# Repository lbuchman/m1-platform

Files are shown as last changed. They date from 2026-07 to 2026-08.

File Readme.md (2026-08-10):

# M1 Platform

This repository is the root repository for the M1 embedded manufacturing test platform.

The root repository does not replace the component repositories. It documents and organizes them so the full platform can be cloned, set up, released, and recovered as one system.

## Top-Level Directory Structure

| Directory | Purpose |
| --- | --- |
| `artifacts/` | Build output (snaps, firmware images, manifest) produced by `scripts/build.sh`. |
| `components/` | Independently git-tracked component repos (`m1tfc`, `m1testBoardFw`, `acm-testboard-fw`, `stm32mp1-baremetal`, `m1-rest-server`, `m1-operator-ui`), populated via `scripts/clone-components.sh`. |
| `documentation/` | Controlled documentation baseline: architecture, hardware, assembly, operations, validation, sustainment, and cloud-deployment docs. |
| `provision-new-pc/` | Fixture PC provisioning and deployment tooling (`setup.sh`, `deploy.sh`, required inputs). |
| `scripts/` | Automation scripts: build, clone/update components, publish firmware, program Teensy boards. |

## Build PC Software Requirements

Ubuntu is required for development — other OSes (macOS, Windows, WSL, other Linux distros) are not
supported for building or running this platform's build/deploy tooling. Ubuntu 26.04 LTS is recommended.
See [documentation/BuildPC/Readme.md](documentation/BuildPC/Readme.md) for the exact release and required
software: Ubuntu packages, Node, Snapcraft, VS Code/PlatformIO, and the Arm toolchain.

## Build the Platform

From the repository root, after cloning components (see [Bootstrap Components](#bootstrap-components) below):

```bash
./scripts/build.sh build
```

Builds all firmware and all snaps, staging artifacts in `artifacts/` alongside `manifestFile.json`.

## Fixture PC Deployment Guide

See [provision-new-pc/Readme.md](provision-new-pc/Readme.md) for fixture deployment instructions, required inputs, examples, and troubleshooting.

## Firmware Publishing

See [scripts/publish-fw.md](scripts/publish-fw.md) for publishing firmware/snap artifacts to Azure Blob storage.

## Bootstrap Components

After cloning the platform root, populate `components/` with split repositories:

```bash
./scripts/clone-components.sh
```

See [scripts/Readme.md](scripts/Readme.md) for update/dry-run options and the rest of the automation scripts.

## Components

| Component | Repo | Local Path | Purpose |
| --- | --- | --- | --- |
| M1TFC | `git@github.com:lbuchman/m1tfc.git` | `components/m1tfc` | Fixture CLI, ICT, functional tests, hardware orchestration |
| M1 fixture Teensy firmware | `git@github.com:lbuchman/m1testBoardFw.git` | `components/m1testBoardFw` | Teensy 4.1 firmware for M1 fixture boards |
| ACM test board firmware | `git@github.com:lbuchman/acm-testboard-fw.git` | `components/acm-testboard-fw` | PlatformIO Teensy firmware for ACM test board, aligned to the `redDiamondsFixture/teensy` skeleton |
| STM32MP1 bare-metal ICT firmware | `git@github.com:lbuchman/stm32mp1-baremetal.git` | `components/stm32mp1-baremetal` | Bare-metal STM32MP1 firmware for ICT, including SDRAM test coverage unavailable when Linux owns the target |
| REST server | `git@github.com:lbuchman/m1-rest-server.git` | `components/m1-rest-server` | REST API around fixture commands and status |
| Operator UI | `git@github.com:lbuchman/m1-operator-ui.git` | `components/m1-operator-ui` | React production/debug operator interface |

## Production Snaps

These platform components are production snap packages:

| Component | Local Path | Snap Packaging |
| --- | --- | --- |
| M1TFC | `components/m1tfc` | `components/m1tfc/snap/snapcraft.yaml` |
| REST server | `components/m1-rest-server` | `components/m1-rest-server/snap/snapcraft.yaml` |
| Operator UI | `components/m1-operator-ui` | `components/m1-operator-ui/snap/snapcraft.yaml` |

Production snap packages should use Node 24.

## Platform Snap Builds

See [scripts/Readme.md](scripts/Readme.md#buildsh-usage) for full `build.sh` firmware/snap target usage and options.

## Fast Smoke Test Checklist

Run the post-install and pre-release smoke checks in:

- [documentation/Validation/fast-smoke-test-checklist.md](documentation/Validation/fast-smoke-test-checklist.md)

## Platform Firmware Builds

See [scripts/Readme.md](scripts/Readme.md#buildsh-usage) for full `build.sh` firmware/snap target usage and options.

### Program Teensy Boards

Upload prebuilt firmware from `artifacts/` to a Teensy board over USB with
`scripts/prog-teensy.sh`:

```bash
./scripts/prog-teensy.sh acm     # upload artifacts/acmfirmware.hex to the ACM test board
./scripts/prog-teensy.sh m1tb    # upload artifacts/m1firmware.hex to the M1 fixture board
```

This script does not build firmware; run `scripts/build.sh build acm` or
`scripts/build.sh build fixture` first to refresh the artifact. Recheck the
connected board identity before programming.

### STM32MP1 ICT Firmware

See [documentation/BuildPC/STM32MP1-ICT-FIRMWARE.md](documentation/BuildPC/STM32MP1-ICT-FIRMWARE.md) for build requirements and FSBL build/output details.

## Repository Layout

- Repository root: this directory.
- Component repositories: `components/` (relative to repository root), populated by `scripts/clone-components.sh`.

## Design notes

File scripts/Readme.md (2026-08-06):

# Scripts

Automation used to bootstrap, build, program, and publish the M1 platform.

| Script | Purpose |
| --- | --- |
| `build.sh` | Builds firmware (`acm`, `fixture`, `stm32mp1`) and platform Snaps (`m1tfc`, `m1-rest-server`, `m1-operator-ui`, `m1-fixture-agent`); stages artifacts and `manifestFile.json` in `artifacts/`. |
| `check-dirty-components.sh` | Reports Git cleanliness (clean/dirty/not-git) for each repo under `components/`. |
| `clone-components.sh` | Clones all split `components/*` repos via SSH (falls back to HTTPS); `--update` fast-forwards existing clones. |
| `install-snaps.sh` | Copies built snaps from `artifacts/` to a remote host via `scp` and installs them there via `ssh`. |
| `installstm32fsbl.sh` | Copies the built STM32MP1 ICT FSBL (`artifacts/stm32mp1_fsbl.stm32`) to `/var/m1mtf/fsbl.stm32` on a remote host. |
| `prog-teensy.sh` | Uploads prebuilt Teensy firmware (`acmfirmware.hex` or `m1firmware.hex`) to a board over a remote host's `teensy_loader_cli`. |
| `publish-fw.sh` | Uploads firmware, snap, and manifest artifacts from `artifacts/` to Azure Blob storage. |
| `update-components.sh` | Fast-forward pulls already-cloned `components/*` repos without re-cloning; supports `--component` and `--dry-run`. |

Run any script with `-h`/`--help` (where supported) for full usage and options.

## build.sh Usage

Build firmware and stage artifacts:

```bash
./scripts/build.sh build acm        # build ACM firmware
./scripts/build.sh build fixture     # build M1 fixture Teensy firmware
./scripts/build.sh build stm32mp1    # build STM32MP1 ICT FSBL
./scripts/build.sh build firmware    # build all firmware components
./scripts/build.sh build all         # build all firmware and all snaps
```

Build snap packages the same way:

```bash
./scripts/build.sh build m1tfc            # build m1tfc snap only
./scripts/build.sh build m1-rest-server   # build m1-rest-server snap only
./scripts/build.sh build m1-operator-ui   # build m1-operator-ui snap only
./scripts/build.sh build m1-fixture-agent # build m1-fixture-agent snap only
./scripts/build.sh build snaps            # build all snaps
```

Build artifacts are copied to `artifacts/` directly, alongside a
`build-manifest.txt` containing the source commit and dirty/clean state.
Use `--output-dir PATH` to select another artifact directory, `--update` for
fast-forward-only git updates from current remotes, or `--dry-run` to inspect
a command without building, installing, or programming hardware.

`build fixture` compiles `components/m1testBoardFw` with PlatformIO
(`pio run --environment teensy41`) and stages the resulting `.hex` as
`artifacts/m1firmware.hex`.

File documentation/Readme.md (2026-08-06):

# EVM Platform Documentation v1.2

This package is the controlled documentation baseline for the M1/MNPlus Unified Engineering, Validation and Manufacturing Platform (EVM).

## Included formal documents

- EVM Platform Overview
- EVM Platform Capabilities
- EVM Hardware Architecture
- Engineering vs Production Configurations
- M1 Test Board Hardware Specification
- ACM Controller Test Board Hardware Specification
- Production Fixture Assembly Guide
- EVM Twenty-Year Sustainment Plan
- M1 Operator UI Guide (`Operations/`)
- Fast Smoke Test Checklist (`Validation/`)
- Cloud deployment documentation, including board firmware storage / Azure `firmware` container contents (`Cloud-Deployment/`)

## Included engineering sources

- EVM architecture diagram image and draw.io source (`Architecture/Platform/Source-Diagrams/`)
- Current fixture design review diagram (`Architecture/Platform/Source-Diagrams/mnplus_design_review_v3.drawio`)
- Engineering bench photograph, production fixture photographs, and all document-extracted images (`Images/`)
- M1 Test Board and ACM Controller Test Board schematic PDFs (`Architecture/Hardware/*/Source-Schematics/`)
- M1-3200 and MNPlus-V3 UUT (product-under-test) reference schematics (`Architecture/Hardware/UUT-Reference/`)
- Full architecture authoring context (`Architecture/Platform/Context/`)

## Repository layout

```text
documentation/
├── Architecture/
│   ├── Platform/
│   │   ├── 01_EVM_Platform_Overview.md
│   │   ├── 02_EVM_Platform_Capabilities.md
│   │   ├── 03_EVM_Hardware_Architecture.md
│   │   ├── 04_Engineering_vs_Production_Configurations.md
│   │   ├── Context/            (full architecture authoring context)
│   │   └── Source-Diagrams/    (draw.io sources)
│   ├── Hardware/
│   │   ├── M1-Test-Board/                  (spec + Source-Schematics/)
│   │   ├── ACM-Controller-Test-Board/   (aka ACM Board; spec + Source-Schematics/)
│   │   └── UUT-Reference/                  (M1-3200, MNPlus-V3 product schematics)
│   ├── Firmware/    (reserved)
│   └── Software/    (reserved)
├── Assembly/        (Production Fixture Assembly Guide)
├── Manufacturing/   (reserved)
├── Operations/      (operator UI guide)
├── Validation/      (fast smoke test checklist)
├── Sustainment/     (Twenty-Year Sustainment Plan)
├── Cloud-Deployment/ (cloud deployment docs: Azure storage containers, and other cloud files used by the platform)
├── Interface-Control-Documents/  (reserved: pogo-pin maps, IDC interface spec, reader interfaces)
└── Images/          (all diagrams/photos/document-extracted images)
```

## Scope note

The current package covers platform, hardware, assembly, operations, validation, and sustainment documentation. Detailed firmware, software, manufacturing release, and interface-control documents have reserved repository locations for future development.

The production fixture is one implementation of the broader EVM platform. The engineering bench and production fixture use the same core architecture with different mechanical and interface layers.

`Interface-Control-Documents/` was named out in full (rather than the `ICD` abbreviation) to avoid confusion with `IDC` (Insulation Displacement Connector), a distinct, frequently referenced term in the same interface documents.

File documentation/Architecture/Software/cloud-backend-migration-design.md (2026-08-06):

# Factory Server Migration: Azure Blob Storage → Local On-Prem Server

## Goal

Replace the current Azure Blob Storage based system (`tfcroncli`/`m1client` on the fixture, `scripts/publish-fw.sh` for admins) with a **local, on-prem physical PC in the factory** ("Factory Server") that the team fully controls. This is a hard requirement, not just a preference: production lines must be **self-contained** and must keep running even if internet/cloud connectivity is down — nothing on the primary production path (logs, secrets, firmware updates, MAC allocation) may depend on reaching the internet. The new backend must:

1. Store logs, retrievable **by board serial number** (today only retrievable by date-prefix/fixture).
2. Store secrets, retrievable **by board serial number** (same limitation today).
3. Host firmware/software releases; fixtures poll and self-update (replaces the `firmware` blob container + `manifestFile.json`).
4. Centrally manage MAC address allocation (replaces the static, offline `STARTMAC` block-per-fixture formula in `setup.sh`).
5. Provide a web app to browse all of the above.
6. Run entirely on the factory LAN — Azure Blob Storage is retained only as an **off-site daily backup target** (disaster recovery), never on the critical path for production.
7. Keep test fixture PCs **stateless/thin clients** — since the Factory Server now owns the only database, fixtures no longer need a local database at all. Board test results, secrets, and MAC assignment are written directly and immediately to `m1-factory-hub` over the LAN instead of being staged in a local SQLite DB and synced later by cron.

## Naming

Recommended service name: **`m1-factory-hub`**. "Factory Server" refers to the physical on-prem PC (the hardware); `m1-factory-hub` is the Node/Express service that runs on it, following the existing `m1-<role>` naming convention (`m1-rest-server`, `m1-operator-ui`). "Hub" reflects its role as the single central point every fixture talks to for logs, secrets, firmware, and MAC allocation. Alternatives considered: `m1-mes-server` (accurate — this is effectively a small Manufacturing Execution System — but a less familiar term), `m1-depot` (evokes storage but undersells the MAC-allocation/coordination role). The rest of this doc uses `m1-factory-hub`.

## Current State (for reference)

| Concern | Current mechanism |
| --- | --- |
| Logs | Fixture cron (`m1client synclogs`) uploads `.txz` archives to `<product>-logs-<site>` Azure container. Retrieval only by date-prefix, no serial index. |
| Secrets | Fixture cron (`m1client syncsecrets`) uploads a CSV of RSA-encrypted, base32-encoded secrets to `<product>-secrets` container. |
| Firmware | Admin tool `scripts/publish-fw.sh` pushes files + `manifestFile.json` to `firmware` container; fixture cron (`m1client update`) polls and downloads. |
| DB backup | Fixture cron (`m1client backupdb`) uploads SQLite `tf.db` to `backup` container. |
| MAC addresses | `setup.sh` computes a static `58:FC:C8:%02X:%02X:%02X` block per fixture from `idx * 1_000_000`, seeded once into the local `UID` table at provisioning. No central registry, no collision detection. |

## `deployment` Container Contract (Azure Blob, current interim mechanism)

Manual firmware releases are staged in the `deployment` Azure Blob container ahead of the on-prem migration above. This container **MUST** contain, at minimum:

- `stm32mp15-lenels2-m1.txz` — M1 firmware image archive.
- `stm32mp15-lenels2-mnp.txz` — MNP firmware image archive.
- `manifestFile.json` — SAS URLs and SHA-512 hashes for both archives above (`m1firmware` / `mnpfirmware` entries).

Each `.txz` archive **MUST** contain, at its root, a `VERSION` file — plain text, exactly **1 line**, containing the Artifactory-reported build revision string. Example:

  ```
  1.0.16 179 09/22/23 02eef93c27 M1B SandboxHost-638309047983092644
  ```

  Format: `<version> <build number> <build date MM/DD/YY> <short commit sha> <product> <build host>`.

## Proposed Architecture

```mermaid
flowchart LR
    classDef fixture fill:#eef3ff,stroke:#3367d6,color:#1a237e;
    classDef vm fill:#fff6e8,stroke:#e65100,color:#5d3a00;
    classDef admin fill:#eaf7ec,stroke:#2e7d32,color:#1b3d1f;
    classDef cloud fill:#f3e8ff,stroke:#6a1b9a,color:#3a1a5d;

    subgraph LAN["Factory LAN (no internet dependency for production)"]
        subgraph FIX["Test Fixture PCs (stateless — no local DB)"]
            MTFC["m1tfc<br/>(test execution — calls Hub in real time\nfor boards / secrets / mac allocate)"]:::fixture
            TFC["tfcroncli / m1client<br/>(cron: update only)"]:::fixture
            SSH1["autossh"]:::fixture
        end

        subgraph SRV["Factory Server (on-prem PC) — m1-factory-hub"]
            API["m1-factory-hub (Express REST API)"]:::vm
            MYSQL[("MySQL: boards, logs, secrets,\nmac_allocations, firmware_releases")]:::vm
            FS[("Filesystem: /data/logs, /data/firmware,\n/data/secrets, /data/backups")]:::vm
            WEB["Web dashboard (React)"]:::vm
            BKUP["daily backup job<br/>(mysqldump + tar, conditional)"]:::vm
            SSH2["autossh"]:::vm
            API --- MYSQL
            API --- FS
            WEB -->|REST| API
            BKUP --- MYSQL
            BKUP --- FS
        end

        subgraph ADMIN["Engineer workstation"]
            CLI["scripts/publish-fw.sh<br/>publish firmware/snap artifacts"]:::admin
        end

        MTFC -->|HTTPS + API key, LAN only\nreal-time board/secret/mac calls| API
        TFC -->|HTTPS + API key, LAN only\nfirmware update poll| API
        CLI -->|HTTPS + API key, LAN only| API
    end

    AZURE[("Azure Blob Storage<br/>off-site DR backup only")]:::cloud
    RELAY[("External relay server")]:::cloud

    BKUP -.->|daily, only if changed,\nvia existing access key| AZURE
    SSH1 -.->|reverse SSH tunnel\n(remote support access)| RELAY
    SSH2 -.->|reverse SSH tunnel\n(remote support access)| RELAY
```

The reverse-SSH-via-relay pattern already exists on every test fixture PC (`autossh` service, restarted on boot via cron — see `setup.sh`) purely for remote engineering/support access; it carries no production data and is independent of the `m1-factory-hub` REST path and the Azure backup path. The Factory Server should get the same `autossh` service for the same reason (remote troubleshooting), not because production depends on it.

Because fixtures now depend on `m1-factory-hub` being reachable *during* live test execution (not just for periodic batch sync), the Factory Server effectively becomes a production-critical LAN service. This is a reasonable trade for the simplicity gained (see Open Decisions for reliability/retry considerations).

## Factory Server Components

### Database: MySQL

MySQL (InnoDB) replaces Postgres per your preference. Suggested schema:

```sql
CREATE TABLE boards (
  serial          VARCHAR(64) PRIMARY KEY,
  product         VARCHAR(32) NOT NULL,
  mac             VARCHAR(17) UNIQUE,
  fixture         VARCHAR(32),
  status          VARCHAR(32) DEFAULT 'active',
  created_at      DATETIME DEFAULT CURRENT_TIMESTAMP,
  updated_at      DATETIME DEFAULT CURRENT_TIMESTAMP ON UPDATE CURRENT_TIMESTAMP
) ENGINE=InnoDB;

CREATE TABLE logs (
  id              BIGINT AUTO_INCREMENT PRIMARY KEY,
  board_serial    VARCHAR(64) NOT NULL,
  fixture         VARCHAR(32) NOT NULL,
  file_path       VARCHAR(512) NOT NULL,
  file_hash       CHAR(128) NOT NULL,
  size_bytes      BIGINT,
  uploaded_at     DATETIME DEFAULT CURRENT_TIMESTAMP,
  FOREIGN KEY (board_serial) REFERENCES boards(serial),
  INDEX idx_logs_serial (board_serial)
) ENGINE=InnoDB;

CREATE TABLE secrets (
  board_serial      VARCHAR(64) PRIMARY KEY,
  uid               VARCHAR(64) NOT NULL,
  encrypted_secret  TEXT NOT NULL,
  fixture           VARCHAR(32),
  synced_at         DATETIME DEFAULT CURRENT_TIMESTAMP,
  FOREIGN KEY (board_serial) REFERENCES boards(serial)
) ENGINE=InnoDB;

CREATE TABLE mac_allocations (
  mac             VARCHAR(17) PRIMARY KEY,
  board_serial    VARCHAR(64) UNIQUE,
  fixture         VARCHAR(32),
  status          ENUM('available','reserved','assigned') DEFAULT 'available',
  allocated_at    DATETIME NULL
) ENGINE=InnoDB;

CREATE TABLE firmware_releases (
  id              BIGINT AUTO_INCREMENT PRIMARY KEY,
  version         VARCHAR(32) NOT NULL,
  product         VARCHAR(32) NOT NULL,
  filetype        VARCHAR(16) NOT NULL,
  filename        VARCHAR(255) NOT NULL,
  file_hash       CHAR(128) NOT NULL,
  published_at    DATETIME DEFAULT CURRENT_TIMESTAMP,
  UNIQUE KEY uniq_release (version, product, filetype)
) ENGINE=InnoDB;
```

Note: no `db_backups` table is needed anymore — there is no per-fixture local database left to back up. The `boards` table itself (with test-result columns such as `ict_passed`, `functional_passed`, `flash_programmed`, mirroring today's local `records` table) *is* the durable store now, and it lives only on the Factory Server, covered by the single off-site backup job described below.

`mysql2` (Node driver, promise support built in) on the Factory Server only — fixtures never talk to MySQL directly, only through the `m1-factory-hub` REST API.

### File storage

Plain filesystem on the Factory Server (`/data/logs/<serial>/...`, `/data/firmware/<product>/<version>/...`, `/data/backups/<fixture>/...`), indexed by the MySQL rows above. No need for MinIO/S3-compatible layers at this scale — it adds an extra moving part for no real benefit here.

### REST API (`m1-factory-hub`, Express — new component, e.g. `components/m1-factory-hub`)

| Method | Endpoint | Purpose |
| --- | --- | --- |
| POST | `/api/logs` | Fixture uploads a log archive tagged with `serial`, `fixture`, timestamp. |
| GET | `/api/logs?serial=` | List/download logs for a board. |
| POST | `/api/secrets` | Fixture uploads an (already RSA-encrypted) secret record for a board. |
| GET | `/api/secrets?serial=` | Retrieve a board's secret record. |
| POST | `/api/mac/allocate` | Fixture/`setup.sh` requests the next free MAC; server allocates atomically and marks it `assigned`. |
| GET | `/api/mac?serial=` | Look up a board's assigned MAC. |
| GET | `/api/firmware/manifest?product=` | Replaces Azure `manifestFile.json` fetch — fixture's `update` command polls this. |
| GET | `/api/firmware/:file` | Download a firmware/snap file. |
| POST | `/api/firmware` | Admin publishes a new release (replaces `scripts/publish-fw.sh`). |
| POST | `/api/boards` | `m1tfc` records/updates a board's test result in real time (ICT/functional pass, flash programmed, etc.) — replaces the local `records` table. |
| GET | `/api/boards?serial=` | Look up a board's current test/status record (e.g., to resume or re-test). |
| GET | `/health` | Health check (same base-response contract pattern already used in `m1-rest-server`). |

### Auth

The Factory Server sits on the same factory LAN as the fixtures, so there's no public domain/Let's Encrypt concern here. Recommended default: HTTPS with a self-signed cert (or a small internal CA) issued once and distributed to fixtures via `setup.sh` (`update-ca-certificates`), plus a per-fixture API key issued at provisioning time, sent as `Authorization: Bearer <key>`. TLS is still worthwhile even on a trusted LAN (defense in depth for the secrets endpoint); plain HTTP is not recommended. A static hostname/IP for the Factory Server (e.g. `factory-server.local` via mDNS, or a fixed LAN IP) should be baked into fixture config at provisioning time.

### Web app

Reuse the existing pattern (`m1-operator-ui`: React/Vite, talking to an Express REST layer) rather than a new stack: search by board serial → logs, secret-sync status, MAC, firmware history; plus an admin view for firmware releases and the MAC pool. Runs on the Factory Server itself, accessible from any PC on the factory LAN.

## Off-Site Backup to Azure Blob Storage

Azure Storage is **not** part of the operational path anymore — it is only a daily, best-effort, off-site disaster-recovery copy, using the access key already held. Production continues normally even if this fails or if internet access is temporarily down.

- **What**: a `mysqldump` of the MySQL database + a tarball of `/data` (logs/secrets/firmware/backups), run once daily on the Factory Server itself (not on individual fixtures).
- **Conditional upload**: track a watermark (e.g. `MAX(updated_at)` across the relevant tables, or a hash of the dump) from the last successful backup; skip the upload entirely if nothing changed since then, to avoid needless daily transfers.
- **Isolation from the app code**: implement this as a standalone ops script (bash + `mysqldump` + `azcopy` or `az storage blob upload-batch`), run via a systemd timer/cron on the Factory Server — kept entirely separate from the Node REST API. This keeps the application code itself fully vendor-neutral; only this one backup script touches Azure, using the existing storage account access key (e.g. a dedicated `factory-backup` container).
- **Restore path**: download the latest dump/tarball from Azure and restore `mysqldump` + extract `/data` onto a replacement Factory Server.

## Remote Support Access (autossh reverse SSH)

Separate from both the production data path and the Azure backup path: every test fixture PC already runs an `autossh` service that opens a reverse SSH tunnel to an external relay server, giving engineers remote shell access for troubleshooting (already implemented, restarted on boot via the existing `@reboot sleep 120 && systemctl restart autossh` cron entry in `setup.sh`). The Factory Server should run the same `autossh` service against the same relay, for the same reason — remote support access if on-site visits aren't practical. This channel carries no logs/secrets/firmware/MAC traffic and has no bearing on the self-contained-production requirement; it's purely an admin convenience.

## Test Fixture PC Software Changes

The fixture host already runs Ubuntu Server + Node.js (via the `m1client`/`tfcroncli` snap) and needs no new system-level packages for this migration — just dependency and config changes:

| Area | Change |
| --- | --- |
| `tfcroncli/app/package.json` | Remove `azure-storage`, `@azure/storage-blob`. No new HTTP dependency needed — Node 20+ (already the baseline per `m1-rest-server`'s `engines`) has built-in `fetch`, `FormData`, and `Blob`, sufficient for multipart uploads/downloads. |
| `azureOp.js` | Replaced by a new `httpOp.js` with the same exported function shapes (`syncFiles`, `checkFilesHash`, `getHash512FromFile` — the hash helper is pure local logic and doesn't change) so `m1client.js`'s command bodies barely change, just the transport underneath. |
| `better-sqlite3` (and the local `tf.db`/`records`/`UID`/`Perm` schema) | **Removed entirely.** No local database on the fixture at all — `m1tfc` calls `m1-factory-hub` directly for board test-result records, secret submission, and MAC allocation instead of writing to local SQLite and syncing later. This also drops a native module (`better-sqlite3` requires compilation) from every fixture install. |
| `m1tfc` (test executor, `components/m1tfc`) | Bigger change than `tfcroncli`: the code that used to read/write the local `records`/`UID` tables now calls `m1-factory-hub`'s `/api/boards`, `/api/secrets`, and `/api/mac/allocate` synchronously during the test sequence. Needs basic retry/backoff around these calls since the Hub is now a live dependency during test execution, not just a periodic sync target. |
| `crypto` (RSA), `winston`, `fs-extra`, `glob`, `mkdirp`, `date-and-time`, `lodash` | Unchanged — encryption and logging stay exactly as they are today. |
| TLS trust | The Factory Server will use a self-signed cert or small internal CA (no public domain on a factory LAN). `setup.sh` needs a step to install that CA into each fixture's system trust store (`update-ca-certificates`). |
| MySQL client | **Not needed** on the fixture — all DB access is server-side only, fixtures only ever call the REST API. |
| cron schedule | `tfcroncli`/`m1client` shrinks to just `update` (firmware polling). `synclogs`, `syncsecrets`, `backupdb` and their log-retention `find`/`delete` jobs are all removed — there's no local state left to batch-sync since logs/secrets/board records now push in real time from `m1tfc` itself. |
| `setup.sh` MAC provisioning | Removed entirely — no `STARTMAC`/`idx * 1_000_000` block calculation, no local `UID` table to seed. MACs are requested per-board, at programming time, directly from `m1-factory-hub`. |
| Package footprint | Net reduction — dropping the Azure SDKs *and* `better-sqlite3` removes two fairly heavy/native dependency trees from every fixture install. |

## Migration Plan (staged)

1. Procure/set up the Factory Server (physical PC on the factory LAN) with MySQL + `m1-factory-hub` + filesystem storage, and the same `autossh` remote-support service already used on fixtures; implement and test all endpoints above in isolation.
2. Add `httpOp.js` to `tfcroncli` for firmware `update` (behind the same interface as `azureOp.js`), and add the direct `m1tfc` → `m1-factory-hub` calls for boards/secrets/mac-allocate (replacing the local `records`/`UID` table reads/writes in `m1tfc`). Update `config.json`/`setup.sh` to point at the Factory Server's LAN address. Pilot on one fixture before wider rollout.
3. Cut fixtures over fixture-by-fixture (`update` retargeted; local SQLite removed; `m1tfc` now calls the Hub directly).
4. Move MAC allocation to the central API last — highest process risk. Consider registering existing static allocations into `mac_allocations` first (for visibility) before fixtures start requesting *new* MACs from the pool.
5. Stand up the daily conditional Azure backup job on the Factory Server (independent ops script, see below).
6. Historical Azure data and existing local `tf.db` records: import into the Factory Server's MySQL as a one-time migration, or leave archived — no need to block the cutover on this.

## Open Decisions

- **Auth model**: API key over HTTPS with a self-signed/internal CA (recommended default above), or mutual TLS client certs?
- **Factory Server addressing**: fixed LAN IP vs. mDNS/local hostname — which is already standard practice on this network?
- **MAC cutover**: keep the static per-fixture formula as an offline fallback (e.g. if the Factory Server is briefly down for maintenance), or make Factory Server reachability a hard requirement for `setup.sh`/provisioning to complete?
- **Historical data**: import existing Azure blob data (and existing local `tf.db` records) into the new system, or leave archived as-is?
- **Backup retention**: how many days/versions of the daily Azure backup to retain before pruning older ones?
- **Test-time reliability**: since fixtures now depend on `m1-factory-hub` being up *during* live testing (no local DB fallback), what retry/backoff policy should `m1tfc` use on a transient failure, and should the Factory Server run on a UPS/have any redundancy given it's now production-critical?

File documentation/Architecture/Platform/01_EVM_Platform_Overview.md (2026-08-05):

**EVM Platform Overview**

*Unified Engineering, Validation and Manufacturing Platform*

Version 1.0 \| July 25, 2026\
Owner: Leo Buchman\
Status: Initial controlled draft

  -------------------------------------------------------------------------------------------
  Document Type                       Platform Overview
  ----------------------------------- -------------------------------------------------------
  Platform                            M1/MNPlus EVM

  Scope                               Hardware / architecture

  Source Baseline                     Schematics, platform diagram, physical configurations
  -------------------------------------------------------------------------------------------

# 1. Purpose

The M1/MNPlus EVM is a reusable platform that supports engineering development, hardware-in-the-loop validation, QA, manufacturing, provisioning, recovery, failure analysis, and technical support. The production fixture is one deployment of the platform; the underlying architecture is broader than a product-specific tester.

# 2. Platform Outcomes

- Common engineering and production infrastructure

- Repeatable hardware, firmware, and software validation

- Serial, USB, Ethernet, RS-485, OSDP, Wiegand, and PoE test access

- Programming, provisioning, recovery, and regeneration

- Reusable M1 and ACM simulation subsystems

- Cloud-connected updates, diagnostics, logs, secrets, and remote support

# 3. System Architecture

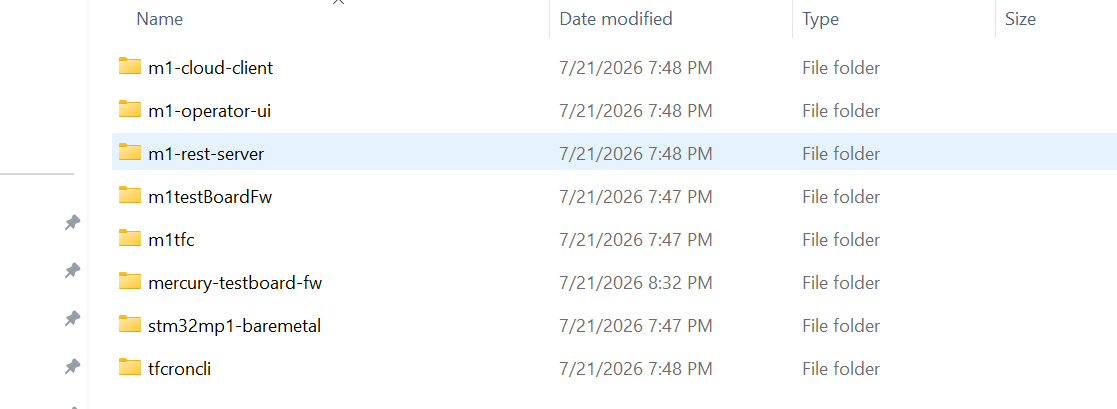
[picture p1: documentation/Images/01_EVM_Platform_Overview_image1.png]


*Figure 1 - EVM platform architecture (current system-level view)*

# 4. Major Subsystems

  ---------------------------------------------------------------------------------------------------------------------------------------------------
  **Subsystem**                       **Primary responsibility**
  ----------------------------------- ---------------------------------------------------------------------------------------------------------------
  Headless PC                         React operator UI, REST control services, Node.js test execution, cloud and recovery services

  M1 Test Board                       M1-scope control, programming, recovery, measurements, boot selection, and product interface

  ACM Controller Test Board       ACM/ACM simulation: readers, supervised inputs, relay/output validation, tamper and power-fault functions

  SAM-E Ethernet Subsystem            Local three-port Ethernet switching for test and PoE paths

  Power / PoE Subsystem               12.5 V and 5 V fixture rails plus switched 48 V PoE delivery

  Product Interface                   Direct IDC/terminal-block engineering access or product-specific production plate and pogo-pin mapping
  ---------------------------------------------------------------------------------------------------------------------------------------------------

# 5. Supported Lifecycle Uses

  -------------------------------------------------------------------------------------------------------------------
  **Lifecycle phase**                 **Representative uses**
  ----------------------------------- -------------------------------------------------------------------------------
  Engineering                         Bring-up, firmware/software development, debug, direct signal access

  QA / Validation                     Automated regression, HIL, serial and Ethernet testing

  Manufacturing                       Programming, provisioning, configuration, qualification, pass/fail validation

  Sustaining / Support                Recovery, regeneration, failure analysis, diagnostics, remote assistance
  -------------------------------------------------------------------------------------------------------------------

# 6. Engineering and Production Deployments

The platform uses the same core architecture in two physical configurations. The engineering configuration favors direct access and flexibility. The production configuration favors repeatability, speed, and operator simplicity.

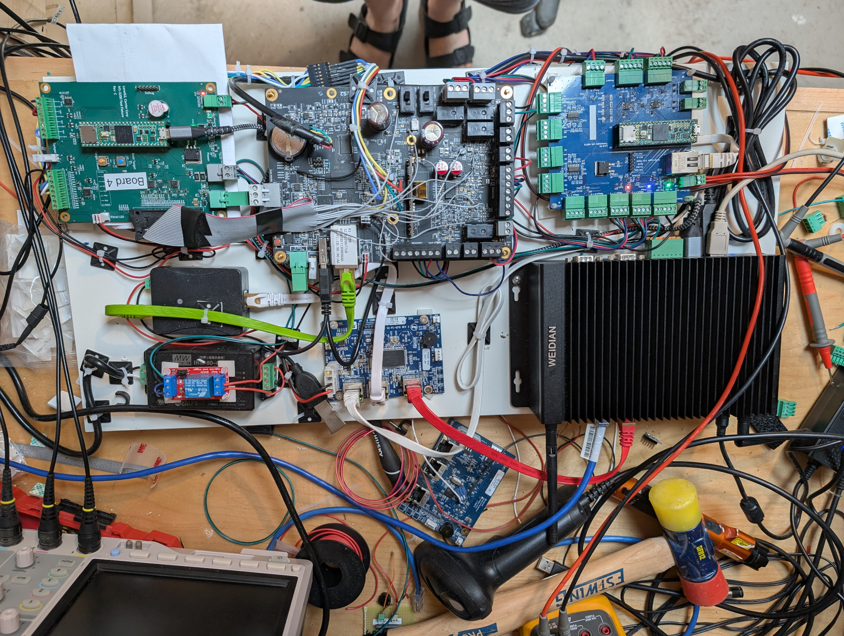
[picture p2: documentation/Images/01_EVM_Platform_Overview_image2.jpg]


*Figure 2 - Engineering bench configuration with direct terminal-block and board access*

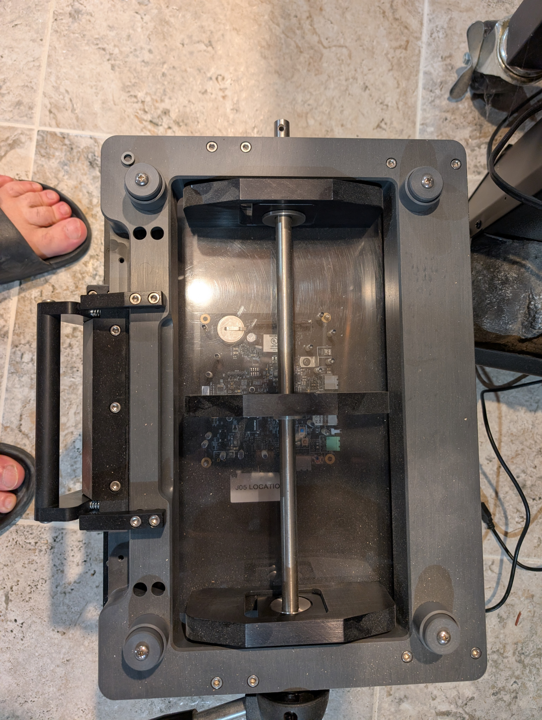
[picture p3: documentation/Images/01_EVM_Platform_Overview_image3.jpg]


*Figure 3 - Production fixture implementation with enclosed electronics and mechanical UUT interface*

# 7. Product Coverage

- M1 controller platform

- MNPlus platform, including the M1 and ACM functional scopes

- ACM controller families

- ACM door controllers

- ACM I/O expansion boards

- Elements end-to-end validation workflows

# 8. Document Map

- Platform Capabilities

- Hardware Architecture

- Engineering vs Production Configurations

- M1 Test Board Hardware Specification

- ACM Controller Test Board Hardware Specification

- Factory Production Fixture Assembly Guide

- Twenty-Year Sustainment Plan

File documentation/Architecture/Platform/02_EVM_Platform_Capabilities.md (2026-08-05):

**EVM Platform Capabilities**

*Capability baseline for engineering and manufacturing stakeholders*

Version 1.0 \| July 25, 2026\
Owner: Leo Buchman\
Status: Initial controlled draft

  -------------------------------------------------------------------------------------------
  Document Type                       Capability Specification
  ----------------------------------- -------------------------------------------------------
  Platform                            M1/MNPlus EVM

  Scope                               Hardware / architecture

  Source Baseline                     Schematics, platform diagram, physical configurations
  -------------------------------------------------------------------------------------------

# 1. Platform Capability Summary

- Unified Engineering, QA, Manufacturing, Recovery, and Technical Support Platform

- Hardware-in-the-Loop product validation and automation

- M1 and ACM functional simulation and validation

- Automated hardware, firmware, and software testing

- Ethernet, serial, USB, RS-485, OSDP, Wiegand, and PoE test infrastructure

- Firmware programming, provisioning, recovery, and regeneration

- Failure analysis, diagnostics, logs, and remote support

- React-based operator interface

- REST control services and Node.js automated test execution

- Common platform architecture supporting multiple products and product families

# 2. M1-Scope Capabilities

- M1 and MNPlus M1-subsystem validation

- Boot-target selection

- Target power control

- Serial-console and programming access

- Battery-related control and measurements

- Analog measurement and channel selection

- Tamper and product-interface access

- Direct IDC engineering connectivity

- Production pogo-pin connectivity through product-specific wiring

# 3. ACM / ACM-Scope Capabilities

- Dual OSDP reader simulation

- Dual Wiegand reader simulation

- Reader power, LED, and buzzer interaction

- Eight supervised-input simulation channels

- Relay/output activation validation

- Cabinet-tamper simulation

- Power-fault simulation

- ACM controller validation

- Door-controller validation

- I/O expansion-board validation

- End-to-end automated ACM ecosystem testing

# 4. Capability Versus Product Implementation

A product fixture exposes the subset of platform capabilities required by that product. M1 and MNPlus use different physical plates and pogo-pin maps. Broader ACM coverage requires a different plate, additional pogo-pin assignments, and additional wiring; the common ACM simulation electronics remain unchanged.

# 5. Known Capability Boundaries

- Exact supervised-input states must be confirmed from firmware and validation definitions

- Exact USB flash-drive use must be documented from implementation

- Product-specific pin maps belong in controlled ICDs and assembly drawings

- Detailed software, firmware, and operational procedures are separate documents

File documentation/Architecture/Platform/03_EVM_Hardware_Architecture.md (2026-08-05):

**EVM Hardware Architecture**

*System-level hardware decomposition and interfaces*

Version 1.0 \| July 25, 2026\
Owner: Leo Buchman\
Status: Initial controlled draft

  -------------------------------------------------------------------------------------------
  Document Type                       Hardware Architecture
  ----------------------------------- -------------------------------------------------------
  Platform                            M1/MNPlus EVM

  Scope                               Hardware / architecture

  Source Baseline                     Schematics, platform diagram, physical configurations
  -------------------------------------------------------------------------------------------

# 1. Scope

This document defines the physical hardware architecture of the EVM. Detailed software behavior, firmware internals, and operating procedures are excluded except where needed to explain interfaces.

# 2. Architecture Diagram



*Figure 1 - EVM hardware architecture*

# 3. Power Architecture

  ----------------------------------------------------------------------------------------------------------------
  **Source**              **Destination**                                 **Function**
  ----------------------- ----------------------------------------------- ----------------------------------------
  120 VAC                 12.5 V / 5 V supply                             Fixture/test electronics power

  12.5 V rail             M1 Test Board and associated test electronics   Controller and product-interface power

  5 V rail                SAM-E three-port Ethernet switch                Network subsystem power

  120 VAC                 48 V supply                                     PoE power source

  48 V supply             48 V relay                                      Controlled PoE enable path

  48 V relay              PoE injector                                    Switched 48 VDC

  PoE injector            UUT through product interface                   Ethernet plus power
  ----------------------------------------------------------------------------------------------------------------

# 4. Network and Service Architecture

- Headless PC provides Ethernet and USB control paths

- SAM-E provides local Ethernet switching

- ACM Controller Test Board participates in network-based testing

- PoE injector combines Ethernet and controlled 48 VDC

- USB hub exposes Teensy serial, DFU, and service-console paths

- Serial-based testing is a first-class validation path alongside Ethernet

# 5. Hardware Subsystem Responsibilities

  ---------------------------------------------------------------------------------------------------------------------------------------------------------------------
  **Subsystem**                       **Responsibilities**
  ----------------------------------- ---------------------------------------------------------------------------------------------------------------------------------
  M1 Test Board                       M1-scope control, target power, boot selection, measurements, programming/recovery, direct IDC and production interface support

  ACM Controller Test Board       Reader simulation, supervised-input simulation, relay/output validation, tamper/power-fault simulation

  SAM-E                               Three-port Ethernet switching and test-network distribution

  Fixture mechanics                   Product registration, compression, repeatable pogo-pin engagement, operator safety

  Engineering interface               Terminal blocks, direct IDC, accessible debug and service connections
  ---------------------------------------------------------------------------------------------------------------------------------------------------------------------

# 6. Safety and Review Items

- Define 48 V relay default and fail-safe state

- Document fuse/protection ratings and grounding

- Define maximum currents for all power rails

- Document connector keying and prevention of incorrect assembly

- Define initial power-up and acceptance measurements

# 7. Source References

- M1 Test Board schematic: Architecture/Hardware/M1-Test-Board/Source-Schematics/M1_Test_Board_Schematic.pdf

- ACM Controller Test Board schematic: Architecture/Hardware/ACM-Controller-Test-Board/Source-Schematics/ACM_Controller_Test_Board_Schematic.pdf

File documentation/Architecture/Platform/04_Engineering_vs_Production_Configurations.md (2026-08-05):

**Engineering vs Production Configurations**

*Two deployments of the same EVM architecture*

Version 1.0 \| July 25, 2026\
Owner: Leo Buchman\
Status: Initial controlled draft

  -------------------------------------------------------------------------------------------
  Document Type                       Configuration Description
  ----------------------------------- -------------------------------------------------------
  Platform                            M1/MNPlus EVM

  Scope                               Hardware / architecture

  Source Baseline                     Schematics, platform diagram, physical configurations
  -------------------------------------------------------------------------------------------

# 1. Core Principle

The engineering bench and production fixture are not different products. Both use the same platform architecture and differ primarily in interface, mechanics, wiring, access, and workflow.

# 2. Engineering Bench Configuration



*Figure 1 - Engineering bench configuration*

- Open assembly with direct board visibility

- Terminal blocks for signal access

- Direct IDC connection where appropriate

- No production enclosure required

- Supports development, bring-up, experimentation, debug, and failure analysis

- Prioritizes flexibility and signal visibility

# 3. Production Fixture Configuration

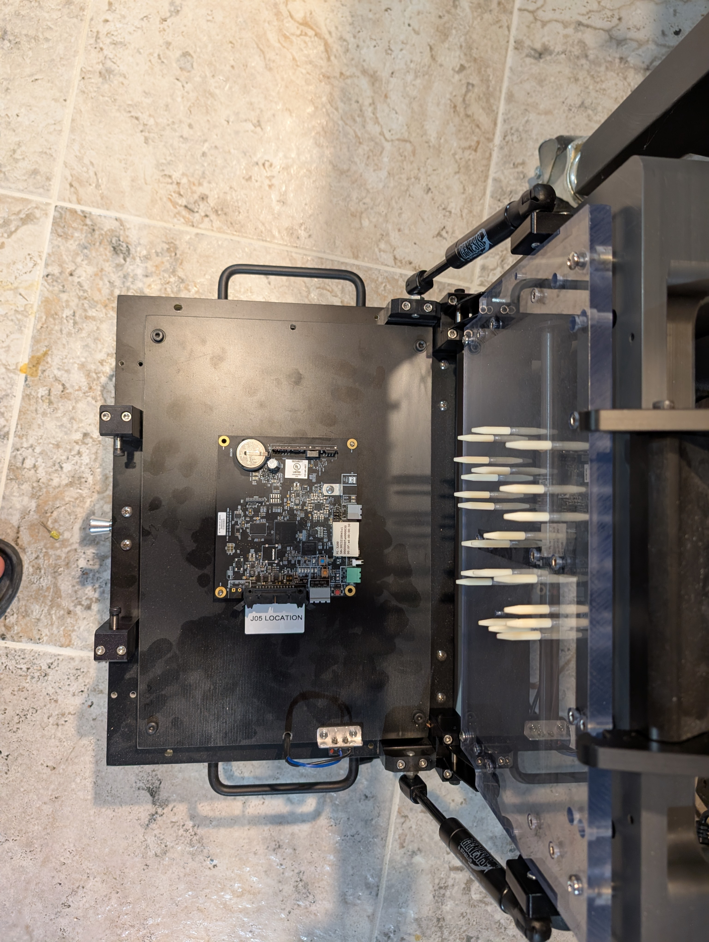
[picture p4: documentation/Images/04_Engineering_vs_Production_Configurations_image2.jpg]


*Figure 2 - Production mechanical fixture and product nest*

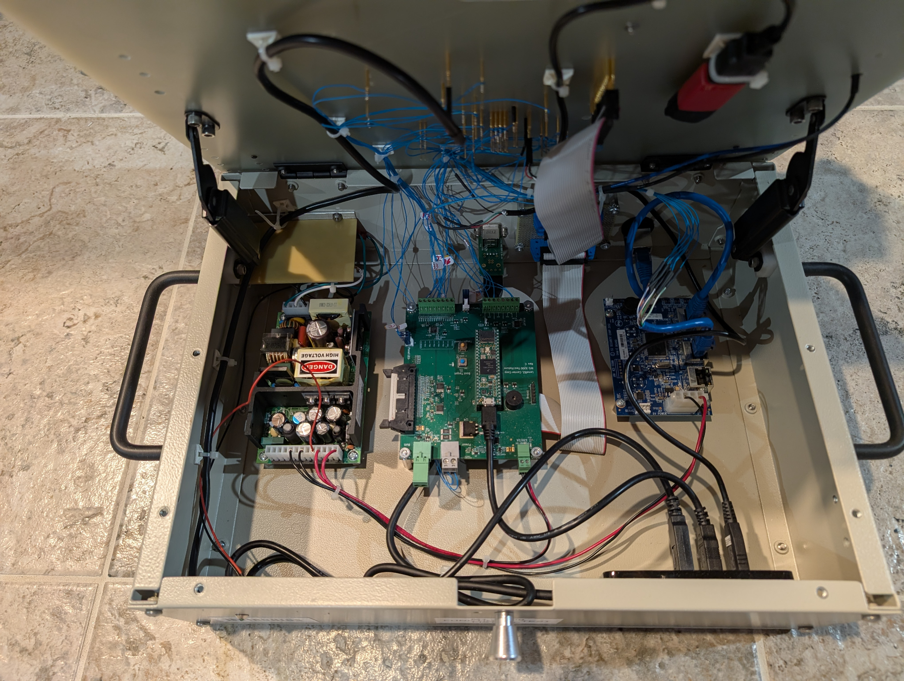
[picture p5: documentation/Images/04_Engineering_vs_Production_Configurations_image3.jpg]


*Figure 3 - Production fixture electronics and wiring*

- Enclosed electronics and controlled mechanical assembly

- Product-specific plate and pogo-pin map

- Lever-actuated repeatable engagement

- Operator status indication

- Automated programming, provisioning, and validation

- Prioritizes repeatability, throughput, safety, and simple operation

# 4. Product-Specific Variants

  -----------------------------------------------------------------------------------
  **Item**                        **M1**                      **MNPlus**
  ------------------------------- --------------------------- -----------------------
  Core EVM electronics            Common                      Common

  M1 Test Board                   Used                        Used for M1 scope

  ACM Controller Test Board   As required by test scope   Used for ACM scope

  Fixture plate                   M1-specific                 MNPlus-specific

  Pogo-pin map                    M1-specific                 MNPlus-specific

  Wiring                          Product-specific            Product-specific
  -----------------------------------------------------------------------------------

# 5. Configuration Control

- Each production plate requires a controlled drawing and revision

- Pogo-pin maps must be versioned

- Harness/wiring drawings must identify the supported UUT revision

- Engineering direct-connect configurations should document IDC pinout and bench wiring

- Factory Acceptance Test must reference the exact configuration baseline

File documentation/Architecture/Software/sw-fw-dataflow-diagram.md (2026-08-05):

# SW / FW Data Flow and Top-Level Architecture

This diagram shows the top-level data flow across the fixture's software and firmware components, with the UUT (unit under test) at the top. The fixture interface boards sit between the PC and the UUT since that is the actual signal path (PC commands the boards, boards drive the UUT); this keeps every arrow a short, uncrossed hop instead of long lines looping back over each other.

```mermaid
flowchart BT
    classDef pc fill:#eef3ff,stroke:#3367d6,color:#1a237e;
    classDef fixfw fill:#fff6e8,stroke:#e65100,color:#5d3a00;
    classDef uut fill:#eaf7ec,stroke:#2e7d32,color:#1b3d1f;

    subgraph PC["PC Ubuntu 26.04 server"]
        direction LR
        UI["m1-operator-ui"]:::pc
        REST["m1-rest-server"]:::pc
        TFC["m1tfc"]:::pc
        UI -->|REST| REST -->|dispatch| TFC
    end

    M1FW["m1testBoardFw"]:::fixfw
    ACMFW["acm-testboard-fw"]:::fixfw

    subgraph UUT["UUT - stm32mp1-baremetal FW or Linux"]
        direction LR
        UUT_SER["stm32mp1-baremetal<br/>UUT serial header"]:::uut
        UUT_BOOT["Boot mode pins<br/>Test points"]:::uut
        UUT_USB["USB/DFU"]:::uut
        UUT_ACM["Access control HW"]:::uut
    end

    TFC -->|Serial| M1FW
    TFC -->|Serial| UUT_SER
    TFC -->|UDP| ACMFW
    TFC -->|USB| UUT_USB

    M1FW -->|GPIO boot-select (1 pin) + GPIO/A-D test points| UUT_BOOT
    ACMFW -->|Access I/O| UUT_ACM
```

## Components

| Component | Repo path | Role |
| --- | --- | --- |
| `m1-operator-ui` | `components/m1-operator-ui` | Operator-facing React application running on the fixture host PC. |
| `m1-rest-server` | `components/m1-rest-server` | Runs on the PC. Acts as a bridge between the React UI and `m1tfc`; it contains no test logic. |
| `m1tfc` | `components/m1tfc` | Runs on the PC. Stands for M1 Test Fixture Control, owns the test workflow, and controls all hardware interfaces below. |
| `m1testBoardFw` | `components/m1testBoardFw` | Firmware for the M1 Test Board. Connected to the PC over a dedicated serial link. Uses one GPIO boot-select control pin for UUT boot mode, and uses GPIO/A-D channels for fixture testing at UUT test points. |
| `acm-testboard-fw` | `components/acm-testboard-fw` | Firmware for the ACM Test Board. Connected to the PC over UDP. Exercises the UUT's access-control hardware. |
| `stm32mp1-baremetal` | `components/stm32mp1-baremetal` | Firmware downloaded to the UUT with DFU helper flow and then run on bare metal. It is accessible via the UUT serial header, and `m1tfc` communicates with it over a dedicated serial link independent of the M1 Test Board link. |
| UUT | — | Also has a direct USB link to the PC for DFU and SSD programming after the boot-select pins are set to the required boot target. |

## Data Flow Narrative

1. The operator uses `m1-operator-ui` in a browser, and the UI calls `m1-rest-server` through an HTTP REST API.
2. `m1-rest-server` forwards commands to `m1tfc`, which owns all test sequencing and logic. Neither the UI nor the REST layer communicates with hardware directly.
3. `m1tfc` is the sole owner of the hardware links. It opens three independent command channels: serial to the M1 Test Board (`m1testBoardFw`), a separate direct serial link to the UUT firmware (`stm32mp1-baremetal`), and UDP to the ACM Test Board (`acm-testboard-fw`).
4. `m1tfc` also uses a direct USB link to the UUT for DFU-mode firmware and SSD programming.
5. `m1testBoardFw` sets UUT boot mode with one GPIO boot-select control pin (normal boot, DFU for SSD programming, or download-and-execute of `stm32mp1-baremetal`). GPIO/A-D channels are used for fixture test-point measurements, not for firmware download.
6. `acm-testboard-fw` exercises the UUT access-control hardware.
7. All three firmware targets use the same command/response model: `m1tfc` sends a command, and the firmware returns JSON (`status`, `error`, plus optional data). `acm-testboard-fw` carries the same JSON framing over UDP instead of serial.

## Out of Scope

- `tfcroncli` — cron-scheduled cloud-update function, not fixture test operation related.

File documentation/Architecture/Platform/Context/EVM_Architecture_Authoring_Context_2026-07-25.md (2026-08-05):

# EVM Architecture and Documentation — Complete State

**Snapshot date:** July 25, 2026  
**Platform owner / principal designer:** Leo Buchman  
**Platform name:** M1/MNPlus Unified Engineering, Validation and Manufacturing Platform (EVM)  
**Document purpose:** Preserve the complete current understanding of the EVM architecture, hardware subsystems, deployment configurations, capabilities, source artifacts, repository organization, factory-documentation needs, and twenty-year sustainment requirements. This file is intended to provide enough context to generate the formal documentation package without repeating the discovery process.

---

## 1. Restore and Authoring Instructions

This file is the authoritative starting point for generating EVM documentation.

A future author or assistant should:

1. Treat the product as a platform, not merely a test fixture.
2. Start documentation at the platform level, then decompose into subsystems and implementations.
3. Distinguish the engineering bench configuration from the production fixture configuration.
4. Treat the M1 Test Board and ACM Controller Test Board as reusable platform subsystems.
5. Use the actual design-source files and schematics as authoritative implementation references.
6. Preserve the distinction between platform capability and the subset exposed by a product-specific plate, pogo-pin map, IDC connection, or wiring harness.
7. Keep software, firmware, operations, assembly, manufacturing, validation, sustainment, and interface-control documentation in separate but coordinated sections.
8. For the immediate documentation phase, prioritize hardware architecture and factory assembly. Detailed software, firmware, and operations documents remain future work unless explicitly requested.
9. Design every document with the twenty-year service-life requirement in mind.
10. Do not generate fake `.docx` files or placeholder text files with Word extensions. All office documents must be valid and rendered for quality assurance.

---

## 2. Executive Summary

The EVM is a reusable, multidisciplinary engineering platform supporting the complete product lifecycle across M1, MNPlus, ACM, and the broader ACM controller ecosystem.

The platform supports:

- Engineering development and bring-up.
- Hardware validation.
- Firmware validation.
- Software and system validation.
- Hardware-in-the-loop testing.
- QA and regression testing.
- Manufacturing provisioning and qualification.
- Production testing.
- Product recovery and regeneration.
- Failure analysis.
- Remote diagnostics and technical support.
- Cloud-connected updates, logs, secrets, and future enhancements.

The system was initially at risk of being described simply as a “test fixture.” That description is materially incomplete. The production fixture is one physical deployment of a broader platform. The platform also exists as an engineering bench configuration with direct terminal-block and IDC access, and the same hardware/software architecture can support development, QA, manufacturing, sustaining, and service activities.

The preferred formal name is:

> **M1/MNPlus Unified Engineering, Validation and Manufacturing Platform (EVM)**

The platform exhibits system engineering across mechanical, electrical, embedded firmware, software, networking, cloud, automation, product simulation, manufacturing, and sustainment domains.

---

## 3. Platform Naming and Terminology

### 3.1 Preferred platform name

**M1/MNPlus Unified Engineering, Validation and Manufacturing Platform (EVM)**

A shorter acceptable title is:

**M1/MNPlus Engineering, Validation and Manufacturing Platform**

### 3.2 Terms that undersell the architecture

Avoid using the following as the primary name:

- Test fixture.
- Production fixture.
- Automated tester.
- Board tester.

Those terms may describe an implementation or use case, but not the entire platform.

### 3.3 Preferred subsystem names

- **M1 Test Board**
- **ACM Controller Test Board**
- **SAM-E Ethernet Subsystem**
- **Platform Host / Headless PC**
- **Production Fixture Interface**
- **Engineering Direct-Access Interface**

### 3.4 Scope labels in the platform diagram

- **M1 Test Board (M1 Scope) — Teensy 4.1**
- **ACM Test Board (ACM Scope) — Teensy 4.1**

The labels explain why two Teensy-based boards exist. “ACM Scope” describes how the ACM board is used within the current MNPlus implementation; the board's full capability is much broader than ACM-only support.

---

## 4. Design Philosophy

The EVM was designed around workflows and lifecycle functions rather than around isolated technologies.

The design question was not:

- How can a Teensy be used?
- How can a React application be created?
- How can a board be tested?

The architectural question was:

> What common system can support engineering, QA, manufacturing, provisioning, recovery, regeneration, and support across multiple related products?

The design follows this hierarchy:

1. Business and lifecycle needs.
2. System requirements.
3. Functional decomposition.
4. Subsystem responsibilities.
5. Interface definitions.
6. Technology selection.
7. Product-specific physical adaptation.

The individual technologies are components or “bricks.” The EVM architecture is the “house.”

---

## 5. High-Level Capability Model

### 5.1 Engineering

- Product bring-up.
- Direct signal access.
- Firmware development.
- Software development.
- Debugging and diagnostics.
- Boot-target selection.
- Serial-console access.
- Ethernet communications.
- Device recovery.
- Hardware-in-the-loop simulation.
- Experimental and fault-injection workflows.

### 5.2 QA and validation

- Automated hardware validation.
- Automated firmware validation.
- Automated software validation.
- Serial-based testing.
- Ethernet-based testing.
- Functional and system testing.
- Regression testing.
- Product-family simulation.
- Reproducible validation environments.
- Test-result and log collection.

### 5.3 Manufacturing

- Firmware programming.
- Product provisioning.
- Configuration loading.
- Production qualification.
- Automated pass/fail testing.
- Device regeneration.
- Traceability support.
- Acceptance validation.

### 5.4 Sustaining and support

- Failure analysis.
- Serial and network diagnostics.
- Firmware recovery.
- Product regeneration.
- Log retrieval.
- Remote support.
- Controlled updates.
- Service workflows.

---

## 6. System Architecture Overview

### 6.1 Major physical subsystems

- Fanless headless PC.
- USB hub.
- M1 Test Board.
- ACM Controller Test Board.
- SAM-E three-port Ethernet switch.
- PoE power injector.
- 48 VDC power supply.
- 48 VDC relay control.
- 12.5 VDC / 5 VDC power supply.
- Lever switch and status LED/operator interface.
- Product-specific fixture plate.
- Pogo-pin bed for production configuration.
- Terminal blocks and direct harnesses for engineering configuration.
- UUT: M1 or MNPlus, depending on configuration.

### 6.2 Major software and service subsystems

- React-based operator interface.
- REST server running on the headless PC.
- Node.js application/test executor.
- Cloud client.
- CLI utilities.
- M1 Test Board firmware.
- ACM Controller Test Board firmware.
- STM32MP1 firmware and bare-metal support components.

### 6.3 Primary communications

- Ethernet.
- PoE.
- USB.
- Serial/UART.
- RS-485.
- OSDP.
- Wiegand.
- IDC/ribbon interface.
- Pogo-pin electrical interface.
- I2C and platform-specific control signals where applicable.

### 6.4 Primary power domains

- 120 VAC input.
- 12.5 VDC fixture/test electronics rail.
- 5 VDC SAM-E switch rail.
- 48 VDC PoE rail.
- Switched 48 VDC through relay to the PoE injector.
- Local 3.3 V rails on embedded boards.

---

## 7. Platform Host / Headless PC

The fanless headless PC is the central application and orchestration platform.

### 7.1 Roles

- Test executive.
- Manufacturing gateway.
- Cloud client.
- Recovery platform.
- Remote-support endpoint.
- Local service host.
- Data/log collection endpoint.

### 7.2 Software responsibility split

**React UI**

- Operator experience.
- Test selection.
- Status and result presentation.
- Configuration and workflow interaction.

**REST server**

- Control-plane API.
- Decouples user interface from hardware and test execution.
- Enables local and potentially remote control.

**Node.js test executor**

- Executes automated test sequences.
- Coordinates hardware and firmware interactions.
- Provides reusable test logic.
- Supports engineering, QA, and manufacturing modes.

**Cloud client / Azure connectivity**

- Firmware/software updates.
- Logs.
- Secrets.
- Diagnostics.
- Remote support.
- Future AI-assisted enhancements.

### 7.3 Sustainment concern

The PC is a critical single platform dependency because UI, REST services, automation, logs, cloud, diagnostics, USB, and Ethernet orchestration depend on it.

Required sustainment artifacts include:

- Recoverable system image.
- OS and dependency definition.
- Build and deployment automation.
- Configuration backup.
- Offline recovery procedure.
- Replacement-hardware criteria.

---

## 8. M1 Test Board

### 8.1 Platform role

The M1 Test Board owns the M1-specific validation and control scope. It supports both the M1 product and the M1 portion of MNPlus. The M1 functional portion is materially identical across those products.

### 8.2 Controller

- Teensy 4.1.

### 8.3 Capabilities captured from the schematic and discussion

- Target power on/off control.
- Boot-target selection.
- Serial/UART communications.
- RS-485 support.
- Firmware programming.
- Recovery and regeneration.
- Fixture-control functions.
- Operator-interface support.
- Battery-related control, loading, and measurements.
- Analog measurement and multiplexing.
- Tamper input handling.
- I2C/ribbon-cable connectivity.
- Product-interface signal access.
- Direct engineering connection through IDC.
- Production interface through product-specific wiring and pogo pins.

### 8.4 Direct IDC versus pogo-pin use

The board includes an IDC interface that can connect directly to the corresponding M1 board interface in an engineering setup.

In the production fixture:

- The product connects through a product-specific fixture plate.
- The electrical path is presented through pogo pins.
- Wiring maps the test board interfaces to the appropriate UUT points.

In the engineering bench configuration:

- Direct IDC connections can be used.
- Terminal blocks can expose signals.
- Pogo pins and enclosure are not required.

### 8.5 Documentation required

- Hardware specification.
- Functional block diagram.
- PCB CAD image placeholder, later replaced with 2D board image.
- Connector and pin-interface table.
- Power-domain table.
- Control-signal list.
- IDC interface-control document.
- Product mapping for M1 and MNPlus.
- Source schematic reference.
- Manufacturing files and BOM.
- Test and replacement strategy.

---

## 9. ACM Controller Test Board

### 9.1 Platform role

The ACM Controller Test Board is a reusable ACM ecosystem simulation and validation subsystem.

The board was developed for end-to-end automated testing supporting Elements, a cloud solution. The board provides broad coverage across ACM controllers and related products, not merely the limited ACM subset used by the current MNPlus fixture.

### 9.2 Controller and communications

- Teensy 4.1.
- Ethernet interface.
- FTDI/USB serial logging or service interface.
- RS-485 reader interfaces.

### 9.3 Reader simulation

The board simulates two reader channels.

Capabilities include:

- Dual OSDP reader simulation.
- Dual Wiegand reader simulation.
- Reader data and clock signals.
- Reader LED interaction.
- Reader buzzer interaction.
- Reader power control.
- RS-485 termination and direction control.

### 9.4 Supervised-input simulation

The board provides eight supervised-input simulation channels:

- SI1 through SI8.

The circuitry uses analog components to simulate the relevant supervised states required for controller validation. Formal documentation should enumerate the supported states based on firmware and electrical implementation, such as normal, active/alarm, open, short, and other configured resistance conditions when verified.

### 9.5 Relay/output validation

The board supports relay and output validation.

Observed schematic signals include:

- Relay 1 through Relay 10.

The platform can use these channels to verify controller relay activations and simulate/observe field behavior.

### 9.6 Additional simulation functions

- Cabinet tamper simulation.
- Power-fault simulation.
- Controller-power switching/control.
- Downstream enable/control signals.
- Product-family interface support.

### 9.7 Product coverage

- ACM controller lines.
- Door controllers.
- I/O expansion boards.
- ACM-related functions within MNPlus.
- Elements end-to-end automated testing.

### 9.8 Platform capability versus current implementation

The current MNPlus deployment uses only the subset of ACM capabilities required for ACM/MNPlus validation.

Using broader ACM functionality requires:

- A different product-specific fixture plate.
- More or differently mapped pogo pins.
- Additional wiring.

This is an implementation variation, not a redesign of the core ACM Controller Test Board.

### 9.9 Documentation required

- Hardware specification.
- Functional block diagram.
- 2D CAD image placeholder.
- Reader-interface description.
- OSDP and Wiegand interface tables.
- Supervised-input state description.
- Relay/output-validation description.
- Power and tamper simulation description.
- Supported-product matrix.
- Connector maps.
- Firmware interface summary.
- Source schematic reference.
- Manufacturing package and BOM.

---

## 10. SAM-E Ethernet Subsystem

### 10.1 Current role

- LenelS2 product manufactured in Saline.
- Three-port Ethernet switching within the platform.
- Receives a dedicated 5 V rail from the main power supply.
- Connects the ACM Test Board, PoE injector/UUT path, and host/network path as configured.

### 10.2 COVID redesign history

During COVID shortages, required components were unavailable or carried extremely long lead times.

Leo developed a redesign around available parts, including:

- STM32G1-family controller selection.
- Improved Micrel/Microchip Ethernet switch selection.
- Hardware redesign.
- Firmware and RTOS implications.
- Component research and sourcing.

The redesign was driven by buildability and supply continuity, not by unnecessary redesign.

### 10.3 Current decision

Paul preferred keeping the legacy board because the design is proven and already understood by Saline. Under current stable-production conditions, that is a reasonable risk-management decision.

### 10.4 Sustainment implication

The redesign work may remain useful as a future replacement path if the legacy board becomes unbuildable, unsupported, or obsolete.

Documentation should retain:

- Original SAM-E implementation requirements.
- Redesign source files if available.
- Functional equivalence criteria.
- Interface-control requirements.
- Replacement triggers.

---

## 11. Power Architecture

### 11.1 Primary supply

- 120 VAC input.
- Main switch/back-panel control.

### 11.2 Low-voltage supply

- 12.5 VDC rail for fixture/test-control electronics.
- 5 VDC rail for the SAM-E Ethernet switch.

### 11.3 PoE supply

- Separate 120 VAC to 48 VDC supply.
- 48 VDC relay control.
- Switched 48 VDC to the PoE injector.
- PoE power and Ethernet delivered to the UUT.

### 11.4 Review questions to document formally

- Power-up and shutdown sequence.
- Relay default state.
- Software authority over PoE switching.
- Isolation and grounding strategy.
- Fuse/protection requirements.
- Maximum current requirements.
- UUT fault containment.
- Factory safety and inspection requirements.

---

## 12. Network, USB, and Service Architecture

### 12.1 Ethernet

- Host PC connects to local network infrastructure.
- SAM-E provides local switching.
- ACM Controller Test Board uses Ethernet for test/control functions.
- PoE injector combines Ethernet and 48 VDC for the UUT.

### 12.2 USB

- Host PC connects through a USB hub.
- USB supports Teensy serial control.
- USB DFU supports firmware loading and recovery.
- USB serial console supports diagnostics.
- USB flash media may support recovery, configuration, images, or other controlled artifacts; exact function should be documented from the implementation.

### 12.3 Serial

The platform performs both Ethernet-based and serial-based testing. Serial access is a first-class capability, not merely a debug afterthought.

### 12.4 Documentation required

- Network topology.
- Port assignments.
- USB-device map.
- Serial-port map.
- Service-mode connections.
- Cloud connectivity assumptions.
- Offline operation requirements.

---

## 13. Mechanical and Interface Architecture

### 13.1 Production fixture

Observed characteristics:

- Custom machined/product-specific plate.
- Lever-actuated compression mechanism.
- Guided clamping.
- Product nest and registration features.
- Acrylic or protective cover.
- Dense pogo-pin interface.
- Enclosed electronics bay.
- Organized harnesses and power distribution.

### 13.2 Engineering bench

Observed characteristics:

- Open mounting plate.
- Fanless PC.
- Exposed test boards.
- Terminal blocks.
- Direct signal access.
- Ethernet and power subsystems.
- No production enclosure required.
- No production pogo-pin fixture required for direct engineering connections.

### 13.3 Product-specific adaptation

M1 and MNPlus require different plates because:

- The physical boards differ.
- Pogo-pin maps differ.
- Required wiring differs.

The common platform remains the same.

### 13.4 Factory deliverables

- Mechanical drawings.
- CAD source files.
- STEP files.
- DXF files.
- Plate drawings.
- Pogo-pin map.
- Wiring and harness drawings.
- Fastener list.
- Assembly torque/specification where applicable.
- Alignment and inspection criteria.

---

## 14. Platform Diagram State

The draw.io diagram is considered architecture-review ready after these updates:

- Title changed from a generic fixture layout to an EVM platform title.
- M1 Test Board labeled with M1 scope.
- ACM Test Board labeled with ACM scope.
- Headless PC included.
- Azure/cloud block included.
- Power rails shown, including the 5 V SAM-E rail.
- 48 V relay and PoE path shown.
- USB DFU and serial-console paths shown.
- Operator lever/status interface shown.
- Capability bullets added.

The diagram intentionally presents the platform at system level. Detailed pin maps, board CAD, and wiring belong in supporting documents.

### 14.1 Current capability bullets

Recommended compressed capability list:

- Unified Engineering, QA, Manufacturing, Recovery, and Technical Support Platform.
- Hardware-in-the-Loop product validation and automation.
- M1 and ACM functional simulation and validation.
- Automated hardware, firmware, and software testing.
- Ethernet, serial, USB, and PoE test infrastructure.
- Firmware programming, provisioning, recovery, and regeneration.
- Failure analysis, diagnostics, and remote support.
- Cloud-connected updates, diagnostics, logs, and secrets.
- React-based operator interface.
- REST API and Node.js automated test-execution framework.
- Common platform architecture supporting multiple products and product families.

ACM capabilities:

- OSDP reader simulation.
- Wiegand reader simulation.
- Reader power control.
- Eight supervised-input simulations.
- Relay/output validation.
- Door-controller validation.
- ACM-controller validation.
- I/O expansion-board validation.
- End-to-end automated ACM ecosystem testing.

Notes:

- The current MNPlus implementation uses the subset required for M1/MNPlus validation.
- Additional ACM capabilities can be utilized through product-specific plates, pogo-pin mappings, and wiring configurations.

---

## 15. Repository Architecture

Observed top-level structure:

```text
m1-platform/
├── AI/
├── components/
├── doc/
├── scripts/
├── setup/
├── README.md
└── READMEConfig.md
```

Observed components:

```text
components/
├── m1-operator-ui/
├── m1-rest-server/
├── m1testBoardFw/
├── m1tfc/
├── acm-testboard-fw/
├── stm32mp1-baremetal/
└── tfcroncli/
```

This structure demonstrates a platform ecosystem spanning cloud, UI, REST services, embedded firmware, bare-metal work, test execution, automation, and CLI tools.

---

## 16. Required Documentation Repository Structure

Recommended structure:

```text
doc/
├── Architecture/
│   ├── Platform/
│   ├── Hardware/
│   │   ├── M1-Test-Board/
│   │   ├── ACM-Controller-Test-Board/
│   │   ├── SAM-E-Subsystem/
│   │   ├── Power/
│   │   ├── Network-and-PoE/
│   │   ├── Mechanical/
│   │   └── Fixture-Interface/
│   ├── Firmware/
│   └── Software/
├── Assembly/
├── Manufacturing/
├── Operations/
├── Validation/
├── Sustainment/
└── ICD/
```

### 16.1 Architecture / Platform

- EVM Platform Overview.
- EVM Platform Capabilities.
- EVM Hardware Architecture.
- Engineering vs Production Configurations.
- Product Coverage Matrix.
- Platform Evolution.

### 16.2 Architecture / Hardware

- M1 Test Board Hardware Specification.
- ACM Controller Test Board Hardware Specification.
- SAM-E subsystem description.
- Power Architecture.
- Network and PoE Architecture.
- Mechanical Architecture.
- Fixture Interface Architecture.

### 16.3 Firmware — future

- M1 Test Board Firmware Architecture.
- ACM Controller Test Board Firmware Architecture.
- Firmware interfaces.
- Build and release process.

### 16.4 Software — future

- React Operator UI Architecture.
- REST Server Architecture.
- Node.js Test Framework Architecture.
- Cloud Client Architecture.
- CLI and automation documentation.

### 16.5 Assembly

- Engineering Platform Assembly Guide.
- Production Fixture Assembly Guide.
- Wiring drawings.
- Harness drawings.
- Mechanical drawings.
- Inspection criteria.

### 16.6 Manufacturing

- Manufacturing deployment guide.
- Provisioning process.
- Factory validation procedure.
- Factory Acceptance Test.
- Manufacturing release checklist.

### 16.7 Operations — future

- Operator guide.
- Service guide.
- Recovery procedures.
- Troubleshooting guide.

### 16.8 Validation

- Validation strategy.
- Regression strategy.
- Product coverage matrix.
- Qualification reports.
- Test-coverage reports.

### 16.9 Sustainment

- Obsolescence-management plan.
- Critical-component registry.
- Replacement strategies.
- Toolchain preservation.
- Lifecycle risk register.
- Periodic sustainment review.

### 16.10 Interface-Control Documents

- M1 product interface.
- MNPlus product interface.
- IDC interface.
- Pogo-pin maps.
- Reader interfaces.
- Power interfaces.
- Ethernet interfaces.
- USB/serial interfaces.
- Manufacturing interfaces.

---

## 17. Formal Documents to Generate First

### Document 1 — EVM Platform Overview

Purpose:

- Explain what EVM is.
- Explain why EVM exists.
- Explain lifecycle use cases.
- Show major subsystems.
- Establish that the production fixture is one deployment.

Suggested sections:

1. Purpose.
2. Scope.
3. Platform vision.
4. Supported lifecycle functions.
5. Supported products.
6. Major subsystems.
7. Engineering and production deployments.
8. Architecture overview.
9. Documentation map.
10. Sustainment statement.

### Document 2 — EVM Hardware Architecture

Suggested sections:

1. Scope and exclusions.
2. System block diagram.
3. Hardware decomposition.
4. Power architecture.
5. Network and PoE architecture.
6. USB and serial architecture.
7. M1 Test Board role.
8. ACM Controller Test Board role.
9. Engineering direct-access interface.
10. Production fixture interface.
11. Product-specific adaptations.
12. Safety and maintainability considerations.
13. Interfaces to firmware/software.
14. Sustainment considerations.

### Document 3 — M1 Test Board Hardware Specification

Suggested sections:

1. Purpose and scope.
2. Functional architecture.
3. CAD/image placeholder.
4. Controller and power.
5. Interfaces.
6. Boot and target control.
7. Analog measurements.
8. Battery-related functions.
9. IDC interface.
10. Production pogo-pin mapping approach.
11. Supported products.
12. Manufacturing artifacts.
13. Sustainment requirements.

### Document 4 — ACM Controller Test Board Hardware Specification

Suggested sections:

1. Purpose and scope.
2. Functional architecture.
3. CAD/image placeholder.
4. Controller and communications.
5. Dual reader simulation.
6. OSDP interfaces.
7. Wiegand interfaces.
8. Reader power/LED/buzzer behavior.
9. Supervised-input simulation.
10. Relay/output validation.
11. Power-fault and cabinet-tamper simulation.
12. Supported products.
13. Full capability versus current MNPlus subset.
14. Manufacturing artifacts.
15. Sustainment requirements.

### Document 5 — Factory Production Fixture Assembly Guide

Suggested sections:

1. Purpose and controlled configuration.
2. Safety.
3. Required parts and BOM.
4. Mechanical components.
5. Electrical components.
6. Wiring and harness installation.
7. Board installation.
8. Power-supply installation.
9. Fixture-plate and pogo-pin setup.
10. Cable routing and strain relief.
11. Initial power-up.
12. Software/image loading reference.
13. Verification and Factory Acceptance Test.
14. Inspection checklist.
15. Serialization and release records.

### Document 6 — Twenty-Year Sustainment Plan

Suggested sections:

1. Service-life requirement.
2. Configuration baseline.
3. Critical components.
4. Obsolescence monitoring.
5. Approved alternate process.
6. Redesign triggers.
7. Toolchain preservation.
8. Source and binary preservation.
9. Replacement-PC strategy.
10. Interface preservation.
11. Periodic review schedule.
12. End-of-life and technology-refresh process.

---

## 18. Factory Documentation Requirements

The factory builds the box and performs the assembly. The factory package must be actionable and controlled, not a high-level architecture narrative.

Required artifacts:

- Controlled BOM.
- Approved manufacturer part numbers.
- Alternate parts where approved.
- Mechanical drawings.
- Enclosure drawing.
- Plate drawing for each UUT configuration.
- Pogo-pin part numbers and placement map.
- Wiring diagram.
- Harness drawings and lengths.
- Connector/pin tables.
- Terminal-block map.
- Power-distribution diagram.
- Assembly sequence.
- Cable routing and strain-relief instructions.
- Torque/fastener guidance where applicable.
- Photos or CAD views at key assembly stages.
- Labeling requirements.
- PC loading/configuration reference.
- Initial power-up checks.
- Factory Acceptance Test.
- Final inspection and release checklist.

The factory should be able to build and verify the platform without requiring undocumented knowledge from Leo.

---

## 19. Twenty-Year Service-Life and Sustainment

Paul's requirement is that the platform remain in service for approximately twenty years.

### 19.1 Core reality

It is unlikely that all electronics, specific components, computing hardware, operating systems, and toolchains will remain unchanged and available for twenty years.

The sustainment design goal is therefore not “freeze every component.” It is:

> Preserve the functions, interfaces, requirements, source, manufacturing knowledge, and validation methods needed to repair or redesign subsystems over time.

### 19.2 High-risk components

Examples requiring lifecycle monitoring:

- Teensy 4.1.
- SAM-E legacy components.
- Microcontrollers and processors.
- Ethernet switches and PHYs.
- RS-485 transceivers.
- Regulators and power components.
- PoE injector.
- Fanless PC.
- USB hub.
- Connectors and pogo pins.
- Mechanical fixture components.

### 19.3 Required source preservation

Hardware:

- Native design projects.
- Libraries.
- Schematics.
- PCB layouts.
- Gerbers.
- Pick-and-place.
- BOM.
- Assembly drawings.
- CAD and manufacturing drawings.

Firmware/software:

- Source repositories.
- Submodule/dependency state.
- Build scripts.
- Toolchain versions.
- Reproducible build environments.
- Release binaries.
- Installation packages.
- Recovery images.
- Secrets-management procedures without embedding live secrets.

### 19.4 Interface preservation

ICDs are critical because future implementations may change while required interfaces must remain stable.

Each ICD should capture:

- Signal name.
- Direction.
- Voltage/current level.
- Protocol.
- Timing.
- Connector and pin.
- Default state.
- Fault behavior.
- Test/validation method.

### 19.5 Obsolescence process

Recommended process:

1. Maintain a critical-component register.
2. Review lifecycle status at least annually.
3. Track last-time-buy notices.
4. Identify candidate alternates early.
5. Define functional replacement requirements.
6. Build validation tests before redesign.
7. Preserve known-good golden units.
8. Document redesign and qualification decisions.

---

## 20. Source Artifacts Reviewed or Available

### Schematics

- M1 Test Board schematic PDF.
- ACM Controller Test Board schematic PDF.
- M1-3200 product schematic PDF.
- MNPlus product schematic PDF.

### Drawings and images

- EVM draw.io system diagram.
- 2D CAD views available for boards.
- Production fixture photographs.
- Engineering bench photographs.

### Repository

- Cloud client.
- Operator UI.
- REST server.
- M1 board firmware.
- ACM board firmware.
- STM32MP1 bare-metal work.
- Test framework.
- CLI automation.
- Scripts, setup, and current documentation.

---

## 21. Known Documentation Boundaries

### In immediate scope

- Platform Overview.
- Platform Capabilities.
- Hardware Architecture.
- M1 Test Board spec.
- ACM Controller Test Board spec.
- Factory assembly package.
- Sustainment foundations.

### Not yet in immediate scope

- Full software architecture.
- Full firmware architecture.
- Detailed operational procedures.
- Complete validation test specifications.

Those areas should already have reserved directory locations so future documents can be added without restructuring the repository.

---

## 22. Important Corrections and Lessons

1. The EVM is not merely a test fixture.
2. The production enclosure is one implementation of the platform.
3. Engineering and production use the same core architecture but different interface layers.
4. M1 and MNPlus require different plates/pogo mappings because the physical boards differ.
5. The ACM board has much broader capability than the ACM subset used in MNPlus.
6. The M1 Test Board provides direct IDC engineering connectivity as well as production-interface support.
7. The 5 V SAM-E rail must be shown in the power architecture.
8. Draw.io section/background boxes must never become electrical endpoints.
9. Visual board labels are authoritative even if internal XML IDs are confusing.
10. Valid Word files must be generated as real DOCX packages and rendered before delivery.
11. A directory skeleton is not documentation.
12. A true restore point must preserve reasoning, not just headings.

---

## 23. Open Technical Questions

1. Exact UUT pogo-pin signal list for M1.
2. Exact UUT pogo-pin signal list for MNPlus.
3. Exact USB flash-drive role.
4. Formal definition of all supported supervised-input states.
5. Exact division of relay/output validation channels used by each product.
6. PoE switching control authority and default safety state.
7. Full network-addressing and port model.
8. Offline operation requirements.
9. PC recovery-image and replacement-hardware requirements.
10. Calibration requirements, if any.
11. Factory acceptance limits and expected measurements.
12. Required traceability records.
13. Critical-component ownership and lifecycle-review frequency.
14. Final document numbering and revision system.

---

## 24. Recommended Documentation Priority

1. EVM Platform Overview.
2. EVM Hardware Architecture.
3. Engineering vs Production Configurations.
4. M1 Test Board Hardware Specification.
5. ACM Controller Test Board Hardware Specification.
6. Production Fixture Assembly Guide.
7. Wiring and Interface Package.
8. Factory Acceptance Test.
9. Product Coverage Matrix.
10. Twenty-Year Sustainment Plan.
11. Firmware Architecture.
12. Software Architecture.
13. Operations and Service Documentation.

---

## 25. Final Architecture Conclusions

1. The EVM is a platform, not a single-purpose fixture.
2. The architecture was designed at system level before implementation.
3. The platform unifies engineering, QA, manufacturing, recovery, and support.
4. The M1 Test Board encapsulates M1-specific control and validation.
5. The ACM Controller Test Board is a reusable ACM ecosystem simulator.
6. Product-specific plates, pogo maps, IDC connections, and wiring expose selected platform capabilities.
7. The headless PC provides the application, automation, cloud, recovery, and remote-support layer.
8. The SAM-E and PoE subsystems provide controlled network and power infrastructure.
9. The engineering bench and production fixture are two deployments of the same architecture.
10. Formal factory documentation is necessary because Saline/factory personnel build the enclosure and perform assembly.
11. Twenty-year service life requires obsolescence planning, interface preservation, reproducible builds, and complete source/manufacturing artifacts.
12. The documentation package should be organized Platform → Subsystem → Implementation, not as an unstructured collection of board files.

---

## 26. Future Restore Prompt

> Read `doc/Architecture/Platform/Context/EVM_Architecture_Authoring_Context_2026-07-25.md` (this file) as the authoritative state of the M1/MNPlus Unified Engineering, Validation and Manufacturing Platform. Use the documented platform terminology, subsystem responsibilities, engineering-versus-production distinction, factory-documentation requirements, repository structure, and twenty-year sustainment model. Generate documentation beginning with Platform Overview and Hardware Architecture, then board specifications and factory assembly. Do not reduce EVM to a test fixture. Do not invent missing interfaces; preserve listed open questions until Leo supplies the authoritative details.

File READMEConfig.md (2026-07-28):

# M1 Platform Configuration

This document describes the host configuration consumed by `m1tfc` when it runs from VS Code, a terminal, or the React launcher.

## Configuration Files

`m1tfc` reads these host files:

```text
/etc/m1platform/config.json
/etc/m1platform/calibration.json
```

The effective configuration is built in this order:

1. Built-in `m1tfc` defaults.
2. `/etc/m1platform/config.json`.
3. `/etc/m1platform/calibration.json`.

Later files override or extend earlier values. Both files must contain valid JSON. If either file is missing or unreadable, `m1tfc` continues with the remaining configuration.

## Shared Fixture Files

Store fixture firmware, image directories, and test logs at:

```text
/var/m1mtf
```

The ICT SRAM image is normally:

```text
/var/m1mtf/fsbl.stm32
```

`/var/m1mtf` is intentionally independent of the invoking user. This matters because the React application runs `m1tfc` with `sudo`; a `$HOME/m1mtf` default would otherwise resolve to `/root/m1mtf` instead of the fixture data directory.

## config.json

`config.json` holds machine and production-test settings. The following non-secret settings are required for a configured fixture:

```json
{
  "tfInterface": "enp1s0",
  "vendorSite": "s5",
  "skipBatteryTest": false,
  "coinCellMinVoltageNew": 3.0,
  "coinCellMinVoltageUsed": 2.9,
  "skipTestpointCheck": false,
  "skipRS485test": false,
  "productName": "mnplus",
  "forceEppromOverwrite": false,
  "fwDir": "stm32mp15-lenels2-mnp",
  "layoutFilePath": "flashlayout_st-ls2m1c-image-core/optee/FlashLayout_emmc_stm32mp151f-ls2m1c-optee.tsv",
  "mtfDir": "/var/m1mtf",
  "programmingCommand": "/opt/STMicroelectronics/STM32Cube/STM32CubeProgrammer/bin/STM32_Programmer_CLI"
}
```

Use values appropriate to the installed fixture, product, and production site. The fields are:

- `productName`: target product variant, for example `m1-3200` or `mnplus`.
- `tfInterface`: fixture Ethernet interface.
- `vendorSite`: manufacturing site identifier.
- `fwDir` and `layoutFilePath`: firmware and flash-layout paths below `mtfDir`.
- `mtfDir`: shared fixture firmware and log directory; use `/var/m1mtf`.
- `programmingCommand`: absolute path to the STM32CubeProgrammer CLI executable.
- `coinCellMinVoltageNew`: minimum coin-cell voltage for `--cellBatTol new`.
- `coinCellMinVoltageUsed`: minimum coin-cell voltage for `--cellBatTol used`.
- `skipTestpointCheck`, `skipRS485test`, `skipBatteryTest`, and `forceEppromOverwrite`: production-test behavior controls.

Some deployments also store service credentials or production passwords in this file. Do not copy those values into source control, logs, or documentation. Apply host access controls appropriate to the users and services that must run `m1tfc`.

Edit and validate the file:

```bash
sudoedit /etc/m1platform/config.json
sudo jq -e . /etc/m1platform/config.json >/dev/null
sudo jq -e '{mtfDir, programmingCommand}' /etc/m1platform/config.json
sudo test -r /var/m1mtf/fsbl.stm32
sudo test -x /opt/STMicroelectronics/STM32Cube/STM32CubeProgrammer/bin/STM32_Programmer_CLI
```

## calibration.json

`calibration.json` stores test-board-specific analog calibration and expected values. Its top-level structure is:

```json
{
  "boards": [
    {
      "testPointsMnp": [],
      "testPointsM1": [],
      "ribbonCableA2DPins": [],
      "strikeReg": [],
      "ddrVoltageM1": {},
      "ddrVoltageMnp": {},
      "coinCellBattery": {
        "name": "BatCellBat",
        "minVoltageNew": 3.0,
        "minVoltageAged": 2.9,
        "scale": 1
      }
    }
  ]
}
```

The `boards` array is indexed by the test-board firmware board ID. A board ID of `n` uses `boards[n]`; preserve array positions when adding or updating a calibration profile. The individual test-point entries contain the measured point name, expected voltage, and scale where applicable.

The calibration process owns the measured values. On load, `m1tfc` expands missing, empty, or incomplete board profiles to the built-in defaults, then calibration saves the measured scales back to this file. Existing non-empty calibration groups are preserved.

### New Fixture Bootstrap

For a new fixture, create `/etc/m1platform/calibration.json` with this starter structure:

```json
{
  "boards": [
    {
      "testPointsMnp": [],
      "testPointsM1": [],
      "ribbonCableA2DPins": [],
      "strikeReg": [],
      "ddrVoltageM1": {},
      "ddrVoltageMnp": {},
      "coinCellBattery": {
        "name": "BatCellBat",
        "minVoltageNew": 3.0,
        "minVoltageAged": 2.9,
        "scale": 1
      }
    }
  ]
}
```

This is a seed, not a complete calibration. `m1tfc` expands it to 20 default board profiles before running ICT. Run the ICT calibration process as root to measure the fixture and save its calibrated values:

```bash
sudo m1tfc ict \
  --serial <vendor-serial> \
  --debug 1 \
  --cellBatTol used \
  --calibrate true
```

During calibration the process updates the measured scales and writes the resulting JSON to `/etc/m1platform/calibration.json`. A failed calibration can leave the file only partially updated; correct the fixture issue and rerun calibration before using the fixture for production.

Confirm the bootstrap created the expected structure:

```bash
sudo jq -e '.boards | type == "array" and length == 20' \
  /etc/m1platform/calibration.json
```

Back up the file before changing a known-good production calibration:

```bash
sudo cp /etc/m1platform/calibration.json \
  /etc/m1platform/calibration.json.bak-$(date +%Y%m%d%H%M%S)
sudoedit /etc/m1platform/calibration.json
sudo jq -e '.boards | type == "array"' /etc/m1platform/calibration.json
```

## Operational Check

After changing paths or configuration, run a normal ICT operation. The log must show the shared absolute firmware path:

```text
Executing ICT command /var/m1mtf/fsbl.stm32 ...
```

A DFU timeout after this message is a fixture/boot-mode/programmer issue. If the log instead shows `/root/m1mtf/...`, `mtfDir` was not loaded from `/etc/m1platform/config.json`.

## MAC Address Allocation

The M1-3200 and MNPlus test fixtures share OUI EUI-48 block `58-FC-C8`.
Each fixture station is assigned a dedicated 1,000,000-address block,
starting at the base MAC below (the station's `STARTMAC`, see
`setup/setup.sh` usage), to avoid UID collisions between stations.

### M1-3200 Fixtures

| Station | Base MAC |
|---|---|
| m1-3200-1  | 58:FC:C8:00:00:00 |
| m1-3200-2  | 58:FC:C8:0F:42:40 |
| m1-3200-3  | 58:FC:C8:1E:84:80 |
| m1-3200-4  | 58:FC:C8:2D:C6:C0 |
| m1-3200-5  | 58:FC:C8:3D:09:00 |
| m1-3200-6  | 58:FC:C8:4C:4B:40 |
| m1-3200-7  | 58:FC:C8:5B:8D:80 |
| m1-3200-8  | 58:FC:C8:6A:CF:C0 |

### MNPlus Fixtures

| Station | Base MAC |
|---|---|
| mnplus-1 | 58:FC:C8:7A:12:00 |
| mnplus-2 | 58:FC:C8:89:54:40 |
| mnplus-3 | 58:FC:C8:98:96:80 |
| mnplus-4 | 58:FC:C8:A7:D8:C0 |
| mnplus-5 | 58:FC:C8:B7:1B:00 |
| mnplus-6 | 58:FC:C8:C6:5D:40 |
| mnplus-7 | 58:FC:C8:D5:9F:80 |
| mnplus-8 | 58:FC:C8:E4:E1:C0 |

> Verified `mnptestf5` UID base is `58:FC:C8:A7:D8:C0`, which falls in
> the `mnplus-4` slot above — hostname numbers may not map 1:1 to slot
> numbers. Confirm actual per-station assignments before relying on
> this table for provisioning new fixtures.

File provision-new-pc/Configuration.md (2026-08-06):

# M1 Platform Configuration

This document describes the host configuration consumed by `m1tfc` when it runs from VS Code, a terminal, or the React launcher.

## Configuration Files

`m1tfc` reads these host files:

```text
/etc/m1platform/config.json
/etc/m1platform/calibration.json
```

The effective configuration is built in this order:

1. Built-in `m1tfc` defaults.
2. `/etc/m1platform/config.json`.
3. `/etc/m1platform/calibration.json`.

Later files override or extend earlier values. Both files must contain valid JSON. If either file is missing or unreadable, `m1tfc` continues with the remaining configuration.

## Shared Fixture Files

Store fixture firmware, image directories, and test logs at:

```text
/var/m1mtf
```

The ICT SRAM image is normally:

```text
/var/m1mtf/fsbl.stm32
```

`/var/m1mtf` is intentionally independent of the invoking user. This matters because the React application runs `m1tfc` with `sudo`; a `$HOME/m1mtf` default would otherwise resolve to `/root/m1mtf` instead of the fixture data directory.

## config.json

`config.json` holds machine and production-test settings. The following non-secret settings are required for a configured fixture:

```json
{
  "tfInterface": "enp1s0",
  "vendorSite": "s5",
  "skipBatteryTest": false,
  "coinCellMinVoltageNew": 3.0,
  "coinCellMinVoltageUsed": 2.9,
  "skipTestpointCheck": false,
  "skipRS485test": false,
  "productName": "mnplus",
  "forceEppromOverwrite": false,
  "fwDir": "stm32mp15-lenels2-mnp",
  "layoutFilePath": "flashlayout_st-ls2m1c-image-core/optee/FlashLayout_emmc_stm32mp151f-ls2m1c-optee.tsv",
  "mtfDir": "/var/m1mtf",
  "programmingCommand": "/opt/STMicroelectronics/STM32Cube/STM32CubeProgrammer/bin/STM32_Programmer_CLI"
}
```

Use values appropriate to the installed fixture, product, and production site. The fields are:

- `productName`: target product variant, for example `m1-3200` or `mnplus`.
- `tfInterface`: fixture Ethernet interface.
- `vendorSite`: manufacturing site identifier.
- `fwDir` and `layoutFilePath`: firmware and flash-layout paths below `mtfDir`.
- `mtfDir`: shared fixture firmware and log directory; use `/var/m1mtf`.
- `programmingCommand`: absolute path to the STM32CubeProgrammer CLI executable.
- `coinCellMinVoltageNew`: minimum coin-cell voltage for `--cellBatTol new`.
- `coinCellMinVoltageUsed`: minimum coin-cell voltage for `--cellBatTol used`.
- `skipTestpointCheck`, `skipRS485test`, `skipBatteryTest`, and `forceEppromOverwrite`: production-test behavior controls.

## Operator UI PIN Gate

`productionPassword` and `debugPassword` in `config.json` gate the "production"
and "debug" views in the operator UI (`m1-rest-server`'s `/auth` and
`/changepin` routes). This is a UI convenience to keep regular operators out
of the debug log view, not a network access control — the REST API itself
does not require a PIN to execute fixture commands, so it must only run on a
controlled, isolated fixture LAN.

`config.json` is the only place these PINs live; `m1-rest-server` has no
built-in default and requires them to be present. `provision-new-pc/setup/setup.sh`
inserts default values (`productionPassword: "1234"`, `debugPassword: "4321"`)
when it creates `config.json` on a freshly provisioned fixture PC. Change them
per-site with:

```bash
sudoedit /etc/m1platform/config.json
```

Some deployments also store service credentials or production passwords in this file. Do not copy those values into source control, logs, or documentation. Apply host access controls appropriate to the users and services that must run `m1tfc`.

Edit and validate the file:

```bash
sudoedit /etc/m1platform/config.json
sudo jq -e . /etc/m1platform/config.json >/dev/null
sudo jq -e '{mtfDir, programmingCommand}' /etc/m1platform/config.json
sudo test -r /var/m1mtf/fsbl.stm32
sudo test -x /opt/STMicroelectronics/STM32Cube/STM32CubeProgrammer/bin/STM32_Programmer_CLI
```

## calibration.json

`calibration.json` stores test-board-specific analog calibration and expected values. Its top-level structure is:

```json
{
  "boards": [
    {
      "testPointsMnp": [],
      "testPointsM1": [],
      "ribbonCableA2DPins": [],
      "strikeReg": [],
      "ddrVoltageM1": {},
      "ddrVoltageMnp": {},
      "coinCellBattery": {
        "name": "BatCellBat",
        "minVoltageNew": 3.0,
        "minVoltageAged": 2.9,
        "scale": 1
      }
    }
  ]
}
```

The `boards` array is indexed by the test-board firmware board ID. A board ID of `n` uses `boards[n]`; preserve array positions when adding or updating a calibration profile. The individual test-point entries contain the measured point name, expected voltage, and scale where applicable.

The calibration process owns the measured values. On load, `m1tfc` expands missing, empty, or incomplete board profiles to the built-in defaults, then calibration saves the measured scales back to this file. Existing non-empty calibration groups are preserved.

### New Fixture Bootstrap

For a new fixture, create `/etc/m1platform/calibration.json` with this starter structure:

```json
{
  "boards": [
    {
      "testPointsMnp": [],
      "testPointsM1": [],
      "ribbonCableA2DPins": [],
      "strikeReg": [],
      "ddrVoltageM1": {},
      "ddrVoltageMnp": {},
      "coinCellBattery": {
        "name": "BatCellBat",
        "minVoltageNew": 3.0,
        "minVoltageAged": 2.9,
        "scale": 1
      }
    }
  ]
}
```

This is a seed, not a complete calibration. `m1tfc` expands it to 20 default board profiles before running ICT. Run the ICT calibration process as root to measure the fixture and save its calibrated values:

```bash
sudo m1tfc ict \
  --serial <vendor-serial> \
  --debug 1 \
  --cellBatTol used \
  --calibrate true
```

During calibration the process updates the measured scales and writes the resulting JSON to `/etc/m1platform/calibration.json`. A failed calibration can leave the file only partially updated; correct the fixture issue and rerun calibration before using the fixture for production.

Confirm the bootstrap created the expected structure:

```bash
sudo jq -e '.boards | type == "array" and length == 20' \
  /etc/m1platform/calibration.json
```

Back up the file before changing a known-good production calibration:

```bash
sudo cp /etc/m1platform/calibration.json \
  /etc/m1platform/calibration.json.bak-$(date +%Y%m%d%H%M%S)
sudoedit /etc/m1platform/calibration.json
sudo jq -e '.boards | type == "array"' /etc/m1platform/calibration.json
```

## Operational Check

After changing paths or configuration, run a normal ICT operation. The log must show the shared absolute firmware path:

```text
Executing ICT command /var/m1mtf/fsbl.stm32 ...
```

A DFU timeout after this message is a fixture/boot-mode/programmer issue. If the log instead shows `/root/m1mtf/...`, `mtfDir` was not loaded from `/etc/m1platform/config.json`.

## MAC Address Allocation

The M1-3200 and MNPlus test fixtures share OUI EUI-48 block `58-FC-C8`.
Each fixture station is assigned a dedicated 1,000,000-address block,
starting at the base MAC below (the station's `STARTMAC`, see
`setup/setup.sh` usage), to avoid UID collisions between stations.

### M1-3200 Fixtures

| Station | Base MAC |
|---|---|
| m1-3200-1  | 58:FC:C8:00:00:00 |
| m1-3200-2  | 58:FC:C8:0F:42:40 |
| m1-3200-3  | 58:FC:C8:1E:84:80 |
| m1-3200-4  | 58:FC:C8:2D:C6:C0 |
| m1-3200-5  | 58:FC:C8:3D:09:00 |
| m1-3200-6  | 58:FC:C8:4C:4B:40 |
| m1-3200-7  | 58:FC:C8:5B:8D:80 |
| m1-3200-8  | 58:FC:C8:6A:CF:C0 |

### MNPlus Fixtures

| Station | Base MAC |
|---|---|
| mnplus-1 | 58:FC:C8:7A:12:00 |
| mnplus-2 | 58:FC:C8:89:54:40 |
| mnplus-3 | 58:FC:C8:98:96:80 |
| mnplus-4 | 58:FC:C8:A7:D8:C0 |
| mnplus-5 | 58:FC:C8:B7:1B:00 |
| mnplus-6 | 58:FC:C8:C6:5D:40 |
| mnplus-7 | 58:FC:C8:D5:9F:80 |
| mnplus-8 | 58:FC:C8:E4:E1:C0 |

> Verified `mnptestf5` UID base is `58:FC:C8:A7:D8:C0`, which falls in
> the `mnplus-4` slot above — hostname numbers may not map 1:1 to slot
> numbers. Confirm actual per-station assignments before relying on
> this table for provisioning new fixtures.

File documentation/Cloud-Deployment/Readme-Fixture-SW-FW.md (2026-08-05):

# fixtureFWSW

Contents of a test fixture's `fixtureFWSW/` directory in the
`m1mnplus-testing-platform` container:

- Fixture PC software
- Fixture's custom test-board firmware
- Target baremetal firmware

## Manifest file

A `manifestFile.json` shall be created describing the files below, with
each entry containing `filetype`, `filename`, and a SHA-512 `hash`.

```json
{
  "files": [
    {
      "filetype": "gui-react-snap",
      "filename": "gui-react_<version>_amd64.snap",
      "hash": "<sha-512 hash>"
    },
    {
      "filetype": "m1client-snap",
      "filename": "m1client_<version>_amd64.snap",
      "hash": "<sha-512 hash>"
    },
    {
      "filetype": "m1tfc-snap",
      "filename": "m1tfc_<version>_amd64.snap",
      "hash": "<sha-512 hash>"
    },
    {
      "filetype": "m1tfc-rest-snap",
      "filename": "m1tfc-rest-server_<version>_amd64.snap",
      "hash": "<sha-512 hash>"
    },
    {
      "filetype": "cloud-update-snap",
      "filename": "cloud-update-snap.snap",
      "hash": "<sha-512 hash>"
    },
    {
      "filetype": "m1testboardfw",
      "filename": "firmware.hex",
      "hash": "<sha-512 hash>"
    },
    {
      "filetype": "acm-test-board-boardfw",
      "filename": "acmfirmware.hex",
      "hash": "<sha-512 hash>"
    },
    {
      "filetype": "stm32baremetalfw",
      "filename": "fsbl.stm32",
      "hash": "<sha-512 hash>"
    }
  ]
}
```

## File list

Fixture PC software:

- `gui-react-snap` — operator UI snap (`gui-react_<version>_amd64.snap`)
- `m1client-snap` — fixture cloud-update/CLI client snap, built from
  `tfcroncli` (`m1client_<version>_amd64.snap`)
- `m1tfc-snap` — test fixture controller snap (`m1tfc_<version>_amd64.snap`)
- `m1tfc-rest-snap` — REST server snap, built from `m1-rest-server`
  (`m1tfc-rest-server_<version>_amd64.snap`)
- `cloud-update-snap` — cloud update snap (`cloud-update-snap.snap`)

Fixture's custom test-board firmware:

- `m1testboardfw` — M1 test board (Teensy 4.1) firmware, built from
  `m1testBoardFw` (`firmware.hex`)
- `acm-test-board-boardfw` — ACM test board firmware, built from
  `acm-testboard-fw` (`acmfirmware.hex`)

Target baremetal firmware:

- `stm32baremetalfw` — STM32MP1 ICT FSBL, built from
  `stm32mp1-baremetal` (`fsbl.stm32`)

## Directory contents

All of the files above, plus `manifestFile.json` describing them, shall
be placed directly in `fixtureFWSW/`.

Updating these files on a fixture is automatic — see
[`uploadSWFWtoCloud.md`](uploadSWFWtoCloud.md).

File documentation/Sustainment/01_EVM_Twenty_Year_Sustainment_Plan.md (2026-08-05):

**EVM Twenty-Year Sustainment Plan**

*Lifecycle, obsolescence, source preservation, and replacement strategy*

Version 1.0 \| July 25, 2026\
Owner: Leo Buchman\
Status: Initial controlled draft

  -------------------------------------------------------------------------------------------
  Document Type                       Sustainment Plan
  ----------------------------------- -------------------------------------------------------
  Platform                            M1/MNPlus EVM

  Scope                               Hardware / architecture

  Source Baseline                     Schematics, platform diagram, physical configurations
  -------------------------------------------------------------------------------------------

# 1. Requirement

The EVM is expected to remain supportable for approximately twenty years. The sustainment objective is to preserve required functions and interfaces even when individual electronic, mechanical, computing, operating-system, and toolchain components require replacement.

# 2. Sustainment Principles

- Preserve native design sources, not only PDFs

- Preserve controlled interfaces and validation criteria

- Maintain reproducible firmware and software builds

- Track critical-component lifecycle status

- Keep golden hardware and known-good release images

- Treat redesign as expected lifecycle work, not exceptional failure

- Document architecture rationale so replacements preserve function

# 3. Critical Asset Register

  ----------------------------------------------------------------------------------------------------------------------------------------------
  **Asset class**         **Examples**                                            **Required preservation**
  ----------------------- ------------------------------------------------------- --------------------------------------------------------------
  Hardware design         M1 board, ACM board, SAM-E, power, harnesses        Native CAD, libraries, BOM, manufacturing outputs

  Mechanical              Enclosure, plate, pogo bed, brackets                    CAD, STEP, DXF, drawings, materials

  Firmware                M1 and ACM test-board firmware                      Source, compiler/toolchain, build scripts, release binaries

  Software                React UI, REST server, Node.js executor, cloud client   Source, locked dependencies, install/deploy process

  Host platform           Fanless PC and OS image                                 Recovery image, replacement criteria, drivers, configuration

  Interfaces              IDC, pogo pins, reader, Ethernet, USB, power            Controlled ICDs and pin maps

  Validation              Golden units, acceptance tests, regression tests        Procedures, expected results, retained reference units
  ----------------------------------------------------------------------------------------------------------------------------------------------

# 4. Obsolescence Process

1\. Maintain a critical-component list with manufacturer lifecycle status

2\. Review lifecycle status at least annually

3\. Record EOL/NRND and last-time-buy notices

4\. Identify candidate sources or alternate components

5\. Define function and interface requirements before replacement

6\. Prototype and validate replacements using the EVM regression suite

7\. Update sources, BOM, manufacturing files, and acceptance tests

8\. Retain the superseded baseline and migration rationale

# 5. Known Long-Term Risks

- Teensy 4.1 availability

- Legacy SAM-E component availability

- Ethernet switch and PHY availability

- RS-485 transceiver availability

- Power-supply and PoE component availability

- Fanless PC lifecycle and storage failure

- Linux/OS and web-package ecosystem changes

- Cloud service and authentication changes

- Loss of supplier/manufacturing knowledge

- Knowledge concentration in one engineer
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

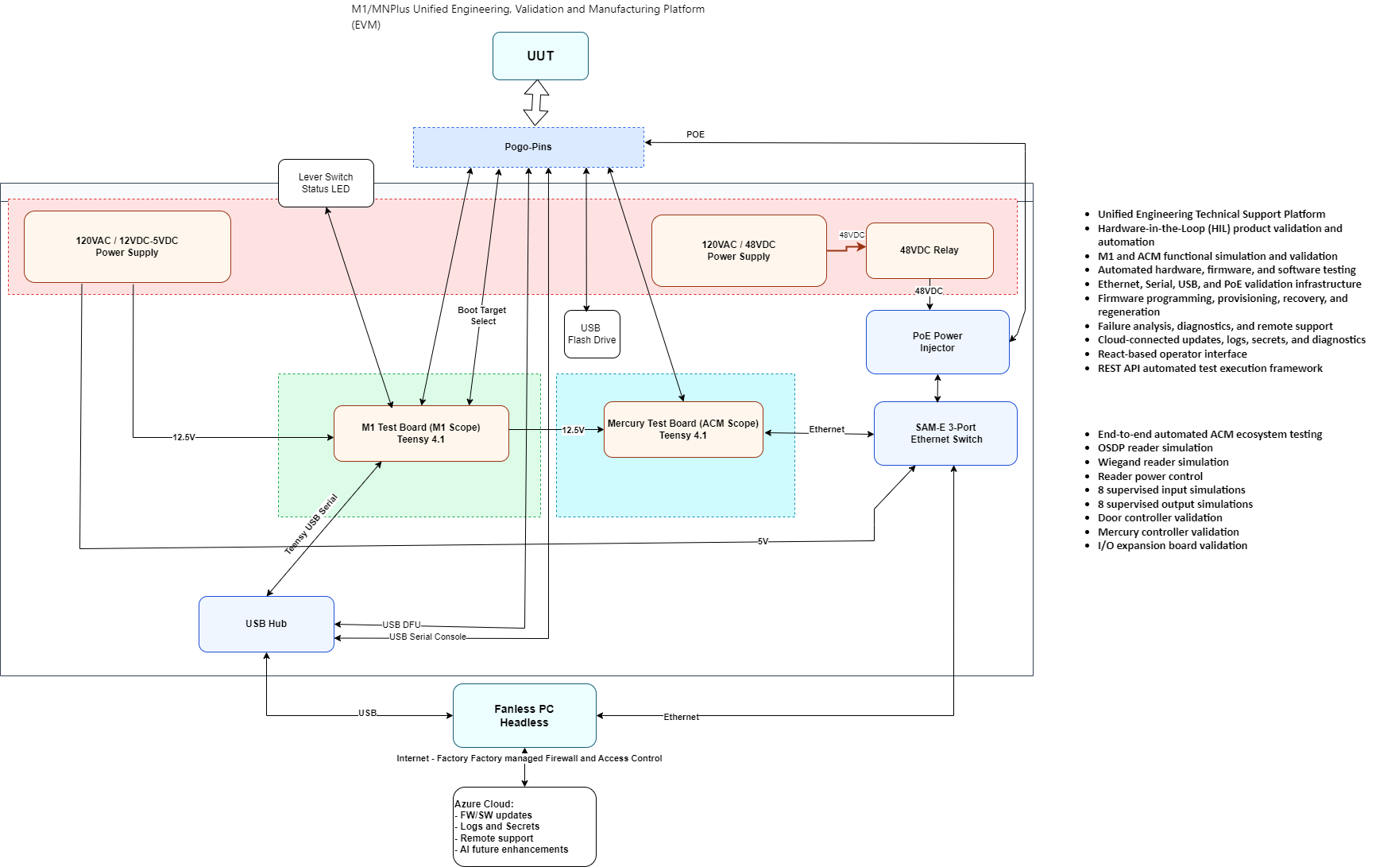
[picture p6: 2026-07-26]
documentation/Architecture/Platform/Source-Diagrams/mnplus_design_review_v3.drawio.png

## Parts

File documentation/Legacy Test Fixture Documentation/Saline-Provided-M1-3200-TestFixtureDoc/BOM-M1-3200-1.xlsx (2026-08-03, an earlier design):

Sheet: M1-3200 Saline BOM Purchase
M1-3200 Test Fixture BOM
Drawing No. BOM-M1-3200-1
Rev B
Description | Quantity | Manufacturer | Manufactuer's p/n | Supplier | Supplier's p/n
Test fixture kit | 1 | Test-X | TX-4004-CT102S-4GES | Test-X | TX-4004-CT102S-4GES
PCB support stops | 15 | Test-X | 0277-04-E | Test-X | 0277-04-E
Pressure fingers | 23 | Test-X | 0346-1.000-E-T | Test-X | 0346-1.000-E-T
Straight tooling pin, 0.155" diameter | 2 | Test-X | 3173-03 | Test-X | 3173-03
Lexan push plate | 1 | Test-X | TX-0260-CT102S-RL-L | Test-X
Probe sockets, wire wrap | 67 | QA Technology | 100-SDG251W | QA Technology | 100-SDG251W
Test probes, 100 diam. 250 stroke, serrated | 67 | QA Technology | 100-PRG2559S | QA Technology | 100-PRG2559S
Probe sockets, solder cup | 2 | QA Technology | 075-SDN250S | QA Technology | 075-SDN250S
Test probes, 075 diam. 250 stroke, serrated | 2 | QA Technology | 075-PRG2509S | QA Technology | 075-PRG2509S
Panel mount LED, green | 1 | Bivar Inc. | MPC3GDW12.0 | Digikey | 492-1548-ND
Switch | 1 | Omron Electronics | D2SW-3L2MS | Digikey | SW238-ND
Power module, dual output, 5Vdc, 12Vdc | 1 | CUI Inc. | VSBU-120-D512 | Digikey | 102-1699-ND
AC entry module | 1 | Schurter | DD11.0111.1110 | Digikey | 486-1275-ND
Fuse drawer | 1 | Schurter | 4301.1405 | Digikey | 486-1956-ND
Fuse, 2A, 5mm x 20mm | 1 | Littlefuse | 0235002.HXP | Mouser | 576-0235002.HXP
Power Cord, 4 ft. | 1 | Cables 2 Go | 29926 | Cables 2 Go | 29926
USB hub, USB 3.0, 4 port, powered | 1 | Atolla | CH-204U3(K) | Amazon | N/A
USB type B connector, panel mount | 1 | Amphenol | MUSBDA1130 | Newark | 49X2837
Ethernet connector, panel mount | 1 | Amphenol | RCP-5SPFFH-TCU7001 | Digikey | APC1766-ND
Cable ties | as needed | ABB-Thomas & Bett | TY23M | Newark | 31F2654
Cable tie mounts | as needed | Panduit | ABM1M-A-M | Mouser | 644-ABM1M-A-M
Crimp lugs, female disconnect, 22-16 AWG | 3 | Ace Hardware | 3015393 | Ace Hardware | 3015393
Crimp lugs, ring terminal | 2 | McMaster Carr | 7113K35 | McMaster Carr | 7113K35
Ribbon cable connector, 26 pin | 2 | CW Industries | CWN-370-26-0000 | Mouser | 629-CWN-370-26-0000
Ribbon cable connector, 26 pin | 4 | TE Connectivity | 1658620-6 | Mouser | 571-1658620-6
Ribbon cable, 26 conductor | 24" | 3M | 3365/26-100SF | Mouser | 517-3365/26
Angle aluminum, 0.5", 1/16" thick | 5 1/2" long | McMaster Carr | 8982K54 | McMaster Carr | 8982K54
Garolite, G-10/FR4 sheet, 1/8" thick, 6" x 6" yellow | 1 | McMaster Carr | 8667K1 | McMaster Carr | 8667K1
Breadboard | 1 | Vector Electronics | 8029 | Digikey | V2025-ND
USB cables, A to A, 2 meter, cut to length | 1 | Cables 2 Go | 54171 | Cables 2 Go | 54171
USB cabel, micro to A, 1ft. | 1 | Cables 2 Go | 27423 | Cables 2 Go | 27423
USB to CBL cable, 300mm | 1 | Adafruit Industries | 4449 | Digikey | 1528-4449-ND
Ethernet cable, Cat5e, 1 ft. | 1 | Cables 2 Go | 23828 | Cables 2 Go | 23828
Ethernet cable, Cat5e, 2 ft. cut to length | 1 | Cables 2 Go | 00392 | Cables 2 Go | 00392
Wire, 18 AWG black, 16/30 strand | as needed | Alpha Wire | 3055 BK005 | Mouser | 602-3055-100-02
Wire, 18 AWG white, 16/30 strand | as needed | Alpha Wire | 3055 WH005 | Mouser | 602-3055-100-01
Wire, 18 AWG green, 16/30 strand | as needed | Alpha Wire | 3055 GR005 | Mouser | 602-3055-100-04
Wire, 18 AWG red, 16/30 strand | as needed | Alpha Wire | 3055 RD005 | Mouser | 602-3055-100-03
Wire, 26 AWG black, 7/34 strand | 12" | Alpha Wire | 3049 BK005 | Mouser | 602-3049-100-2
Wire, 26 AWG wire wrap | as needed | Jonard Tools | R26B-0100 | Digikey | K327-ND
Connector,terminal block, 2 position | 1 | Adam Tech | EBKA-02-A | Digikey | 2057-EBKA-02-A-ND
Connector,terminal block, 2 position | 1 | Phoenix Contact | 5454948 | Digikey | 5454948-ND
Connector,terminal block, 2 position | 1 | Phoenix Contact | 5454935 | Digikey | 5454935-ND
Connector, receptacle, 2 position | 2 | TE Connectivity | 3-640442-2 | Digikey | A30986-ND
Connector, receptacle, 4 position | 1 | TE Connectivity | 1-480424-0 | Digikey | A1431-ND
Connector, receptacle, 5 position | 1 | Molex | 0009503051 | Digikey | WM2103-ND
Connector, receptacle, 13 position | 1 | Molex | 0009503131 | Digikey | 23-0009503131-ND
connector contacts, 18-24AWG, crimp | 7 | Molex | 0008500106 | Digikey | WM2300-ND
connector contacts, 18-24AWG, crimp | 2 | TE Connectivity | 61117-2 | Digikey | 61117-2-SI-ND
Screws, 2-56,1/2" length, 18-8 stainless steel | 2 | McMaster Carr | 91772A081 | McMaster Carr | 91772A081
Nuts,2-56, 18-8 stainless steel | 2 | McMaster Carr | 91841A003 | McMaster Carr | 91841A003
Flat washers, #2, 18-8 stainless steel | 2 | McMaster Carr | 92141A003 | McMaster Carr | 92141A003
Split lock washers, #2 18-8 stainless steel | 2 | McMaster Carr | 92146A520 | McMaster Carr | 92146A520
Screws, 4-40, 3/8" length, 18-8 stainless steel | 5 | McMaster Carr | 91772A108 | McMaster Carr | 91772A108
Nuts, 4-40, 18-8 stainless steel | 3 | McMaster Carr | 91841A005 | McMaster Carr | 91841A005
Locknuts w/external lock washers, 4-40, 18-8 stainless steel | 2 | McMaster Carr | 96278A005 | McMaster Carr | 96278A005
Flat washers, #4, 18-8 stainless steel | 3 | McMaster Carr | 92141A005 | McMaster Carr | 92141A005
Internal tooth lock washers, # 4, 18-8stainless steel | 3 | McMaster Carr | 91757A101 | McMaster Carr | 91757A101
Screws, 6-32, 3/8" length, 18-8 stainless steel | 24 | McMaster Carr | 91772A144 | McMaster Carr | 91772A144
Locknuts w/external lock washers, 6-32, 18-8 stainless steel | 2 | McMaster Carr | 96278A007 | McMaster Carr | 96278A007
Flat washers, #6, 18-8 stainless steel | 24 | McMaster Carr | 92141A008 | McMaster Carr | 92141A008
Internal tooth lock washers, # 6, 18-8 stainless steel | 24 | McMaster Carr | 91757A103 | McMaster Carr | 91757A103
Hex standoffs, aluminum, 6/32 thread, 1/2" long, f-f | 8 | McMaster Carr | 91780A127 | McMaster Carr | 91780A127
Hex standoffs, aluminum, 6/32 thread, 1/2" long. m-f | 4 | McMaster Carr | 93505A442 | McMaster Carr | 93505A442
Hex standoffs, aluminum, 6/32 thread, 1" long, m-f | 4 | McMaster Carr | 93505A446 | McMaster Carr | 93505A446
Varnish | as needed | MG Chemicals | 4228-55ML | SLI | SXX3000-6532
Heat shrink tubing, 1/16" diameter | as needed | 3M | FP301-1/16-48" | Mouser | 5174-11161
Heat shrink tubing, 1/4" diameter | as needed | 3M | FP301-1/4-48" | Mouser | 5174-1141
Heat shrink tubing, 3/8" diameter | as needed | 3M | FP301-3/8-48" | Mouser | 5174-1382
SAM-E PWA | 1 | S2 | SAM-E | S2 | SAM-E

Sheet: LenelS2 Supplied Items
M1-3200 Test Fixture BOM
Description | Quantity | Manufacturer | Manufactuer's p/n | Supplier | Supplier's p/n
LenelS2 M1-3200 test board Test PWA | 1 | LeneS2 | M1-3200 Test fixture | LeneS2 | M1-3200 Test fixture PWA
UGREEN 2 Pack USB Extension Cable (3 FT+ 3 FT), Nylon Braided Extender Compatible With Webcam, Camera, Phone, Hub, Mouse, Keyboard, Printer, Hard Drive, Headset | 1 | UGREEN GROUP LIMITED | 10495P | LenelS2 | TBD
Fanless test fixture PC, Intel Atom or better, 4 GB RAM minimum, 128 GB storage minimum | 1 | TBD | TBD | LenelS2 | TBD
Wireless thermal label printer, USB and Wi-Fi, 300 dpi, up to 110 labels/minute, black and red printing | 1 | Brother | QL-810WC | LenelS2 | TBD
Acer SD Card Reader, USB A 3.0 to Micro Memory Card Reader Aluminum | Dual Slot SD to USB Adapter for Computer, PC, Laptop and Type A Devices, Compatible with SD/Micro SDXC/SDXC/SDHC/MMC/TF Cards | 1 | Acer | ODK550 | LenelS2 | TBD
PNY 32GB Elite Class 10 U1 V10 SDHC Flash Memory Card - 100MB/s Read, Class 10, U1 Full HD, UHS-I, Full Size SD | 1 | PNY | SD32GX5U1100EL-MP | LenelS2 | TBD
DTECH 3ft USB to TTL Serial Cable 3.3V 6 Pin UART Adapter Genuine FTDI FT232RL Chip Debug Cord Compatible with Windows 11 10 8 7 Linux MAC OS 6Pin 3v3 Level Signal 2.54mm Dupont Female Header |  | DTECH | DT-6554-1.0M | LenelS2 | TBD
Estimated M1-3200 total: | $1000
MNPlus Add-ins Test Fixture BOM
LenelS2 ACM (aka mercury test board) test board Test PWA | 1 | LeneS2 | M1-3200 Test fixture | LeneS2 | ACM test board
Mean Well IRM-60-48ST AC to DC Power Supply | 1 | Meanwell | IRM-60-48ST | LenelS2 | TBD
Relay Board for Raspberry Arduino Relay Module 1 Channel Opto-Isolated High or Low Level Trigger (12V) |  | ACEIRMC | 16300 | LenelS2 | TBD
Systems POE-INJ-1000-WT High PoE 4 Pair Injector |  | TYCON SYSTEMS, INC | POE-INJ-1000-WT | LenelS2 | TBD
Estimated MNPlus total: | $1200

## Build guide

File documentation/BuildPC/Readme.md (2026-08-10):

# Build PC Software Requirements

Software required on a workstation used to build `m1-platform-work` components
(firmware, Snap packages, and Teensy/PlatformIO firmware).

## OS

Ubuntu is required for development — other OSes (macOS, Windows, WSL, other Linux distros) are not
supported for building or running this platform's build/deploy tooling. Ubuntu 26.04 LTS is recommended
(matching `base: core22` used by the platform Snaps).

## Base packages

```bash
sudo apt update
sudo apt install -y build-essential make git python3 python3-pip
```

- `build-essential` / `make` — required by `components/stm32mp1-baremetal` and
  general native builds.
- `git` — component subrepos are each independently git-tracked.
- `python3` — required alongside `make` by the STM32MP1 bare-metal build (see
  [STM32MP1-ICT-FIRMWARE.md](STM32MP1-ICT-FIRMWARE.md)).

## Node.js

Node 24.x is required to build and run the Snap-packaged components
(`m1tfc`, `m1-rest-server`, `m1-operator-ui`). Install via
[nvm](https://github.com/nvm-sh/nvm) or the NodeSource repository:

```bash
nvm install 24
nvm use 24
node -v
```

## Snapcraft

Required to build the platform Snaps (`m1tfc`, `m1tfc-rest-server`,
`gui-react`, all `base: core22`):

```bash
sudo snap install snapcraft --classic
sudo snap install lxd
sudo usermod -aG lxd $USER
sudo lxd init --auto
```

Log out and back in (or `newgrp lxd`) after the `usermod` step for the group
change to take effect.

## VS Code + PlatformIO

Install [VS Code](https://code.visualstudio.com/) with the **PlatformIO IDE**
extension. Required to build and program:

- `components/acm-testboard-fw` — PlatformIO Teensy firmware for the ACM test
  board.
- `components/m1testBoardFw` — M1 fixture Teensy firmware, built via
  PlatformIO (`pio run --environment teensy41`).

## Arm GNU Toolchain

Required only for `components/stm32mp1-baremetal` (STM32MP1 ICT bare-metal
FSBL). See [STM32MP1-ICT-FIRMWARE.md](STM32MP1-ICT-FIRMWARE.md) for the exact
toolchain version, install path, and build steps — it is a separate,
standalone `arm-none-eabi` toolchain, distinct from the Node and PlatformIO
toolchains used elsewhere on this platform.

## Other

- `curl` — used to exercise the REST server locally (`curl
  http://localhost:3300/config`) during verification.
- SSH access configured for `github.com:lbuchman/*` component repos (each
  `components/*` folder is pushed/pulled independently).

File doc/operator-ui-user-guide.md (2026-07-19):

# M1 Operator UI Guide

This guide covers normal operator use of the React-based M1 production test panel. It does not replace fixture loading, board handling, or site-specific safety procedures.

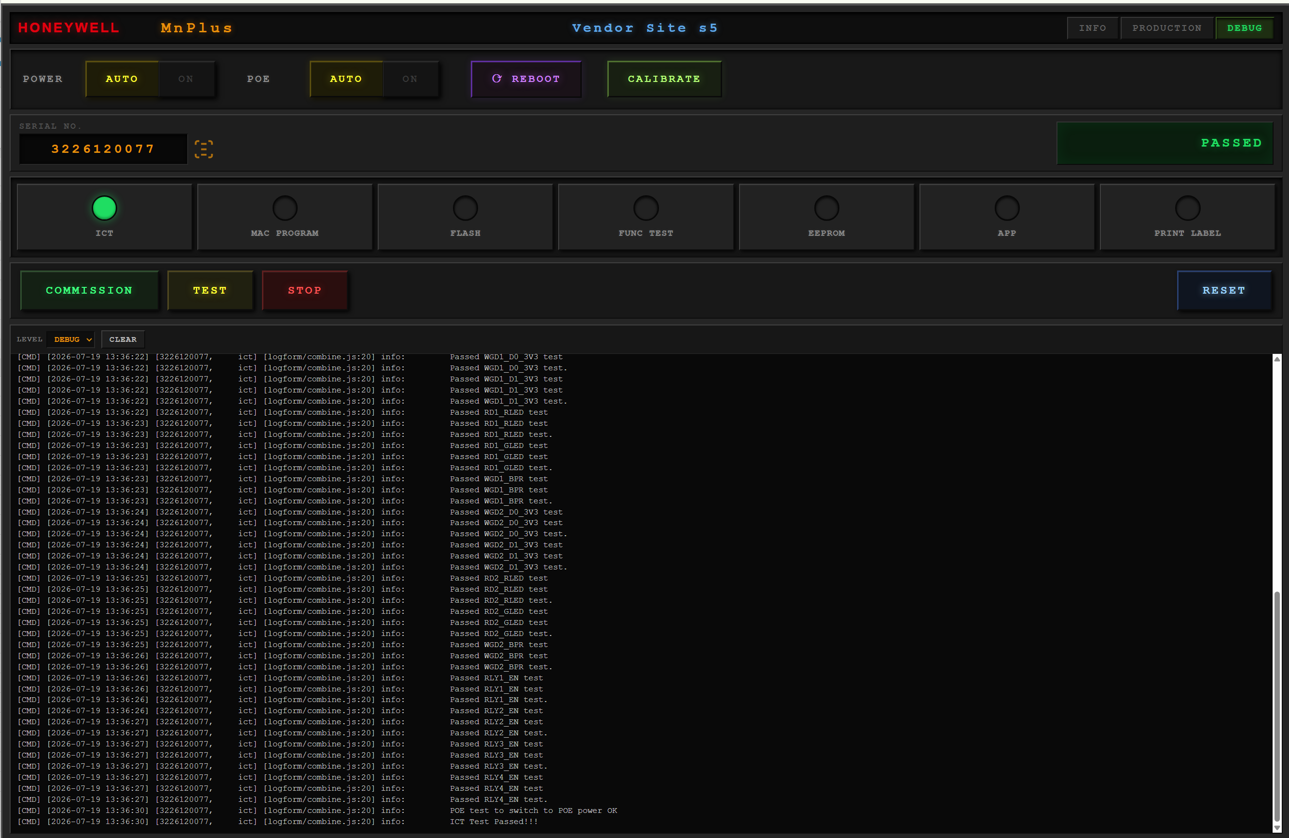
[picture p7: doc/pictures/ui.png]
M1 Operator UI reference screen


## Before You Start

1. Confirm that the fixture PC, REST service, M1 test fixture, and UUT are ready according to the site procedure.
2. Load the UUT in the fixture and establish the required fixture contact before starting a run.
3. Confirm the M1TFC REST service is reachable. The UI normally connects to `http://<fixture-pc>:3300`; development defaults to port `3300` on the current host.
4. Have the 10-digit board serial number available. The UI accepts digits only and will reject any other length.

The fixture label shown in the title bar comes from the REST server configuration. Select **INFO** to view the UI, React, Snap, and expected firmware versions. Those values are expected-state information; hardware-read firmware verification remains part of the fixture procedure.

## Choose A Mode

The panel starts locked. Select **PRODUCTION** or **DEBUG** and enter the authorized PIN when prompted.

**Production mode** is the normal manufacturing path.

- Power and PoE controls are held in automatic mode.
- The log panel shows failure information rather than the full log.
- A serial number that just completed a fully passing production run cannot be run again until a different serial is entered.

**Debug mode** is for authorized fixture diagnosis.

- The full log is visible, with `INFO`, `DEBUG`, and `TRACE` detail levels.
- Individual test steps can be selected directly.
- Power, PoE, reboot, and ICT calibration controls are available.
- Moving from production to debug requires re-authentication before a later return to production.

The UI locks after 90 minutes without input. It reconnects to the log stream after the operator unlocks it again.

## Run A Board

1. Enter or scan the **SERIAL NO.**. It must contain exactly 10 digits.
2. Select **COMMISSION** for the normal full sequence, or **TEST** for a re-test.
3. Watch the overall status and the individual step indicators. The current step is yellow; completed steps turn green; a failed or stopped step turns red.
4. Wait for **PASSED**, **FAILED**, or **STOPPED** before removing the UUT or starting another action.

The full commissioning sequence is:

1. ICT
2. MAC PROGRAM
3. FLASH
4. FUNC TEST
5. EEPROM
6. APP
7. PRINT LABEL

A re-test runs the same order but skips **FLASH**. ICT uses the existing cell-battery tolerance during a re-test; a full commissioning run uses the new-board tolerance path.

The run stops at the first failed step. If a step other than **PRINT LABEL** fails, the UI attempts to print an error label. After every fully passing sequence, it sends the fixture `cleanup` command and records the serial as passed for the current UI session.

## Interpret Results

- **READY**: no active run and no final result yet.
- **RUNNING**: a command or sequence is in progress.
- **PASSED**: every selected sequence step passed.
- **FAILED**: a command failed, the serial was invalid, or the serial was blocked because it already passed in production mode.
- **STOPPED**: the operator stopped the active command.

In debug mode, a failed run displays a failure summary above the log. In production mode, the log area is titled **FAILED TESTS** and suppresses normal progress lines.

Use **CLEAR** to clear the server log and the displayed log lines. Use **RESET** to clear the UI result, progress, indicators, and failure summary; it does not run a fixture cleanup command or clear the server log.

## Debug Controls

Use these controls only under the applicable engineering or fixture procedure:

- Select an individual step indicator to run that command by itself.
- **POWER** and **POE** send the corresponding fixture command; **AUTO** sets the local UI state to automatic and sends the off command to the fixture.
- **REBOOT** asks for confirmation before sending the target reboot command.
- **CALIBRATE** asks for confirmation, then runs ICT with `--calibrate true`.
- **STOP** asks for confirmation, requests `/command/stop`, and aborts the browser-side active command stream.

Calibration changes persistent test-board data under `/etc/m1platform/calibration.json`. It must be performed only on the correct fixture and with a successful persistent write, not merely a successful displayed result. Verify every calibrated voltage with a meter. Use the approved Golden Board as the reference for the expected voltage values; do not accept calibration solely from software-reported measurements.

## Logs And Connectivity

After unlock, the UI loads the most recent 120 log lines, then listens to the REST server's Server-Sent Events log stream. The displayed history is limited to the most recent 500 lines.

A disconnected or reconnecting log indicator means the log stream is unavailable; it does not by itself prove a fixture test has stopped. Check the current command status, REST service health, fixture connections, and saved logs before deciding the test result.

Use the browser's downloaded debug log only as a local operator copy. The fixture log configured by the REST service remains the production record.

## Communication Summary

| UI Function | REST Interface |
| --- | --- |
| Read fixture label and expected version fields | `GET /config` |
| Start normal or debug command | `POST /command/stream` |
| Stop active streamed command | `POST /command/stop` |
| Read recent log history | `GET /logs/tail?lines=120` |
| Receive live log lines | `GET /logs/stream?lines=1` via Server-Sent Events |
| Clear server log | `POST /logs/clear` |
| Authenticate or change mode PIN | `POST /auth` |
| Change a mode PIN | `POST /changepin` |

The REST server serializes fixture commands so that concurrent UI actions do not contend for the same hardware interfaces.

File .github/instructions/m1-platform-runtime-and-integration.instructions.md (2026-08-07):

---
description: Use when modifying components that cross firmware/software/runtime boundaries (m1tfc, m1-rest-server, m1-operator-ui, m1-fixture-agent) or when changing manifests, build, publish, install, or version reporting behavior.
applyTo: components/**
---

## Integration Contract

- Treat command APIs and runtime files as cross-component contracts.
- If a field/option/command changes on one side, verify the other side in the same change scope.
- Do not silently change externally visible behavior.

## Runtime Contract

Runtime source-of-truth files:
- /etc/m1platform/config.json
- /etc/m1platform/calibration.json
- /var/m1mtf/

Config keys that are operationally relevant (names only):
- tfInterface, vendorSite, productName, fwDir, mtfDir, programmingCommand
- skipBatteryTest, skipRS485test, skipTestpointCheck
- coinCellMinVoltageNew, coinCellMinVoltageUsed

Sensitive config keys (never print values):
- conString
- productionPassword
- debugPassword

Calibration metadata (safe schema-level facts):
- root object key: boards
- boards slot count: 20
- uniform slot schema across slots

## Version Reporting Contract

- UI should show distinct values for UI app, REST server, m1tfc, and m1-fixture-agent.
- REST /config should expose explicit version fields for each displayed component.
- Use installed snap metadata for actual installed versions.

## Build and Publish Contract

- Build from clean component repositories for full production-style version stamping.
- Publish artifacts and manifest together; do not publish partial sets.
- After publish, trigger fixture-agent polling/restart if immediate install is needed.

## Validation Expectations

After editing integration paths:
1. component tests
2. component build/lint where applicable
3. end-to-end version/install verification through manifest + installed snap list

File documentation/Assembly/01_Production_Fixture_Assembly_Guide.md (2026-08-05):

**Production Fixture Assembly Guide**

*Initial factory build and verification baseline*

Version 1.0 \| July 25, 2026\
Owner: Leo Buchman\
Status: Initial controlled draft

  -------------------------------------------------------------------------------------------
  Document Type                       Factory Assembly Guide
  ----------------------------------- -------------------------------------------------------
  Platform                            M1/MNPlus EVM

  Scope                               Hardware / architecture

  Source Baseline                     Schematics, platform diagram, physical configurations
  -------------------------------------------------------------------------------------------

# 1. Purpose and Status

This initial guide records the known production-fixture architecture and the factory-document package required to build the enclosure and assemble the platform. Exact part numbers, wire lengths, torque values, connector tables, and controlled CAD drawings must be inserted from released manufacturing sources before the guide is used as a production work instruction.

# 2. Assembly Overview



*Figure 1 - Completed production fixture example*

# 3. Major Assemblies

- Enclosure and back-panel interfaces

- Mechanical lever and UUT retention structure

- Product-specific fixture plate

- Pogo-pin bed and wiring interface

- M1 Test Board

- ACM Controller Test Board

- SAM-E Ethernet switch

- PoE injector

- 12.5 V / 5 V power supply

- 48 V power supply and relay

- USB hub

- Fanless PC

- Operator lever switch and status LED

- Internal harnesses and terminal blocks

# 4. Required Controlled Inputs

  ---------------------------------------------------------------------------------------------------
  **Artifact**                        **Status in this draft**
  ----------------------------------- ---------------------------------------------------------------
  Released BOM                        Required - not yet supplied

  Enclosure/mechanical drawings       Required - CAD available from Leo

  Plate drawing and pogo map          Required for each UUT variant

  Harness drawings                    Required - not yet supplied

  Power wiring diagram                Architecture known; production detail required

  Board source packages               Schematics available; complete manufacturing package required

  PC image and configuration          Separate software/operations document required

  Factory Acceptance Test             Initial checklist below; detailed limits required
  ---------------------------------------------------------------------------------------------------

# 5. Recommended Assembly Sequence

1\. Inspect enclosure and mechanical parts

2\. Install power supplies, protected mains wiring, and grounding

3\. Install terminal blocks, relay, PoE injector, USB hub, and SAM-E switch

4\. Install M1 and ACM test boards on approved standoffs

5\. Install fanless PC and network/USB connections

6\. Install product-specific plate and pogo-pin assembly

7\. Route and secure internal wiring using controlled harness drawings

8\. Verify continuity, polarity, grounding, and insulation

9\. Apply power without a UUT and verify all unloaded rails

10\. Load approved PC image and board firmware

11\. Run Factory Acceptance Test with the approved golden UUT

12\. Record serial number, configuration, and release results

# 6. Initial Factory Acceptance Checklist

- Visual inspection complete

- Protective earth / chassis ground verified

- 12.5 V rail verified

- 5 V SAM-E rail verified

- 48 V rail and relay control verified

- USB devices enumerated

- Ethernet communication established

- M1 Test Board self-test passed

- ACM Controller Test Board self-test passed

- Pogo-pin continuity/contact verified

- Golden UUT programming and recovery verified

- Serial testing passed

- Ethernet/PoE testing passed

- Operator lever and status indication passed

- Results and configuration recorded

# 7. Safety Hold Point

This draft must not replace released electrical-safety and manufacturing work instructions. Mains wiring, protection, fusing, grounding, and enclosure requirements require formal review and approval.

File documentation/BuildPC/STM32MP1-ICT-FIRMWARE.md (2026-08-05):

# STM32MP1 ICT Firmware

`components/stm32mp1-baremetal` is the STM32MP1 bare-metal firmware component
used by ICT. ICT must execute without Linux running on the target: SDRAM is a
test subject, so Linux cannot own, initialize, or use the memory under test.
The component is therefore a standalone firmware repository, separate from the
Snap-packaged host-side tools.

Its build requires Arm GNU Toolchain `12.2.MPACBTI-Rel1` at:

```text
/opt/arm-gnu-toolchain-12.2.mpacbti-rel1-x86_64-arm-none-eabi
```

This `arm-none-eabi` toolchain is required only by
`components/stm32mp1-baremetal`. It is not the Node toolchain used by Snap
components or the PlatformIO toolchain used by Teensy firmware. GNU Make and
Python 3 are also required.

Build the FSBL from the component root:

```bash
cd components/stm32mp1-baremetal
source env.sh
arm-none-eabi-gcc --version
make clean
make
```

`env.sh` must be sourced in the same shell as `make`; it adds the required ARM
compiler and binutils to `PATH`.

The STM32MP1 component builds from its root `Makefile`; its active firmware
layout is `src/`, `include/`, `third-party/`, and `tools/`. A successful build
produces:

```text
build/fsbl.elf
build/fsbl.bin
build/fsbl.stm32
```

`build/fsbl.stm32` is the STM2 BootROM image to use for the target. It includes
the BootROM header and checksum generated from the `.bin` artifact; do not use
the `.elf` or `.bin` in its place.

`make` only builds the image. `make install` stages the built FSBL at
`/var/m1mtf/fsbl.stm32` for the normal ICT command path. `make load` is a
separate interactive SD-media operation that writes the first two boot
partitions; run it only after the approved provisioning path and target device
identity have been verified.

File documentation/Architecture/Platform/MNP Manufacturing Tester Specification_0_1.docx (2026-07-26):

M1-3200

Manufacturing Tester

LenelS2

Document Change Record

Revision Number | Date: | Description: | Author:
1.0 | 09/27/2024 | Initial | LB

List of Tables

List of Figures

# 1. INTRODUCTION

The following document gives an overview of the hardware, software and system configuration for the MNP tester.

The test system is intended to test and program MNP boards. The test system is a standalone system that is connected to a PC. The PC contains software image, diagnostics and serves requests from the MNP under test.

# 2. References

The documentation files placeholder link on Teams for M1-3200 test fixture - M1-3200 Test Fixture (https://carcgl.sharepoint.com/:f:/r/sites/SAMSAM-EHWDesign/Shared%20Documents/General/M1-3200%20Test%20Fixture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)

Table 1 Supporting Documentation

Doc # | Document Name | Revision | File | Author
1 | Manufacturing Test Fixture for M1-3200 | 1.0 | All documentation | team
2 | Mercury Custom testing board PDF | latest | Mercury Custom Test Board.PDF | Leo Buchman

# 3. M1-3200 test fixture vs MNO test fixture

MNP tester is based on M1-3200 tester. The PC software and test flow is the same. The difference between M1-3200 & MNP fixtures:

a. MNP test box has an additional custom test board to test access control blade functionality on MNP
b. MNP test box has an additional 48V power supply and POE injector to test MNP POE functionality
c. The pogo-pins map is different between M-3200 and MNP test stations

# 4. Testing Station

Figure 1 System Diagram

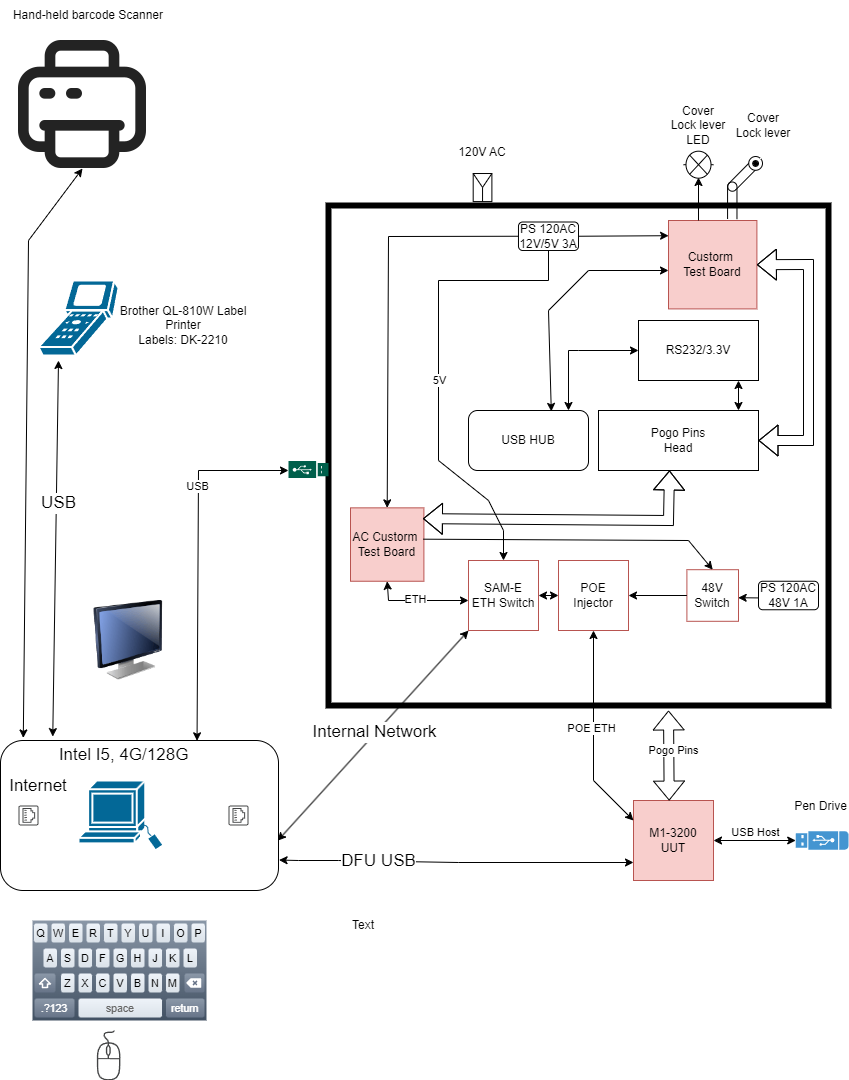
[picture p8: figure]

The testing station box consist of the following components:

1. Test Fixture box with the pogo pins head to provide connections to UUT, 24AWG stranded wire.
2. PC with monitor, keyboard, and mouse.
3. Label printer.
4. RS232 to 3.3V serial TTL.
5. 4-port USB HUB.
6. 12V/3A open frame power supply.
7. Custom test board.
8. Access Control custom test board
9. AC/DC 48V power supply
10. Custom DC/DC SSR
11. SAM-E Board as Ethernet switch
12. USB Pen drive with 1 EXT4 partition, Samsung 128GB.
13. 3-D barcode scanner.
14. USB mini, micro, and Cat-5 cables

## 4.1 Test Fixture Box with pogo pins

This component to be engineered and built by Saline. The mechanical drawings have been requested from Saline and not yet available. The whole mechanical design must comply with electrical and mechanical applicable safety codes.

## 3.2 PC

The PC is off the shelf fan-less I5 system with 128GB SSD, 8GB RAM, two Ethernet ports and 4-6 USB ports capable of running Ubuntu 20 (+) operating system.

The PC provides the GUI front end for the operator, runs test cases, programs UUT and manages the testing logs. The PC uses Internet connection to Azure Cloud to store logs, retrieve UUT FW, and automatically update itself. PC shall have all required drivers installed to operate test fixture hardware.

## 3.3 Label Printer

The label printer is Brother QL-810W(C) label printer. The label with the UIT Product Type, UID, serial #, MAC address is printed when the testing procedure successfully complete, otherwise an Error Label is printed with the failed test name.

## 3.4 RS232 to 3.3V serial TTL

This is DTECH USB to UART TTL Cable, the model is DT-6554.

The cable provides a connection for the serial terminal (J25) on UUT to the PC.

## 3.5 4-port USB HUB

Only used to reduce USB cables count. Connected to the PC on one end and to the RS232 UUI connector and custom board MCU.

## 3.6 Custom test board

The custom test board is a custom I/O extension board used to aid the PC in probing the test points voltages, control GPIOs and test serial buses. The board has its own firmware and is controlled over the serial link. It uses a Cortex32 ARM processor, bare metals system based on Teensy 4.1 development board.

## 3.7 USB Pen drive

The USB Pen drive shall be directly plugged into the UUT. It must have a small form factor to fit in to constrained space around UUT J13. Samsung 128 high speed small pen drive is a good choice for this. The drive shall have 1 EXT4 partition on it.

## 3.8 Barcode scanner

To read Saline serial number from UUT.

## 3.9. Cabling

Generic USB mini and micro and CAT5 cables.

# 5. Wiring Map

Notes:

PP - pogo pin

TB - custom test board

Dest - wire connects to

Tolerance - required tolerance to pass

Table 2 Wiring Map

M1-3200 | Wire, Gauge | Dest | Name | Voltage Level | Tolerance
PP TP025 | 24-26 | TB J6.2 | M1-3200 Internal VCC | 5V | 5%
PP TP33 | 24-26 | TB J6.7 | PMIC VCC_ANGL | 2.9V | 5%
PP TP35 | 24-26 | TB J6.6 | PMIC VCC_P3V3_AUX | 3.3V | 5%
PP TP34 | 24-26 | TB J J6.5 | PMIC VCC_P3V3 | 3.3V | 5%
PP TP31 | 24-26 | TB J J6.4 | PMIC VDD_DDR | 1.1V | 5%
PP TP36 | 24-26 | TB J J6.3 | PMIC VDD_CORE | 1.2V | 5%
PP J14.1 | 24-26 | TB J J6.1 | Coin Cell 3.0V backup battery | 3.3V | 15%
PP P3.2 | 24-26 | TB J J6.8 | Boot select, TB OD output | N/A | N/A
PP J5.9 | 24-26 | TB J J5.9 | Ribbon RS-422 | N/A | N/A
PP J5.10 | 24-26 | TB J J5.10 | Ribbon RS-422 | N/A | N/A
PP J5.11 | 24-26 | TB J J5.11 | Ribbon RS-422 | N/A | N/A
PP J5.12 | 24-26 | TB J J5.12 | Ribbon RS-422 | N/A | N/A
PP J5.18 | 24-26 | TB J J5.18 | Ribbon AIO_S0 | Log 0 or 1 | 0.8V/2.7V
PP J5.15 | 24-26 | TB J J5.15 | Ribbon AIO_S1 | Log 0 or 1 | 0.8V/2.7V
PP J5.16 | 24-26 | TB J J5.16 | Ribbon AIO_S2 | Log 0 or 1 | 0.8V/2.7V
PP J5.19 | 24-26 | TB J J5.19 | Ribbon AIO_S7 | Log 0 or 1 | 0.8V/2.7V
PP J5.17 | 24-26 | TB J J5.17 | Ribbon AIO_nRST | Log 0 or 1 | 0.8V/2.7V
PP J5.5 | 24-26 | TB J J5.5 | Ribbon VCC_P6V | 6V | 5%
PP J5.7 | 24-26 | TB J J5.7 | Ribbon VCC_P6V | 6V | 5%
PP J5.13 | 24-26 | TB J J5.13 | Ribbon VCC_P12V | 12V | 5%
PP J5.8 | 24-26 | TB J J5.8 | Ribbon VCC_P6V | 6V | 5%
PP J5.14 | 24-26 | TB J J5.14 | Ribbon VCC_P12V | 12V | 5%
PP J5.23 | 24-26 | TB J J5.23 | Ribbon Ground | 0V | 5%
PP J5.25 | 24-26 | TB J J5.25 | Ribbon Ground | 0V | 5%
PP J5.20 | 24-26 | TB J J5.20 | Ribbon Ground | 0V | 5%
PP J5.22 | 24-26 | TB J J5.22 | Ribbon Ground | 0V | 5%
PP J5.24 | 24-26 | TB J J5.24 | Ribbon Ground | 0V | 5%
PP J5.26 | 24-26 | TB J J5.26 | Ribbon Ground | 0V | 5%
PP J07.1 | 24 | TB J J10.1 | Incoming Power 12V | 12V | 5%
PP J07.2 | 24 | TB J J10.2 | Incoming Power Ground | N/A | N/A
PP J08.1 | 24-26 | TB J J9.1 | Tamper Ground | N/A | N/A
PP J08.2 | 24-26 | TB J J9.2 | Tamper Signal | Log 0 or 1 | 0.8V/2.7V
PP J02.1 | 24-26 | TB J J8.1 | Led Blue | -2.6V:-3.3V | 5%
PP J02.1 | 24-26 | TB J J7.1 | Led Red | 1.6V:2.2V | 5%
PP J27.1 | 24-26 | TB J J1.8 | RS-485 DP | N/A | N/A
PP J27.2 | 24-26 | TB J J1.7 | RS-485 DN | N/A | N/A
PP J06.1 | 24 | TB J11.1 | Incoming Battery +12V | >11V | N/A
PP J06.2 | 24 | TB J11.2 | Incoming Battery Ground | N/A | N/A
J13 | | | M1-3200 USB Mini DFU port Connected to PC USB port | N/A | N/A
J11 | | | M1-3200 Ethernet port Connected to PC Ethernet port 1
PP J25.4 | 24 | DT-6554 Pin 4 | Debug Port Rx, DT-6554 is Connected to PC USB port | N/A | N/A
PP J25.5 | 24 | DT-6554 Pin 5 | Debug Port Tx, DT-6554 is Connected to PC USB port | N/A | N/A
Teensy 4.1 USB Port | | | Connected to PC USB port | N/A | N/A
3-D Scanner | | | Connected to PC USB port | N/A | N/A
Label Printer | | | Connected to PC USB port | N/A | N/A
PC Ethernet port 2 | | | Connected to Internet | N/A | N/A

# 6. SW/FW

Figure 2 SW & FW Map

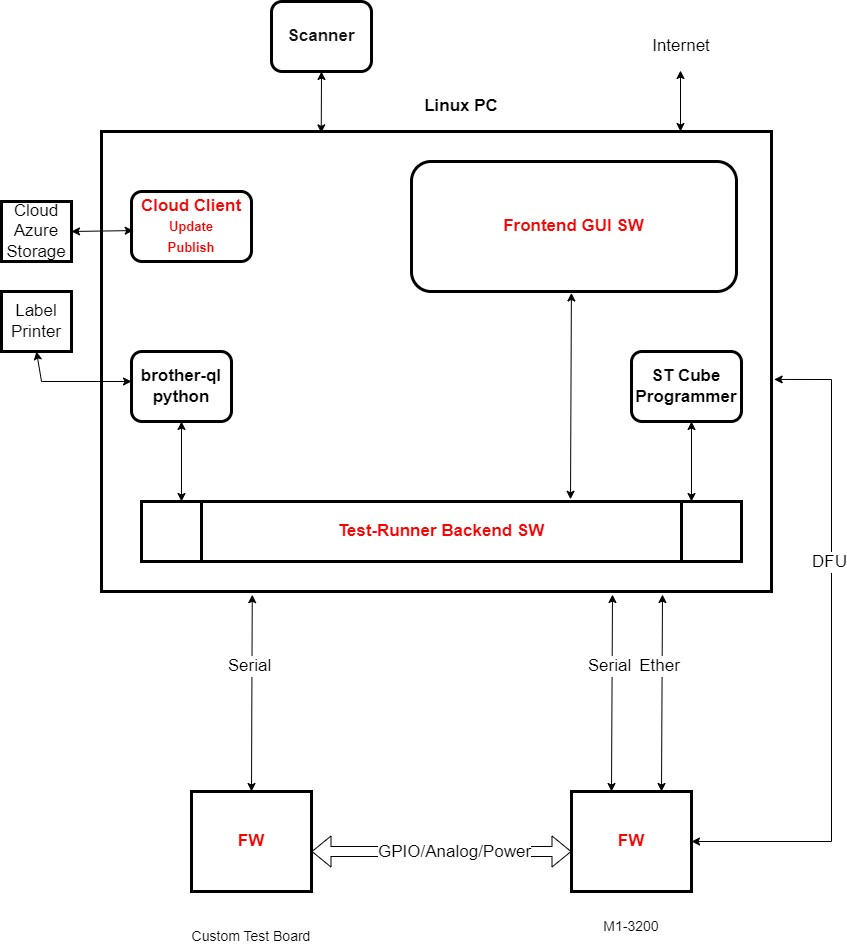
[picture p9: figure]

## 6.1 M1-3200

The different firmware is loaded into M1-3200 for different test fixture operations.

Test | FW | Notes
ICT | Bootstrap FW | Loaded from PC to RAM
MAC Program | U-Boot from released FW | Loaded from PC to RAM
Flash | U-Boot from released FW | Loaded from PC to RAM
Func Test | S2 Released FW | SSD boot
EEPROM Program | Bootstrap FW | Loaded from PC to RAM
Apps Check | S2 Released FW | SSD boot

### 5.1.2 Bootstrap FW

The Bootstrap FW is the bare metal firmware for STM32MP1 CPU. The communication interface to the CPU running Bootstrap FW is the serial 115200 baud connection over M1-3200 debug serial port. The Bootstrap FW allows the PC to access to any STM32MP1 CPU GPIO. Also, Bootstrap FW implements I2C driver for testing I2C buses and I2C EEPROM.

### 5.1.3 S2 Released FW

The firmware generated by Yocto for M1-3200.

## 6.2 Custom Test Board (TB)

The TB is designed with Altium Designer and manufactured by JLCPCB.

MCU is ARM Cortex-M7 IMXRT1062 processor at 600 MHz on add-in Teensy 4.1 development board.

The firmware is written in C++ 14 and downloaded over USB link to the internal FLASH.

The TB populates the same connectors as M1-3200 and the connection is done One-To-One, except J12 Power-In connector which is wired to12.3V/3A power supply. Also, the M1-3200 boot target J6.8, and M1-3200 Rs-485 port are wired to J1.8 and J.7. The terminal block J6 is used to measure the voltages on M1-3200 and connected to M1-3200 corresponding test points.

The are two pushbuttons switches on the test board. Pressing SW1 will apply or cut the power to M1-3200.The state of SW2 controls the M1-3200 boot target. If the switch is pressed while pressing SW1 the M1-3200 will boot from SSD, otherwise from RAM. This allows easy debugging.

The custom test board is controlled over 115200 baud serial link. The connection to the PC is over micro-USB interface on Teensy 4.1.

Custom test boards are hand tested. The analog inputs are tested with voltages from Table 2. The analog circuitry requires no calibration.

Documentation in provided in a firmware sources, see document #4

Figure 3 Custom Test Board 3d-view

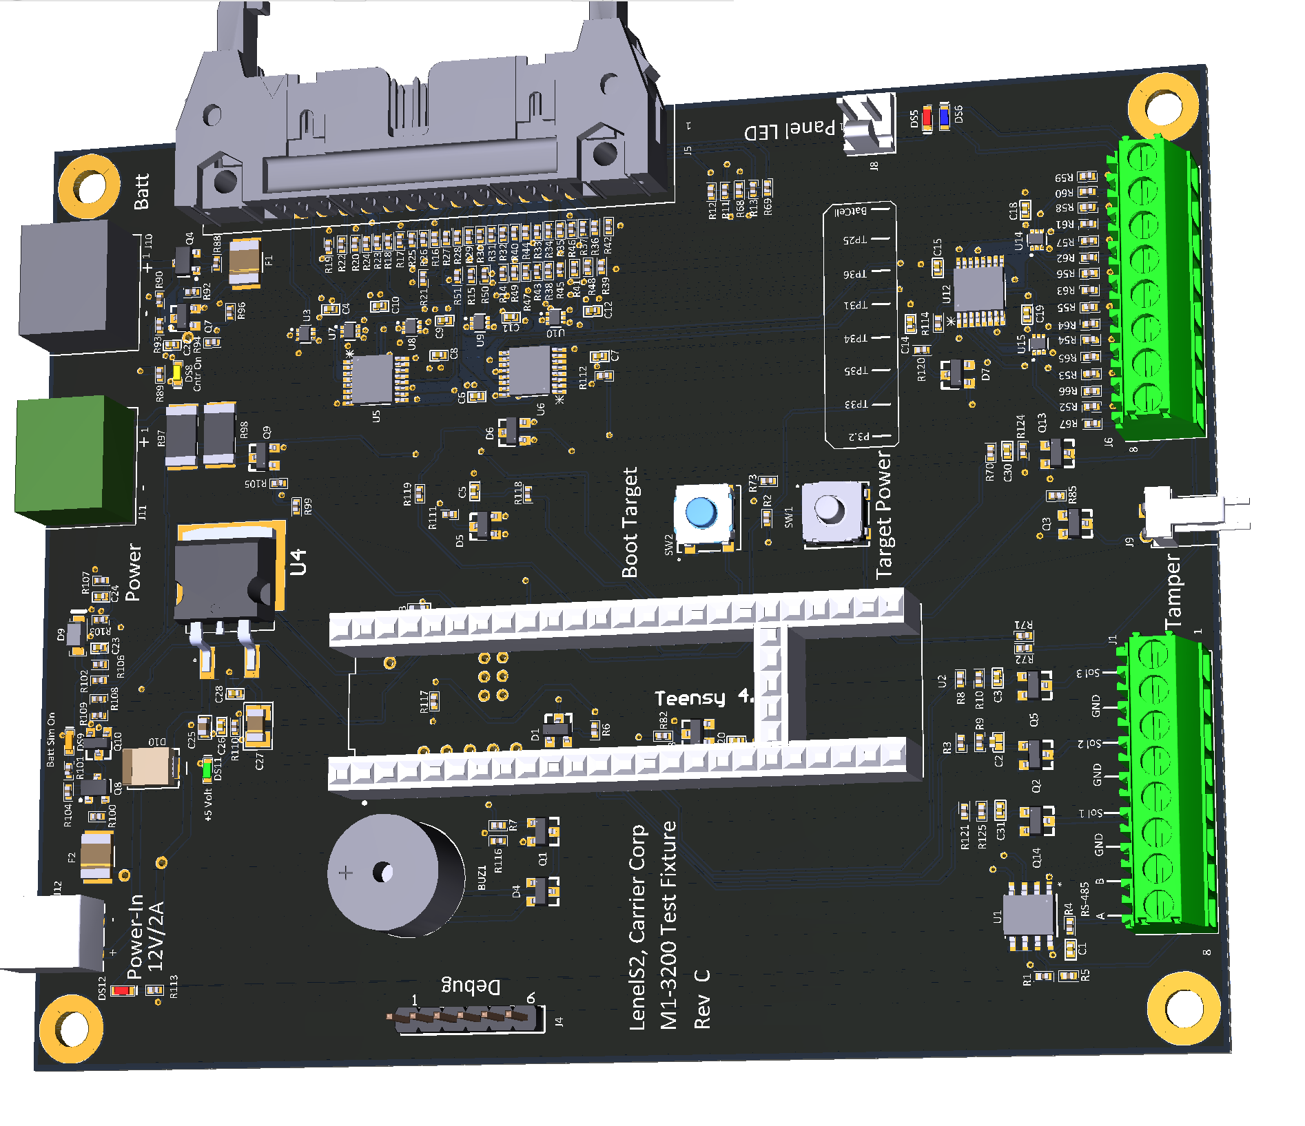
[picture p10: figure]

## 6.3 PC

The PC uses the following third-party SW.

- ST Cube programmer – to program STM32MP1.
- Brother-ql python – to control Brother label printer.

Two custom build Ubuntu Snaps are required to run the test fixture.

### 6.3.1 m1tfd1 Snap

m1tfd1 snap hosts two applications

      1. m1tfd1.app - GUI front end app
      2. m1tfd1.cli - Test runner backend

Test runner backend SW is a nodes app and it executes all test fixture operations. Gui frontend app is not required to run test fixture operations since m1tfd1.cli can be run from the command line.

Gui frontend is a Lazarus application, and it provides an easy graphical interface to the test runner backend SW.

### 5.3.2 m1client Snap

m1client provides m1client applcation

m1client application is run from crontab to perform the following tasks

1. publish logs to the Cloud
2. backup the database to the Cloud
3. publish secrets to the Cloud
4. update M1-3200 production Yocto FW
5. update PC FW.
6. Update STM32MP1 bootstrap fw

lenel@m1testf4:~/M1Combined$ m1client --help

Usage: m1cli [options] [command]

CLI utility retrieve M1-3200 manufacturing logs

Options:

-V, --version output the version number

-h, --help display help for command

Commands:

update [options] download and update software and firmware on the test fixture

synclogs sync logs into Cloud AS

backupdb backup DB to the cloud

syncsecrets sync M1-3200 secrets into Cloud AS

help [command] display help for command

lenel@m1testf4:~/M1Combined$

Big Fat Worning:

m1client update will update

a. Gui and backend testing software
b. M1-3200 bootstrap firmware
c. M1-3200 SSD image which is programmed into M1-3200 SSD
d. The m1client itself. The m1client cannot update itself, therefore it will download the new version but the actual update is scheduled with crond to be done 4AM in the morning.

If update is required right away cd to the directory /home/lenel/ m1mtf/tmp and run the commands below:

#ls -l m1client_*_amd64.snap

#find the latest snap file

#sudo snap install –dangerous –classic m1client_??????_amd64.snap

# 7. Theory of operation

The following operations are supported.

ict - Executes ICT test.

eeprom - program I2C EEPROM.

progmac - program MAC to MP1 OTP, cannot be undone

flash - program STM32M1 with the flash layout file

pushtocloud - pack the log for specified serial and push tarball to the cloud.

pingM1apps – check if M1-3200 except connection on port 80 and check if s2nn is running.

cleanup - clean log file and make tarball for the cloud download.

functest - m1-3200 function test.

makelabel - print the M1-3200 Label.

## 6.1 ict test

This is an ICT test. The test board checks selected PMIC voltages, incoming and battery power, and M1-3200 5V regulator. The values shall be within 5% or expected values. Then the Bootstrap FW is downloaded to M1-3200 and executed. The m1tfd1.cli application sets GPIOs to the desired level on M1-3200 and checks GPIOs with test board A/D. All values shall be within 5% of expected.

## 6.2 eeprom

The eeprom is programmed with Product Type, UID, serial #, and MAC address.

The data is protected with a hash checksum.

## 6.3 progmac

U-Boot is downloaded to STP32M1 RAM. ST Cube programmer programs the MAC value into OTP area and data is locked.

If OTP is not blank the operation does not fail, but the user is informed.

The MAC addresses are managed with the help of sqlite3 database on the PC. The database is updated with the MAC address only if programing OTP succeeds. The new Mac address is recorded along with CPU serial number and board manufacturer serial number. The next available MAC address is calculated as the last used 1.

The database record has CPU and manufacturer serial numbers. This ensures no MAC duplicates are programmed. The database file is backup to Azure Cloud every night.

## 6.4 Flash

ST Cube programmer programs SSD with the flash layout file.

## 6.5 pingM1apps

Boot M1-3200 from SSD. Check that S2 FW apps are running.

## 6.6 makelabel

Prints the M1-3200 label based on the data in EEPROM. The data integrity of EEPROM data is checked.

## 6.7 functest

M1-3200 runs from SSD, normal boot. Peripherals functionality is checked.

# 8. Configuration File

The default configuration is hard coded in the SW.

{

ictFWFilePath: `${process.env.HOME}/m1mtf/fsbl.stm32`,

m1fwBase: `${process.env.HOME}/m1mtf/stm32mp15-lenels2-m1`,

m1mtfDir: `${process.env.HOME}/m1mtf`,

layoutFilePath: `${process.env.HOME}/m1mtf/stm32mp15-lenels2-m1/flashlayout_st-ls2m1-image-core/trusted//FlashLayout_emmc_stm32mp151f-ls2m1-trusted.tsv`,

programmingCommand: `${process.env.HOME}/STMicroelectronics/STM32Cube/STM32CubeProgrammer/bin/STM32_Programmer_CLI`,

m1SerialDev: '/dev/ttyUSB0',

m1defaultIP: '192.168.0.251',

testBoardTerminalDev: '/dev/ttyACM0',

tolerance: 0.05,

login: 'root',

password: '*****',

serialBaudrate: 115200,

conString: 'none',

memTestSize1MBBlocks: 10,

forceEppromOverwrite: false,

vendorSite: 'N1',

skipTestpointCheck: false,

pingPorts: true,

testerMode: 'commission',

progEEPROM: true,

makeLabel: true,

funcTestDisable: false

}

The configuration can be altered by the file /var/snap/m1tfd1/current/config.json

The file format is JSON text file.

{

"conString": "DefaultEndpointsProtocol=https;AccountName=lenels2production;AccountKey=QYLAhAvw4SowA6HJqBm2CTkR3Q36PWxfFUPDhqZ4yEyK6lJNb02GEwS/Z/kF8+qMEPs6VAzSnHHt+AStrIr3VQ==;EndpointSuffix=core.windows.net",

"vendorSite": "p1"

}

Define the following parameters:

conString - connection string to Azure Storage Account.

vendorSite - required for EEPROM serial number, two characters.

Make sure /var/snap/m1tfd1/current/config.json is a valid JSON file or test fixture test runner CLI will not run.

# 9. Test Logs

## 1 Logs

The system logs every process step. Three log levels are available, Error, Info and Debug. The default error log displayed on the screen is Error. Looking into the Info log may help to trouble shoot many issues with the UUT or with the test fixture, like miss-plugged Label printer USB cable. The Debug level is for development purposes.

The log can be found under the directory /home/lenel/m1mtf/logs

Every UUT has its own subdirectory log. That subdirectory name is UUT Saline serial number.

Change directory to /home/lenel/m1mtf/logs/[SERIALNUMBER]

Execute #ls -l

The files will be displayed

lenel@m1testf4:~/m1mtf/logs/3023200042$ ls -l

total 228

-rw-rw-r-- 1 lenel lenel 125490 Aug 4 14:44 3023200042-debug.log

-rw-rw-r-- 1 lenel lenel 22459 Aug 4 14:40 3023200042_dump.log

-rw-rw-r-- 1 lenel lenel 2956 Aug 4 14:44 3023200042-error.log

-rw-rw-r-- 1 lenel lenel 66889 Aug 4 14:44 3023200042-info.log

To display the file execute

# cat 3023200042-info.log

The logs are automatically archived and transmitted to Azure Cloud overnight. The logs from the cloud can be retrieved by logging into the LenelS2 Azure account and by the special CLI utility which was developed as a part of this project.

If the logs and secrets can be pushed to the Cloud from the Gui App Cloud Menu.

## 2 Secrets

The secrets file is created every night from the information available in the database and transmitted to the azure Cloud in text delimited file format. The information in the file is BASE32 and encrypted with LenelS2 public key.

The secrets file can be retrieved from the cloud by logging into the LenelS2 Azure account and by the special CLI utility which was developed as a part of this project.

## 3 Gui App Log Level

The Gui App log level default is Error. The log level can be changed with the keyboard shortcut. Press Cnrl + Alt + Shift + 0 for the Error log level, Press Cnrl + Alt + Shift + 1 for the Info log level. If Debug log level is required press Cnrl + M

# 10. Software and Firmware updates

The test fixture software and M1-3200 firmware updates are done automatically by the PC. The crontab job will execute an update every night.

The updates are downloaded from the Azure Cloud, the updates integrity hash is checked and then installed.

The updates can be uploaded to the Cloud manually, but it is not advisable because it is error prone. Instead m1CloudClient utility (see below) shall be used to update the Cloud.

The m1CloudClient is a CLI utility which was developed as a part of this project can handle uploading updates to the Cloud and generating the proper manifest file for.

The manifest file describes every update component and hash checksum for.

See an example below.

lenel@m1testf4:~/m1mtf/tmp$ cat manifestFile.json

[

{

"filetype": "txz",

"filename": "m1firmware.txz",

"hash": "6aa667ccfe4eca7cc8774b96e85e8b64ce87de8eddc2a0228c9be0beaf8ef971497bfe4d104a327626d99ed145732054997581060d3b6ea254cc988f952860ff"

},

{

"filetype": "stm",

"filename": "fsbl.stm32",

"hash": "ac1efe702294c11dfce1a4e492ef5b56e098b0ab02c53ddec1d56fa35211b2a38e3265e2c06dafbc6086defcea4738e26746f4dde441ed028081b3adcdfc4592"

},

{

"filetype": "snap",

"filename": "m1tfd1_8dcc871_amd64.snap",

"hash": "9ac60485779f1d11d8e7f4643bc7378402bb6878066bf0d177a610a86f2d0be83b1fd1fb05c1695cb338789f50532d8f55b95885334d303cfb7e7478d4ebbe8f"

},

{

"filetype": "snapclient",

"filename": "m1client_8af40c74_amd64.snap",

"hash": "0ba269113dbc1270eaf690a36d10aacc68e11d08f9dac98345ecdf4f05484d11d87bf3bd5f102c545d9f42989f44ba66d8cf43bc4ac631198e8672467e752470"

}

]

# 11. Test Vectors

## 11.1 ICT Test

Power is applied to M1-3200 with the boot target DFU USB. The PC wait for M1-3200 to show up, then bootstrap FW is downloaded with the help of ST Cube Programmer and executed.

The PC reads FW revision from the test board and M1-3200 bootstrap to ensure that both serial links are connected, then test vectors are executed.

Common issues:

  - PS issue.
  - Bad pogo pin connection.
  - Teensy 4.1 USB link to PC, cable?
  - M1-3200 USB link to PC, cable?
  - Custom test board issue?

Table 4 ICT Test Vectors

# | Description | Acceptance Criteria | Operation | Troubleshooting

1 | Check Voltage on TP025 | Value = +5.0V +- 5% | | PMIC? Shorts on UUT
2 | Check Voltage on TP033 | Value = +2.8 +- 5% | | PMIC? Shorts on UUT
3 | Check Voltage on TP33 | Value = +3.3V +- 5% | | PMIC? Shorts on UUT
3 | Check Voltage on TP34 | Value = +3.3V +- 5% | | PMIC? Shorts on UUT
3 | Check Voltage on TP36 | Value = +1.2V +- 5% | | PMIC? Shorts on UUT
4 | J5.13 | Value = +12V +- 5% | | PS issue, wiring?
5 | Check Coin Cell Batt | Value = +3.3V +- 10% | | No battery? UUT? Not fresh battery?
6 | Check Voltage on TP31 | Value = +1.35V +- 5% | PIMIC is programmed for DDR voltage | UUT I2C issue? PMIC?
7 | Ribbon J5.15 | UUT set to 1, TB reads1 UUT set to 0, TB read 0 | | UUT issue
8 | Ribbon J5.16 | UUT set to 1, TB reads1 UUT set to 0, TB read 0 | | UUT issue
9 | Ribbon J5.17 | UUT set to 1, TB reads1 UUT set to 0, TB read 0 | | UUT issue
10 | Ribbon J5.18 | UUT set to 1, TB reads1 UUT set to 0, TB read 0 | | UUT issue
11 | Ribbon J5.19 | UUT set to 1, TB reads1 UUT set to 0, TB read 0 | | UUT issue
12 | Ribbon J5.3 | UUT set to 1, TB reads1 UUT set to 0, TB read 0 | I2C slave test. UUT slave I2C GPIO CL line is toggled between 0 and 1 | UUT issue
13 | Ribbon J5.6 | UUT set to 1, TB reads1 UUT set to 0, TB read 0 | I2C slave test. UUT slave I2C GPIO DA line is toggled between 0 and 1 | UUT issue
14 | Ribbon J5.3 | UUT set to 1, TB reads1 UUT set to 0, TB read 0 | I2C master test. UUT slave I2C GPIO CL line is toggled between 0 and 1 | UUT issue
15 | Ribbon J5.6 | UUT set to 1, TB reads1 UUT set to 0, TB read 0 | I2C master test. UUT slave I2C GPIO DA line is toggled between 0 and 1 | UUT issue
15 | Ribbon J5.5 | Value = +6V +- 5% | | UUT issue
16 | Ribbon J5.7 | Value = +6V +- 5% | | UUT issue
17 | Ribbon J5.8 | Value = +6V +- 5% | | UUT issue
18 | Ribbon J5.13 | Value = +12V +- 5% | | UUT issue
19 | Ribbon J5.14 | Value = +12V +- 5% | | UUT issue
20 | Ribbon J5.23 | Value = +0V +- 5% | | UUT issue
21 | Ribbon J5.25 | Value = +0V +- 5% | | UUT issue
22 | Ribbon J5.20 | Value = +0V +- 5% | | UUT issue
23 | Ribbon J5.22 | Value = +0V +- 5% | | UUT issue
24 | Ribbon J5.24 | Value = +0V +- 5% | | UUT issue
25 | Ribbon J5.26 | Value = +0V +- 5% | | UUT issue
27 | Ribbon RS-422 | Echo test on itself | | UUT issue
28 | Status Red Led | Value 1.6V:2.2V | M1-3200 is set to activate Red Led | UUT issue
29 | Status Blue Led | Value -2.6V: -3.3V | M1-3200 is set to activate Blue Led | UUT issue
30 | Tamper | Value 0 or 1 | TB toggles line 0 and 1, M1-3200 shall detect the proper value
31 | DDR data bus test | No data compare mismatch | | UUT issue
32 | DDR address bus test | No data compare mismatch | | UUT issue
33 | DDR data | No data compare mismatch | | UUT issue
34 | I2C EEPROM | EEPROM is detected and data can read/write | This tests EEPROM and I2C connected to EEPROM | UUT issue
35 | Test UUT can run from battery power only | Battery power is on, Main 12V power off, the UUT CPU no reset | | UUT issue
36 | Test battery charger | The charging voltage > 13V | Apply 100R load to the battery. | Charging module issue

## 1.2 Programming MAC

UUT is set to DFU mode. U-Boot from S2 released firmware is downloaded with ST Cube Programmer. MAC address is programmed into STM32MP1.

This step can fail if:

1. The Saline serial number with this UUT CPU serial number is already in the database. This means that the user did not scan Saline barcode.
2. USB cable issue with DFU USB link

## 1.3 Programming SSD

UUT is set to DFU mode. The UUT is programmed with the flash layout file released by S2’ by ST Cube Programmer.

Sometimes ST Cube Programmer fails. Restart the test.

Check USB DFU cable.

## 1.4 Functional Test

UUT started from SSD.

If /home/s2user/testpassed flag is set it is cleared and UUT is rebooted. If all tests pass the /home/s2user/testpassed file is created.

Common issues:

  - PS issue.
  - M1-3200 USB link to PC, cable?
  - Ethernet Cable connection to PC.
  - Teensy 4.1 USB link issue.

Table 5 Function Test Vectors

# | Description | Acceptance Criteria | Troubleshooting

1 | MAC address verification | Make sure ifconfig report expected MAC address | Not expected to fail
2 | WD Test | Activate WD, wait for reboot, login to UUT | Not expected to fail
3 | SPI Ram Test | Write random data to SPI Ram, Reboot, compare data is the same after reboot | SPI Flash issue
4 | RTC Test | Set RTC, Set Linux date. make sure values are different. Power is off. Boot UUT. Make sure Linux date is expected value. | UUT issue, RTC Backup battery connection issue.
5 | USB Pen Drive | The drive is mounted and can read and write. | UUT connector issue, USB Pen drive issue HW issue, USB Pen drive incorrect format.
6 | Ribbon I2C test | Master I2C can scan slave I2c | UUY issue

## 1.5 Apps Check

EEPROM is programmed before this test. UUT started from SSD.

Test runner CLI will login into UUT and application status is checked with netstat.

# 13. Test Fixture User’s CLI utility

The CLI utility M1CloudClient automates log and secrets retrieval from the cloud and allows engineering to upload the Cloud test fixture and M1-3200 firmware updates. The link to the utility -> M1-3200 CLI Utility (https://carcgl.sharepoint.com/:f:/r/sites/SAMSAM-EHWDesign/Shared%20Documents/General/M1-3200%20CLI%20Utility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)

The user shall specify vendorSite or requires test fixture ID as a parameter to the command line utility.

The vendorSite can be found in the test fixture configuration file.

#m1CloudClient –help

Usage: m1cli [options] [command]

CLI utility retrieve M1-3200 manufacturing logs

Options:

-V, --version output the version number

-h, --help display help for command

Commands:

downloadfwsw [options] download software and firmware to the test fixture

getsecrets <timeStamp> get the secrets file from the Cloud

getlog <logId> get the log from the Cloud

listsecrets <date ref> list secrets avaialble in the Cloud

listlogs <date ref> list logs avaialble in the Cloud

help [command] display help for command

To get help for the specific command

#m1CloudClient-linux getsecrets --help

Usage: m1cli getsecrets [options] <timeStamp>

get the secrets file from the Cloud

Arguments:

timeStamp date prefix, the date format is 2023_02_11_16 and used as prefix, so if date = 2023 then all files from 2023 are returned,

if date = 2023_02_11_16 only for this date files are ruturned

Options:

-h, --help display help for command

#m1CloudClient-linux getsecrets --help

Usage: m1cli getsecrets [options] <timeStamp>

get the secrets file from the Cloud

Arguments:

timeStamp date prefix, the date format is 2023_02_11_16 and used as prefix, so if date = 2023 then all files from 2023 are returned,

if date = 2023_02_11_16 only for this date files are ruturned

Options:

-h, --help display help for command

#m1CloudClient-linux getlog --help

Usage: m1cli getlog [options] <logId>

get the log from the Cloud

Arguments:

logId log file name or uid or serial number from the barcode

Options:

-h, --help display help for command

#m1CloudClient-linux listsecrets --help

Usage: m1cli listsecrets [options] <date ref>

list secrets avaialble in the Cloud

Arguments:

date ref date prefix, the date format is 2023_02_11_16 and used as prefix, so if date = 2023 then all file for 2023 are returned, if

date = 2023_02_11_16 only for this date files are ruturned

Options:

-h, --help display help for command

#m1CloudClient-linux listlogs --help

Usage: m1cli listlogs [options] <date ref>

list logs avaialble in the Cloud

Arguments:

date ref date prefix, the date format is 2023_02_11_16 and used as prefix, so if date = 2023 then all file for 2023 are returned, if

date = 2023_02_11_16 only for this date files are ruturned

Options:

-h, --help display help for command

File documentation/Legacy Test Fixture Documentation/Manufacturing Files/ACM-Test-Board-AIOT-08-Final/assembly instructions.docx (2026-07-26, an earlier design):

# Assembly Instructions

1. Pug the meting parts of lines items in BOM 17-19. These are the pluggable terminal blocks.
a. Teensy 4.1 Ethernet header 2x3 2mm female socket (BOM item 30) shell be soldered on the bottom side of Teensy 4.1, next to Pins 20 & 21.
b. The BOM line item 32, the mating part for BOM item 30 shell be plugged into BOM item 30.
c. The assembly shell be plugged into the PCB. The Teensy 4.1 USB receptacle (on the picture below on the left), shell be positioned at the edge of the board.

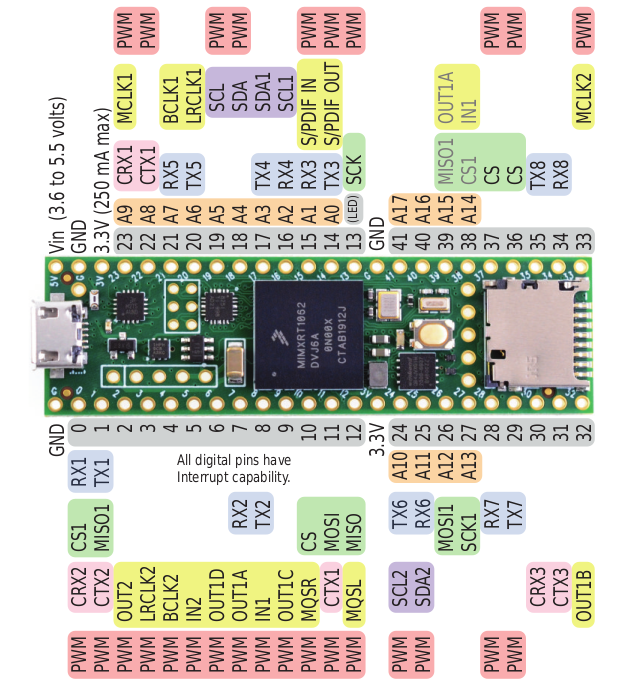
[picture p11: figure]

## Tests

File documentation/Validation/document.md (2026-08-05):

# React Commission Test Plan

## 1. Scope

This plan covers the end-to-end `COMMISSION` flow started from the React operator UI and executed through:

- `m1-operator-ui` -> `m1-rest-server` -> `m1tfc`
- Fixture firmware paths (`m1testBoardFw`, `acm-testboard-fw` where applicable)
- UUT interfaces used by each command

This document is intentionally code-grounded. Firmware runtime `help` remains the authoritative command/protocol reference.

## 2. Commission Entry Point (React)

`COMMISSION` button triggers `runSequence('commission')`.

Sequence order:

1. `ict`
2. `progmac`
3. `flash`
4. `functest`
5. `eeprom`
6. `pingM1apps`
7. `makelabel`

Behavior notes:

- UI serial must match `^\d{10}$`.
- In production mode, rerun of the same serial is blocked after a full pass.
- Commands are streamed through `POST /command/stream` and considered pass/fail by final `payload.result.status`.
- On first failed step (except `PRINT LABEL`), UI attempts `makelabel --error`.
- `cleanup` is invoked at sequence end on success, and also on failure except precheck hardware failure (error code `15`).

## 3. Preconditions

1. React UI reachable and unlocked for run mode.
2. REST service healthy (`GET /health` = `status: OK`).
3. `m1tfc` command queue available (no stuck command).
4. Required devices present for ICT precheck (unless debug level 2):
- `/dev/ttyACM0` (test board)
- `/dev/ttyUSB0` (UUT terminal converter)
5. Network prerequisites for ICT precheck:
- `tfInterface` exists (default `eth1`)
- Interface at `192.168.0.100` present (UUT ethernet check)
6. If label printing enabled, printer detect path must pass (`lsusb | grep QL-810W`).

## 4. Command-Level Acceptance Criteria

## 4.1 ICT (`ict`)

Commission invocation from UI adds:

- `--cellBatTol used` when running in Debug mode (`isDebug`), otherwise `new` in production commission mode
- `--debug <level>` and `--serial <10-digit>`

Pass criteria:

1. ICT command returns normal exit.
2. Log contains `ICT Test Passed!!!`.
3. DB ICT status is updated to pass.

Fail criteria:

1. Any subtest failure sets command failure (`ictTestFailed`).
2. Log contains `One or more tests Failed!!!` or explicit exception.

ICT coverage includes (depending on product/config):

- Lever lock check
- Voltage/test-point checks
- DDR voltage and DDR3 test
- Ribbon cable tests
- RS-485 tests (plus MNP reader RS-485 on MNPlus)
- Status LED and tamper tests
- EEPROM checks
- Coin-cell battery threshold check (`new` or `used` profile)
- MNPlus-specific functional set and PoE switch-over check

## 4.2 Program MAC (`progmac`)

Pass criteria:

1. `run()` completes without error.
2. `runProgSecret()` completes without error.
3. Command exits normal.
4. Accepted production case: OTP and/or secret key already programmed (informational, not a failure).

Fail criteria:

- Any exception or non-normal exit.

## 4.3 Flash (`flash`)

Pass criteria:

1. If `progEmmc` enabled: flash routine completes and exits normal.
2. Cleanup power-down path completes (`testEndSuccess`).

Fail criteria:

- Flash routine non-zero exit code.

## 4.4 Functional Test (`functest`)

Observed functional subtests executed by `FuncTest.run()`:

1. OTP MAC presence check:
- Reads MAC from OTP and fails if empty/zero (`00:00:00:00:00:00`).
2. UUT boot and login path:
- Powers target, waits for login prompt, logs in, initializes test mode.
3. Network/SSH access:
- Connects to target over SSH using runtime IP.
4. MAC consistency check:
- Verifies `ip link show eth0` MAC matches OTP MAC.
5. I2C bus connectivity:
- On MNPlus (`activeBus=0`): checks I2C bus 0 pattern.
- On M1 (`activeBus=1`): checks I2C bus 1 pattern, plus additional bus 0/2 pattern check.
6. Watchdog reboot test:
- Arms watchdog, expects reboot, reconnects after reboot.
7. SPI RAM retention test:
- Writes random block to SPI RAM mirror, reboots, verifies persisted content by `diff`.
8. USB host pen-drive mount test:
- Verifies `/dev/sda` mount presence (unless `skipUSBPenDriveTest` is enabled).
9. RTC synchronization and persistence:
- Sets system/hwclock from PC time, power-cycles, then verifies RTC delta is within 5 seconds.
10. Functional completion flag:
- Creates `/home/s2user/testpassed` and updates DB functional-test status.

Pass criteria:

1. Command exits normal (`exitCodes.normalExit`).
2. Log contains `Functional test passed`.
3. `common.testEndSuccess()` path executes.

Fail criteria:

1. Any exception in subtests.
2. Non-normal exit (`exitCodes.functTestFailed` or command failure path).
3. Error-to-code mapping is recorded for known failure modes (RTC, WDT, USB pen drive, MAC compare, terminal/ether/SSH reconnect, DFU, OTP MAC missing).

## 4.5 EEPROM (`eeprom`)

Pass criteria:

1. `vendorSite` is configured.
2. EEPROM programming flow completes without error.
3. Cleanup power-down path completes (`testEndSuccess`).
4. Accepted production case: EEPROM not blank warning is acceptable when verify phase reports valid EEPROM data.

Fail criteria:

- Missing `vendorSite`, programming failure, or non-normal exit.

## 4.6 App Port Check (`pingM1apps`)

Pass criteria:

1. Boot mode is set to runtime and power cycle completes.
2. TCP port 80 on `m1defaultIP` opens within retry window.
3. Command exits normal.

Retry window:

- 30 retries
- 5 seconds delay between retries
- Approximate timeout: 150 seconds

Fail criteria:

- Port 80 does not open within window.

## 4.7 Label Print (`makelabel`)

Pass criteria (normal path):

1. MAC read from OTP is valid and non-zero.
2. EEPROM serial matches run serial.
3. Label print call succeeds.

Pass criteria (error path):

- `--error` label prints with DB error code context.

Fail criteria:

- MAC read invalid, EEPROM mismatch, printer failure, or command failure.

## 5. Tolerances and Thresholds (Code Defaults)

These are default values from `m1tfc` command/runtime config and regulator logic.

1. General voltage tolerance: `0.05` (5%), unless per-test-point override is present.
2. Lever lock voltage tolerance: absolute `0.2` around expected level.
3. Coin-cell minimum voltage:
- `new`: `3.0 V`
- `used`: `2.9 V`
4. Commission `cellBatTol` is mode-dependent in React:
- Debug mode commission: `used`
- Production-mode commission: `new`

Important:

- Per-point tolerance can override the global 5% tolerance in calibration data.
- Runtime config can override defaults (`coinCellMinVoltageNew`, `coinCellMinVoltageUsed`, `tolerance`, etc.).

## 5.1 Test Points Specification

Authoritative source in code/runtime:

- `components/m1tfc/tests/calibrationDefault.js` (default test-point definitions)
- `/etc/m1platform/calibration.json` (board-specific overrides)
- `components/m1tfc/tests/regulators.js` and `components/m1tfc/utils/voltageHelper.js` (pass/fail evaluation)

Default M1 test points (`testPointsM1`):

- `TP025` expected `5.0 V`
- `TP33` expected `2.8 V`
- `TP35` expected `3.3 V`
- `TP34` expected `3.3 V`
- `TP36` expected `1.2 V`
- `J5.13` expected `11.7 V`
- `J5.5` expected `6.0 V`
- `J5.7` expected `6.0 V`
- `J5.8` expected `6.0 V`

Default MNPlus test points (`testPointsMnp`):

- `TP204` expected `5.0 V`
- `TP308` expected `2.8 V`
- `TP303` expected `1.2 V`
- `TP305` expected `3.3 V`
- `TP306` expected `3.3 V`
- `TP401` expected `5.0 V`
- `TP2301` expected `12.8 V`
- `TP202` expected `12.0 V`
- `J2101.1` expected `11.85 V`
- `J2001.1` expected `11.85 V`

Additional calibrated groups used by ICT:

- DDR voltage point:
	- M1: `TP31` expected `1.35 V`
	- MNPlus: `TP304` expected `1.35 V`
- Strike regulator points (MNPlus path):
	- `SW1601.6` expected `28.0 V`
	- `SW1602.6` expected `28.0 V`
- Ribbon A/D reference points:
	- `TP1801`, `TP1802`, `TP1901`, `TP1902` expected `2.7 V`

Acceptance rule for each voltage test point:

1. Read raw value from test board firmware (`getiopin`).
2. Apply point scale.
3. Compute error as `abs(measured_scaled - expected) / expected`.
4. Compare to tolerance:
- Use point-specific tolerance when defined in calibration data.
- Otherwise use global runtime tolerance (default `0.05`).
5. Pass when error is less than or equal to tolerance.
6. Fail when error exceeds tolerance; error code is recorded and ICT fails.

Calibration behavior:

- In calibration mode, failing points do not auto-pass; operator must adjust/calibrate and rerun.
- Updated scale/threshold data is persisted to `/etc/m1platform/calibration.json` for that board ID.

## 6. End-to-End Commission Acceptance

A board is accepted as `COMMISSION PASS` only if all of the following are true:

1. All seven commands in sequence return pass.
2. No step is stopped or aborted.
3. Final UI result is pass.
4. `cleanup` runs after sequence success.
5. In production mode, serial is latched as passed (prevents immediate duplicate rerun).

A board is `COMMISSION FAIL` if any step fails or is stopped.

## 6.1 Log-Matched Baseline (2026-07-25 Reference Run)

The supplied run log is consistent with this plan and is treated as a known-good baseline for MNPlus commission behavior:

1. Commission started with stream command equivalent to:
`sudo -n m1tfc ict --serial <serial> --debug 1 --cellBatTol used`
2. `ict` passed with `ICT Test Passed!!!` after the following observed checks:
`TP204`, `TP308`, `TP303`, `TP305`, `TP306`, `TP401`, `TP2301`, `TP202`, `J2101.1`, `J2001.1` test-point checks
coin-cell check using `used` battery profile
strike regulator checks (`SW1601.6`, `SW1602.6`)
DDR voltage check (`TP304`)
ribbon A/D checks (`TP1801`, `TP1802`, `TP1901`, `TP1902`)
RS485 checks (including reader RS485 on MNPlus)
status LED and tamper checks
DDR3 check
EEPROM check
PoE switch-over check
3. `progmac` completed as pass while logging already-programmed conditions (`OTP is not blank` and/or secret key already programmed), treated as accepted production state.
4. `flash` completed with `Target flashing is done`.
5. `functest` completed with `Functional test passed`.
6. `eeprom` logged `EEPROM not Blank` and still passed with `The EEPROM Data is valid`; this is an accepted state.
7. `pingM1apps` passed with runtime app reachability on port `80`.
8. `makelabel` executed in normal path.
9. `cleanup --serial <serial>` executed at run end.

## 7. Suggested Execution Record

For each run, record:

1. Serial number
2. Product (`m1-3200` or `mnplus`)
3. Debug level used
4. Effective tolerance values (`tolerance`, coin-cell thresholds)
5. Step reached at failure (if any)
6. Error code(s) printed/logged
7. Whether error label printed successfully
8. Operator, date/time, fixture ID

## 8. Code Trace Points

Primary implementation files:

- `components/m1-operator-ui/src/App.jsx`
- `components/m1-operator-ui/src/constants.js`
- `components/m1-rest-server/src/server.js`
- `components/m1-rest-server/src/commandRunner.js`
- `components/m1tfc/bin/commands/ict.js`
- `components/m1tfc/tests/ictTestRunner.js`
- `components/m1tfc/tests/regulators.js`
- `components/m1tfc/bin/commandSupport.js`
- `components/m1tfc/bin/commands/flash.js`
- `components/m1tfc/bin/commands/progmac.js`
- `components/m1tfc/bin/commands/functest.js`
- `components/m1tfc/bin/commands/eeprom.js`
- `components/m1tfc/bin/commands/pingM1apps.js`
- `components/m1tfc/bin/commands/makelabel.js`

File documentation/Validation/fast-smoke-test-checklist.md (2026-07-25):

# Fast Smoke Test Checklist

Use this checklist after snap install or before release tagging.

## Preconditions

- Fixture host booted and snaps installed.
- Test board connected on expected USB/serial path.
- No stale serial monitor holding `/dev/ttyACM0`.

Quick lock check:

```bash
lsof /dev/ttyACM0
```

If locked by a monitor process, stop it before continuing.

## 1) REST Command Routing Smoke

Goal: verify REST routes commands to `m1tfc`.

```bash
curl -sS -X POST http://127.0.0.1:3300/command \
  -H 'Content-Type: application/json' \
  -d '{"command":"power","argument":"--state off"}'
```

Expected:

- JSON response with `"status":"OK"`.
- No `Unsupported command` error.

## 2) Board Identity Smoke

Goal: verify board ID path from firmware through REST config.

```bash
curl -sS http://127.0.0.1:3300/config | jq '.boardId, .fwVersion, .machineName'
```

Expected:

- `boardId` is populated (not `unknown`) when serial port is free.

## 3) UI Serial Workflow Smoke

Goal: verify operator serial guard behavior.

1. Enter valid 10-digit serial in UI.
2. Start `COMMISSION` or `RE-TEST`.
3. Confirm serial input is invalidated/locked while sequence uses captured serial.
4. Double-click serial field.
5. Confirm last invalidated serial value is restored.

Expected:

- Serial field locks after run start.
- Double-click restores previous serial value.

## 4) Calibration Argument Smoke

Goal: verify battery voltage prompt propagates into calibration runtime.

1. In debug mode, click `CALIBRATE`.
2. Enter measured battery voltage (for example `3.05`).
3. Observe command/log stream.

Expected:

- ICT calibration run starts.
- Runtime uses provided `--batteryVoltage` value.
- On success path, log/result indicates calibration completion.

## 5) Run Completion Message Smoke

Goal: verify success wording split.

Expected:

- Calibration success message: `Calibration Complete!!!`.
- Non-calibration ICT success message: `ICT Test Passed!!!`.

## 6) Basic Failure Path Smoke

Goal: verify failure surfacing is operator-visible.

1. Trigger a known safe failure condition (for example disconnected fixture signal for one step).
2. Run sequence.

Expected:

- UI shows failed status and step context.
- Failure summary lines appear in debug mode.

## Pass/Fail Gate

Pass only if all checks succeed without manual code edits between checks.

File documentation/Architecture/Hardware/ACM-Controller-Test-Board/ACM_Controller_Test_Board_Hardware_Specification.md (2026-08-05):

**ACM Controller Test Board Hardware Specification**

*Reusable ACM ecosystem simulation and validation subsystem*

Version 1.0 \| July 25, 2026\
Owner: Leo Buchman\
Status: Initial controlled draft

  -------------------------------------------------------------------------------------------
  Document Type                       Board Hardware Specification
  ----------------------------------- -------------------------------------------------------
  Platform                            M1/MNPlus EVM

  Scope                               Hardware / architecture

  Source Baseline                     Schematics, platform diagram, physical configurations
  -------------------------------------------------------------------------------------------

# 1. Purpose

The ACM Controller Test Board provides reusable simulation and validation for ACM controllers, door controllers, I/O boards, and the ACM scope used by MNPlus. The board was developed to support automated end-to-end Elements validation.

# 2. Board Image

\[Insert controlled 2D CAD board view here\]

# 3. Functional Summary

- Teensy 4.1 controller

- Ethernet connectivity

- FTDI/USB serial logging and service access

- Two reader simulation channels

- Dual OSDP simulation

- Dual Wiegand simulation

- Reader power, LED, and buzzer interaction

- 8 supervised channels

- Relay/output activation validation

- Cabinet-tamper simulation

- Power-fault simulation

- Controller power control

- Downstream control

# 4. Reader Simulation

  ----------------------------------------------------------------------------------------
  **Channel**             **Protocols**           **Signals / functions**
  ----------------------- ----------------------- ----------------------------------------
  Reader 1                OSDP and Wiegand        RS-485, data/clock, LED, buzzer, power

  Reader 2                OSDP and Wiegand        RS-485, data/clock, LED, buzzer, power
  ----------------------------------------------------------------------------------------

# 5. Supervised Inputs

8 analog supervised channels (SI1-SI8) are implemented. The controlled validation specification must list the exact resistance/state combinations recognized by firmware and the expected controller interpretation.

# 6. Relay and Output Validation

The schematic exposes Relay1 through Relay10 paths for validating controller output activation and related cabinet/power behavior. Product-specific harnesses determine which channels are used in a given deployment.

# 7. Supported Product Coverage

- ACM controller families

- ACM door controllers

- ACM I/O expansion boards

- MNPlus ACM scope

- Elements end-to-end use cases

# 8. Current MNPlus Subset

The current MNPlus fixture uses the subset required for ACM/MNPlus validation. Full ACM capability can be exposed through a different plate, expanded pogo-pin mapping, and additional wiring. Core board redesign is not required.

# 9. Sustainment Data Required

- Native schematic and PCB source

- BOM and approved alternates

- Gerber and pick-and-place package

- Firmware source and reproducible build environment

- Reader, supervised-channel, and relay ICDs

- Golden-board acceptance test

- Critical-component lifecycle list

# 10. Source Schematic

See Source-Schematics/ACM_Controller_Test_Board_Schematic.pdf in this package.

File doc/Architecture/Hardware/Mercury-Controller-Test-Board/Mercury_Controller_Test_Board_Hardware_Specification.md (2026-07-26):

**Mercury Controller Test Board Hardware Specification**

*Reusable Mercury ecosystem simulation and validation subsystem*

Version 1.0 \| July 25, 2026\
Owner: Leo Buchman\
Status: Initial controlled draft

  -------------------------------------------------------------------------------------------
  Document Type                       Board Hardware Specification
  ----------------------------------- -------------------------------------------------------
  Platform                            M1/MNPlus EVM

  Scope                               Hardware / architecture

  Source Baseline                     Schematics, platform diagram, physical configurations
  -------------------------------------------------------------------------------------------

# 1. Purpose

The Mercury Controller Test Board provides reusable simulation and validation for Mercury controllers, door controllers, I/O boards, and the ACM scope used by MNPlus. The board was developed to support automated end-to-end Elements validation.

# 2. Board Image

\[Insert controlled 2D CAD board view here\]

# 3. Functional Summary

- Teensy 4.1 controller

- Ethernet connectivity

- FTDI/USB serial logging and service access

- Two reader simulation channels

- Dual OSDP simulation

- Dual Wiegand simulation

- Reader power, LED, and buzzer interaction

- 8 supervised channels

- Relay/output activation validation

- Cabinet-tamper simulation

- Power-fault simulation

- Controller power control

- Downstream control

# 4. Reader Simulation

  ----------------------------------------------------------------------------------------
  **Channel**             **Protocols**           **Signals / functions**
  ----------------------- ----------------------- ----------------------------------------
  Reader 1                OSDP and Wiegand        RS-485, data/clock, LED, buzzer, power

  Reader 2                OSDP and Wiegand        RS-485, data/clock, LED, buzzer, power
  ----------------------------------------------------------------------------------------

# 5. Supervised Inputs

8 analog supervised channels (SI1-SI8) are implemented. The controlled validation specification must list the exact resistance/state combinations recognized by firmware and the expected controller interpretation.

# 6. Relay and Output Validation

The schematic exposes Relay1 through Relay10 paths for validating controller output activation and related cabinet/power behavior. Product-specific harnesses determine which channels are used in a given deployment.

# 7. Supported Product Coverage

- Mercury controller families

- Mercury door controllers

- Mercury I/O expansion boards

- MNPlus ACM scope

- Elements end-to-end use cases

# 8. Current MNPlus Subset

The current MNPlus fixture uses the subset required for ACM/MNPlus validation. Full Mercury capability can be exposed through a different plate, expanded pogo-pin mapping, and additional wiring. Core board redesign is not required.

# 9. Sustainment Data Required

- Native schematic and PCB source

- BOM and approved alternates

- Gerber and pick-and-place package

- Firmware source and reproducible build environment

- Reader, supervised-channel, and relay ICDs

- Golden-board acceptance test

- Critical-component lifecycle list

# 10. Source Schematic

See Source-Schematics/Mercury_Controller_Test_Board_Schematic.pdf in this package.

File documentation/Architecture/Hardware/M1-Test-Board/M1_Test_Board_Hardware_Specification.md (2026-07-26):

**M1 Test Board Hardware Specification**

*M1-scope control and validation subsystem*

Version 1.0 \| July 25, 2026\
Owner: Leo Buchman\
Status: Initial controlled draft

  -------------------------------------------------------------------------------------------
  Document Type                       Board Hardware Specification
  ----------------------------------- -------------------------------------------------------
  Platform                            M1/MNPlus EVM

  Scope                               Hardware / architecture

  Source Baseline                     Schematics, platform diagram, physical configurations
  -------------------------------------------------------------------------------------------

# 1. Purpose

The M1 Test Board provides M1-specific control, measurement, programming, recovery, and product-interface functions for both M1 and the M1 scope of MNPlus.

# 2. Board Image

\[Insert controlled 2D CAD board view here\]

# 3. Functional Summary

- Teensy 4.1 control processor

- Target power on/off control

- Boot-target selection

- Serial/UART and RS-485 communication

- Firmware programming and product recovery

- Battery-control and measurement functions

- Analog multiplexing and measurement

- Tamper and control-signal access

- IDC/ribbon interface

- Production fixture interface through wiring and pogo pins

# 4. Interface Summary

  ----------------------------------------------------------------------------------------------------------------
  **Interface**           **Purpose**                                  **Configuration**
  ----------------------- -------------------------------------------- -------------------------------------------
  IDC / ribbon            Direct product and test-board connectivity   Engineering and controlled fixture wiring

  USB serial              Controller command, debug, and automation    Engineering / QA / production

  RS-485                  Product or test communication                As required by M1 scope

  Power control           Target 12 V and related rails                All deployments

  Pogo-pin mapping        Product-specific electrical access           Production fixture
  ----------------------------------------------------------------------------------------------------------------

# 5. Engineering and Production Use

Engineering may connect directly through the IDC interface and terminal blocks. Production uses a product-specific fixture plate and pogo-pin mapping. The difference is implementation and workflow, not a different board architecture.

# 6. Verification Requirements

- Verify all supply rails before target connection

- Verify boot-target control

- Verify target power switching

- Verify serial and RS-485 paths

- Verify analog measurement channels

- Verify IDC pinout against the controlled ICD

- Verify production pogo-pin map and contact continuity

# 7. Sustainment Data Required

- Native schematic and PCB source

- BOM and approved alternates

- Gerber and pick-and-place package

- Controller firmware source and build environment

- IDC and pogo-pin ICDs

- Golden-board acceptance test

- Critical-component lifecycle list

# 8. Source Schematic

See Source-Schematics/M1_Test_Board_Schematic.pdf in this package.

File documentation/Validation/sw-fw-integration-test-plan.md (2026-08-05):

# SW/FW Integration Test Plan

## 1. Purpose

This document defines the integration test plan for the M1 fixture software and firmware stack:

- PC layer: m1-operator-ui, m1-rest-server, m1tfc
- Fixture firmware: m1testBoardFw, acm-testboard-fw
- UUT firmware/runtime path: stm32mp1-baremetal over serial and USB/DFU flow

The goal is to validate command routing, link ownership, protocol consistency, boot-mode control behavior, and operator-visible results.

## 2. Scope

In scope:

- End-to-end command flow from UI to hardware-facing links.
- JSON command/response behavior on all three firmware targets.
- Link separation and ownership by m1tfc.
- UUT mode selection flow and DFU programming path.
- Access-control path exercise through acm-testboard-fw.
- Error handling and operator feedback.

Out of scope:

- Cloud/update paths (tfcroncli).
- Long-term reliability/aging tests.
- EMI/EMC and environmental qualification.

## 3. References

- doc/Architecture/Software/sw-fw-dataflow-diagram.md
- doc/Validation/fast-smoke-test-checklist.md

## 4. Test Environment

Host:

- PC Ubuntu 26.04 server
- Required services installed and running: m1-rest-server, m1tfc, operator UI stack

Hardware:

- M1 Test Board running m1testBoardFw
- ACM Test Board running acm-testboard-fw
- UUT with stm32mp1-baremetal and USB connection

Connectivity:

- Serial link A: m1tfc <-> m1testBoardFw
- Serial link B: m1tfc <-> UUT serial header (independent of link A)
- UDP link: m1tfc <-> acm-testboard-fw
- USB link: PC <-> UUT (DFU/SSD workflow)

Tooling:

- curl
- jq
- serial terminal/log capture utility
- packet capture for UDP verification (optional but recommended)

## 5. Entry and Exit Criteria

Entry criteria:

- Firmware versions loaded and recorded.
- Cabling and power verified.
- No process holds required serial ports.
- m1-rest-server health endpoint reachable.

Exit criteria:

- All P0 and P1 test cases pass.
- No unresolved critical defects.
- Failed/blocked cases documented with reproducible evidence.

## 6. Test Data

- At least one known-good UUT
- At least one known-fault-injection condition (safe, reversible)
- Operator serial numbers for commission/re-test flows
- Expected command/response samples for each target firmware

## 7. Test Cases

Priority legend:

- P0: release blocker
- P1: high priority
- P2: medium priority

### 7.1 Control-Plane and Routing

TC-CP-001 (P0) UI to REST command path

- Objective: verify UI submits commands and REST accepts them.
- Steps:
  1. Trigger a safe command from UI.
  2. Confirm REST endpoint receives the request.
- Expected:
  - HTTP success response.
  - Request payload preserved (command + arguments).

TC-CP-002 (P0) REST to m1tfc dispatch

- Objective: verify REST does not execute hardware logic itself.
- Steps:
  1. Send command through REST API.
  2. Check logs for forward/dispatch event to m1tfc.
- Expected:
  - m1tfc receives command.
  - REST layer reports status only, no hardware-side execution path.

### 7.2 Link Ownership and Separation

TC-LINK-001 (P0) Dual serial independence

- Objective: verify m1tfc owns two independent serial links.
- Steps:
  1. Open m1testBoardFw command session through m1tfc.
  2. In parallel, execute a UUT serial command through m1tfc.
- Expected:
  - Both links operate without cross-talk.
  - UUT serial path does not depend on M1 board passthrough.

TC-LINK-002 (P1) UDP channel availability

- Objective: verify m1tfc command path to acm-testboard-fw over UDP.
- Steps:
  1. Send a acm-testboard-fw-targeted command.
  2. Capture response and timing.
- Expected:
  - Response returns over UDP.
  - No fallback to serial for acm path.

### 7.3 Protocol Consistency

TC-PROTO-001 (P0) JSON response schema across all targets

- Objective: verify common command/response model.
- Steps:
  1. Send one valid command to each target firmware.
  2. Record responses.
- Expected:
  - Response is parseable JSON.
  - Includes status and error fields.
  - Optional data field present when applicable.

TC-PROTO-002 (P1) Invalid command behavior

- Objective: verify invalid command handling is deterministic.
- Steps:
  1. Send malformed/unknown command to each target.
- Expected:
  - Failure status returned.
  - Error message present and readable.
  - No crash or stuck link.

### 7.4 UUT Mode and Programming Flow

TC-BOOT-001 (P0) Boot-select GPIO control

- Objective: verify one GPIO control pin sets intended boot mode.
- Steps:
  1. Select normal boot mode.
  2. Select DFU mode.
  3. Select download-and-execute mode for stm32mp1-baremetal flow.
- Expected:
  - Hardware state transitions match selected mode.
  - Transitions are logged.

TC-BOOT-002 (P1) GPIO/A-D test-point measurement path

- Objective: verify GPIO/A-D channels are used for testing, not for download transport.
- Steps:
  1. Run test-point measurement routine.
  2. Run DFU download workflow.
- Expected:
  - Test-point reads return via test routines.
  - DFU transport occurs on USB path; no dependency on GPIO/A-D transport.

TC-DFU-001 (P0) USB/DFU programming path

- Objective: verify UUT programming over USB/DFU path.
- Steps:
  1. Set DFU mode.
  2. Perform DFU programming run.
- Expected:
  - Programming completes.
  - Post-program status indicates success.

### 7.5 Access-Control Path

TC-ACM-001 (P1) ACM access I/O exercise

- Objective: verify access-control hardware exercise path.
- Steps:
  1. Execute acm test routine targeting access-control I/O.
- Expected:
  - Command reaches acm-testboard-fw over UDP.
  - Expected access-control activity/telemetry observed.

### 7.6 Operator Experience and Results

TC-UI-001 (P1) Run-state guard behavior

- Objective: verify serial/operator input guard behavior during execution.
- Steps:
  1. Start a run from UI.
  2. Attempt to edit serial fields during active run.
- Expected:
  - UI enforces run-state lock behavior as designed.

TC-UI-002 (P1) Success/failure messaging

- Objective: verify clear completion and failure signaling.
- Steps:
  1. Run one successful test sequence.
  2. Trigger one safe controlled failure.
- Expected:
  - Success and failure states are clearly distinguishable.
  - Failure output includes actionable context.

## 8. Negative and Recovery Tests

TC-NEG-001 (P0) Serial port unavailable

- Expected:
  - System reports port busy/unavailable clearly.
  - No deadlock; retry path is available.

TC-NEG-002 (P1) UDP timeout/retry

- Expected:
  - Retry or timeout behavior follows design.
  - Error surfaced to operator/logs.

TC-REC-001 (P1) Recover after transient link loss

- Expected:
  - Operator can recover without process restart when possible.
  - Recovery procedure documented in logs.

## 9. Traceability Matrix (Minimum)

- Requirement: UI command routing -> TC-CP-001, TC-CP-002
- Requirement: m1tfc sole link owner -> TC-LINK-001, TC-LINK-002
- Requirement: common JSON protocol -> TC-PROTO-001, TC-PROTO-002
- Requirement: boot-mode control by GPIO pin -> TC-BOOT-001
- Requirement: GPIO/A-D used for testing -> TC-BOOT-002
- Requirement: USB/DFU programming path -> TC-DFU-001
- Requirement: acm access-control over UDP -> TC-ACM-001

## 10. Reporting

For each test case record:

- Test ID
- Build/firmware versions
- Date/time
- Pass/Fail/Blocked
- Evidence (logs, command output, captures)
- Defect ID (if failed)

## 11. Sign-off

Approval requires:

- QA/Test owner sign-off
- Firmware owner sign-off
- System/Fixture owner sign-off

Release recommendation: only after all P0 tests pass and no open critical defects remain.

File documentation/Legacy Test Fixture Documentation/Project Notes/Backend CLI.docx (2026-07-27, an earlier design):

Backend CLI

A command line utility to execute all M1-3200 Test Fixture tests.

Backend CLI executable is “m1tfd1.CLI”

The following commands are supported

lenel@m1testf4:~$ m1tfd1.cli --help

Usage: m1test [options] [command]

CLI utility to test and program M1-3200 boards

Options:

-V, --version output the version number

-h, --help display help for command

Commands:

m1dfu Start M1 in DFU mode and program bootstrap FW

tbcmd [options] execute test board raw command

m1cmd [options] execute M1 bootstrap raw command, make sure to run m1dfu command before

ict [options] Executes ICT test

eeprom [options] Program I2C EEPROM.

progmac [options] program MAC to MP1 OTP, cannot be undone

flash [options] program STM32M1 with the flash layout file

pingM1apps [options] try to establish connection to port 80

cleanup [options] pack the log and cleanup

functest [options] executes m1-3200 function test

makelabel [options] prints the M1-3200 Label

help [command] display help for the command

The Command [options] are required. To find out required options execute

lenel@m1testf4:~$ m1tfd1.cli –help Command

Example:

lenel@m1testf4:~$ m1tfd1.cli ict --help

Usage: m1test ict [options]

Executes ICT test

Options:

-s, --serial <string> vendor serial number

-d, --debug <level> set debug level, 0 error, 1 - info, 2 - debug

-b, --cellBatTol <cellBatTol> tolerance for coin cell bat, valid values: new, used

-h, --help display help for the command

Below is an example to execute ICT test

lenel@m1testf4:~$ m1tfd1.cli ict -s 1626262 -d1 -bnew

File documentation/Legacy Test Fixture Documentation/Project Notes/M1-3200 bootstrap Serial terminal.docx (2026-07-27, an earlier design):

# Why do we need to bootstrap M1-3200 for testing

M1-3200 board runs Linux operating system. The Linux operating system is programmed into the board when board passes basic voltage, GPO, and memory tests. To perform these tests a bootstrap firmware is required. The bootstrap FW is programmed into the CPU static RAM (not SDRAM). To program bootstrap firmware the board shall be placed into the RFU mode with bootstrap jumpers and then STM32 programming utility is used to program the bootstrap firmware into RAM over USB link and execute it.

The bootstrap firmware communication interface is serial. M1-3200 board has 0.1” 6 pin header for the serial terminal. Please use USB to 3.3V Serial converter to connect M1-3200 to the PC.

The M1-3200 can be controlled from the serial terminal in the bootstrap mode.

In order to get this functionality the M1-3200 board shall be connected to the PC over USB capable to do ST RFU and also Rs232 to 3.3V cable is required. Please use Tech TDI USB to TTL Serial 3.3V Adapter Cable 6 Pin 0.1 inch Pitch Female Socket Header UART IC FT232RL Chip Windows 11 10 8 7 Linux (6ft, Black)

Since test fixture already has proper connections for the terminal and bootstrap pins, I recommend to use test fixture PC if low level debug is required.

# Programming bootstrap firmware into M1-3200 board

The easiest way to program the bootstrap firmware is to use backend CLI utility. This utility is installed on the test fixture PC. Also the test fixture has all required connections to bootstrap pins, USB and the serial port.

Execute command below

$m1tfd1.cli m1dfu

Wait until command is done. On success M1-3200 LEDs will interlink like a police car light.

Please note that bootstrap firmware will run as long as power is applied to M1-3200 board. Make sure to manually cycle the power when you are done.

# Serial Terminal

Start the serial terminal

#picocom -b 115200 /dev/ttyUSB0

To exit picoohm press keys: Ctrl + A + X

Please note that Serial terminal will not “Echo” any typed character, therefore when you type there will be no characters in the terminal. This is done so the SW can use these commands in the script mode. Run the command below to enable Echo

promton

Followed by Enter. This will enable terminal Echo

Make sure to reset the board before executing Test Fixture SW because term mode is not compatible with the automated testing mode.

Now Execute command

LenelS2>help

This command will display all available commands.

ddrdatbus - Test the data bus wiring in a memory region by performing a walking 1's test at a fixed address within that region, arg: <offset from mem base hex> <memsize hex>

ddrtest - Test DDR integrity, arg: <offset from DDR base, in HEX> <size in HEX>

ddradrbus - Test the addr bus wiring by performing a walking 1's test on the bits of the address and checking for aliasing

pulsegpio - arg: <port> <pin> <width [uSec]>

confgpio - arg: <port> <pin> <mode [input or output]> <pull [up, down, none]>

getgpio - arg: <port> <pin>

setgpio - arg: <port> <pin> <value>

testrs422 - send char and receive reply

checkeeeprom - checkeeeprom arg: none

verifyeepromdata - check EEPROM data integrity

writeeepromdata - arg: <serialN> <secret> <force overwrite 1 or do not overwrite0>

testrs485 - test rs485 loopback test, needs rs485 slave to be connected in echo mode

getfwrev - return fw revision for ict test

promton - enable console promt

promtoff - disable console promt

help - display help

Most commands are self-explanatory.

To read/write GPO you need to know GPO port and pin values. Look at the M1-3200 schematic for.

Before GPO can be used the GPO needs to be configured for Input or Output.

Example: Read Ribbon Cable Pin 6 which is I2C clock pin.

1. Configure the ping as output

M1-3200: confusion an 11 output none

So, set port “a” pin “11” to be an output

2. Set the value to pin

setgpio an 11 1

Below are copy of FW defined pins. Not all pins are defined by a FW. For example AIDS? Pins are ribbon cable pins for the blades I2C address select. Also, there are pins for the ribbon cable I@C pins. If you need other CPU pins please look into the schematics.

Coast ribbonCableSelectPins = [

{ name: 'aioS0', port: 'd', pin: 5, pinNameOnTestBoard: 'J5.18' },

{ name: 'aioS1', port: 'c', pin: 6, pinNameOnTestBoard: 'J5.15' },

{ name: 'aioS2', port: 'd', pin: 4, pinNameOnTestBoard: 'J5.16' },

{ name: 'aioSel7', port: 'c', pin: 10, pinNameOnTestBoard: 'J5.19' },

{ name: 'amongst', port: 'k', pin: 0, pinNameOnTestBoard: 'J5.17' }

];

Coast ribbonCableI2CPinsSlave = [

{ name: 'SDA', port: 'a', pin: 12, pinNameOnTestBoard: 'J5.6' },

{ name: 'SCL', port: 'a', pin: 11, pinNameOnTestBoard: 'J5.3' }

];

Coast ribbonCableI2CPinsMaster = [

{ name: 'SDA', port: 'g', pin: 15, pinNameOnTestBoard: 'J5.6' },

{ name: 'SCL', port: 'd', pin: 7, pinNameOnTestBoard: 'J5.3' }

];

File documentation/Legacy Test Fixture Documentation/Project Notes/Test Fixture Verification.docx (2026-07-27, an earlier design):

# Test Vector

# Verification by testing a Golden Board

Place the Golden M1-3200 board into the test fixture and latch the test fixture cover.

Make sure the front panel Green status LED is On.

Activate SW debug mode by pressing Control M. The debug messages will be printed on the screen.

Start the ICT test by clicking ICT test Led.

[2024-03-01 00:18:43] [3023200040] info: Commission board

[2024-03-01 00:18:44] [3023200040, ict] error: M1-3200 Ethernet jack is not plugged. Check connection and retry the test.

# Step 2: Ground Pins Validation

Remove the Golden Board from the test fixture.

Open console on the Test Fixture PC. The console icon is located on the desktop.

Run the following command in the console

#picocom -b 115200 /dev/ttyACM0

For every test point in the table below below run the command

getiopin 16

The result will be

{"cmd": "getiopin", "status": true, "value": 2.603678 }

Make sure the status is true, and the value is above 2.5 (i.e. 2.5V)

M1-3200 | Io Pin Number | Best | Name | Voltage Level | Tolerance
PP J5.23 | 16 | TB J J5.23 | Ribbon Ground | < 2.5V | 5%
PP J5.25 | 17 | TB J J5.25 | Ribbon Ground | < 2.5V | 5%
PP J5.20 | 18 | TB J J5.20 | Ribbon Ground | < 2.5V | 5%
PP J5.22 | 19 | TB J J5.22 | Ribbon Ground | < 2.5V | 5%
PP J5.24 | 20 | TB J J5.24 | Ribbon Ground | < 2.5V | 5%
PP J5.26 | 21 | TB J J5.26 | Ribbon Ground | < 2.5V | 5%

If all test points pass the test the test is PASSED.

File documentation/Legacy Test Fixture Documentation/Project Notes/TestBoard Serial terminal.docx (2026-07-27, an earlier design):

The Custom Test Board can be controlled over serial terminal.

Teensy USB connection to the PC is required for. The Serial terminal can be started on Test Fixture PC since Teensy 4.1 is connected to by default.

#picocom -b 115200 /dev/ttyACM0

To exit picoohm press keys: Ctrl + A + X

Please note that Serial terminal will not “Echo” any typed character, therefore when you type the will be no characters in the terminal. This is done so the SW can use these commands in the script mode. Run the command below to enable Echo

Type

term

Followed by Enter

Make sure to reset the board before executing Test Fixture SW because term mode is not compatible with the automated testing mode.

Now Execute command

LenelS2>help

This will display all available commands.

The Table 1 below lists all commands. Do not use commands in Red.

Table 1: commands
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

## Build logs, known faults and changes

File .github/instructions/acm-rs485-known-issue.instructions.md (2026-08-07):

---
description: Use when working in components/acm-testboard-fw on RS485 reader behavior, watchdog resets, or Teensy runtime loop diagnostics.
applyTo: components/acm-testboard-fw/**
---

## Current Confirmed Bench Facts

- Reader task has a 1 ms cadence and echoes incoming serial bytes immediately when available.
- Previously tested forcing RS485 termination enable did not resolve the self-sustaining retransmission behavior.
- Cable-length reflection timing was already ruled out as the primary cause for the observed 1 kHz pattern.
- Boot-time watchdog loop risk exists if long init steps run before regular watchdog servicing.

## Guardrails

- Do not reintroduce already disproven single-cause explanations without new bench evidence.
- Separate observed behavior from root-cause inference.
- When proposing fixes, include how to verify on bench (scope/serial/log evidence).
- Keep changes minimal and reversible until bench validation confirms mechanism.

## Validation Expectations

For each proposed fix, define:
1. expected observable change
2. measurement point or command output to confirm
3. rollback criteria if behavior worsens

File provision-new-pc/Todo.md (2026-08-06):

# Provisioning Security Todo

Open items found during review on 2026-08-05, to address before migrating this repo off `lbuchman`'s personal GitHub.

## Secrets committed to git (must be rotated, not just removed)

- `provision-new-pc/setup/id_rsa` — deploy SSH private key, shared across every fixture PC. Tracked in git since commit `f3b2f7a`. Treat as compromised regardless of any future repo cleanup.
- `provision-new-pc/setup/cloud.key` — `autossh.service` reverse-tunnel private key (target -> `relay.sputnik-em.com`), also shared across every fixture PC. Tracked in git alongside `id_rsa`. Replacement plan not yet decided.
- `provision-new-pc/setup/setup.sh` — hardcodes live Azure SAS tokens (firmware blob URLs + `firmwareManifestUrl`) with `se=2036-08-01` expiry, written verbatim into every target's `/etc/m1platform/config.json`.

## Design questions, not yet decided

- Replace the one-shared-keypair-for-all-fixtures model with a unique keypair generated per fixture PC (reduces blast radius, allows per-PC revocation).
- Decide what happens to `cloud.key` / the reverse-tunnel model — unresolved.
- Move the SAS tokens in `setup.sh` out of the script into an out-of-band input (same pattern as `azureStorage.json`) instead of hardcoding them.

## Before any repo migration

- Rotate `id_rsa`, `cloud.key`, and the embedded SAS tokens — old values must be treated as burned, independent of any git history cleanup.
- Purge `id_rsa`, `cloud.key`, and the historical SAS-token commits from git history (e.g. `git filter-repo`/BFG) — deleting the files in a new commit alone does not remove them from history.

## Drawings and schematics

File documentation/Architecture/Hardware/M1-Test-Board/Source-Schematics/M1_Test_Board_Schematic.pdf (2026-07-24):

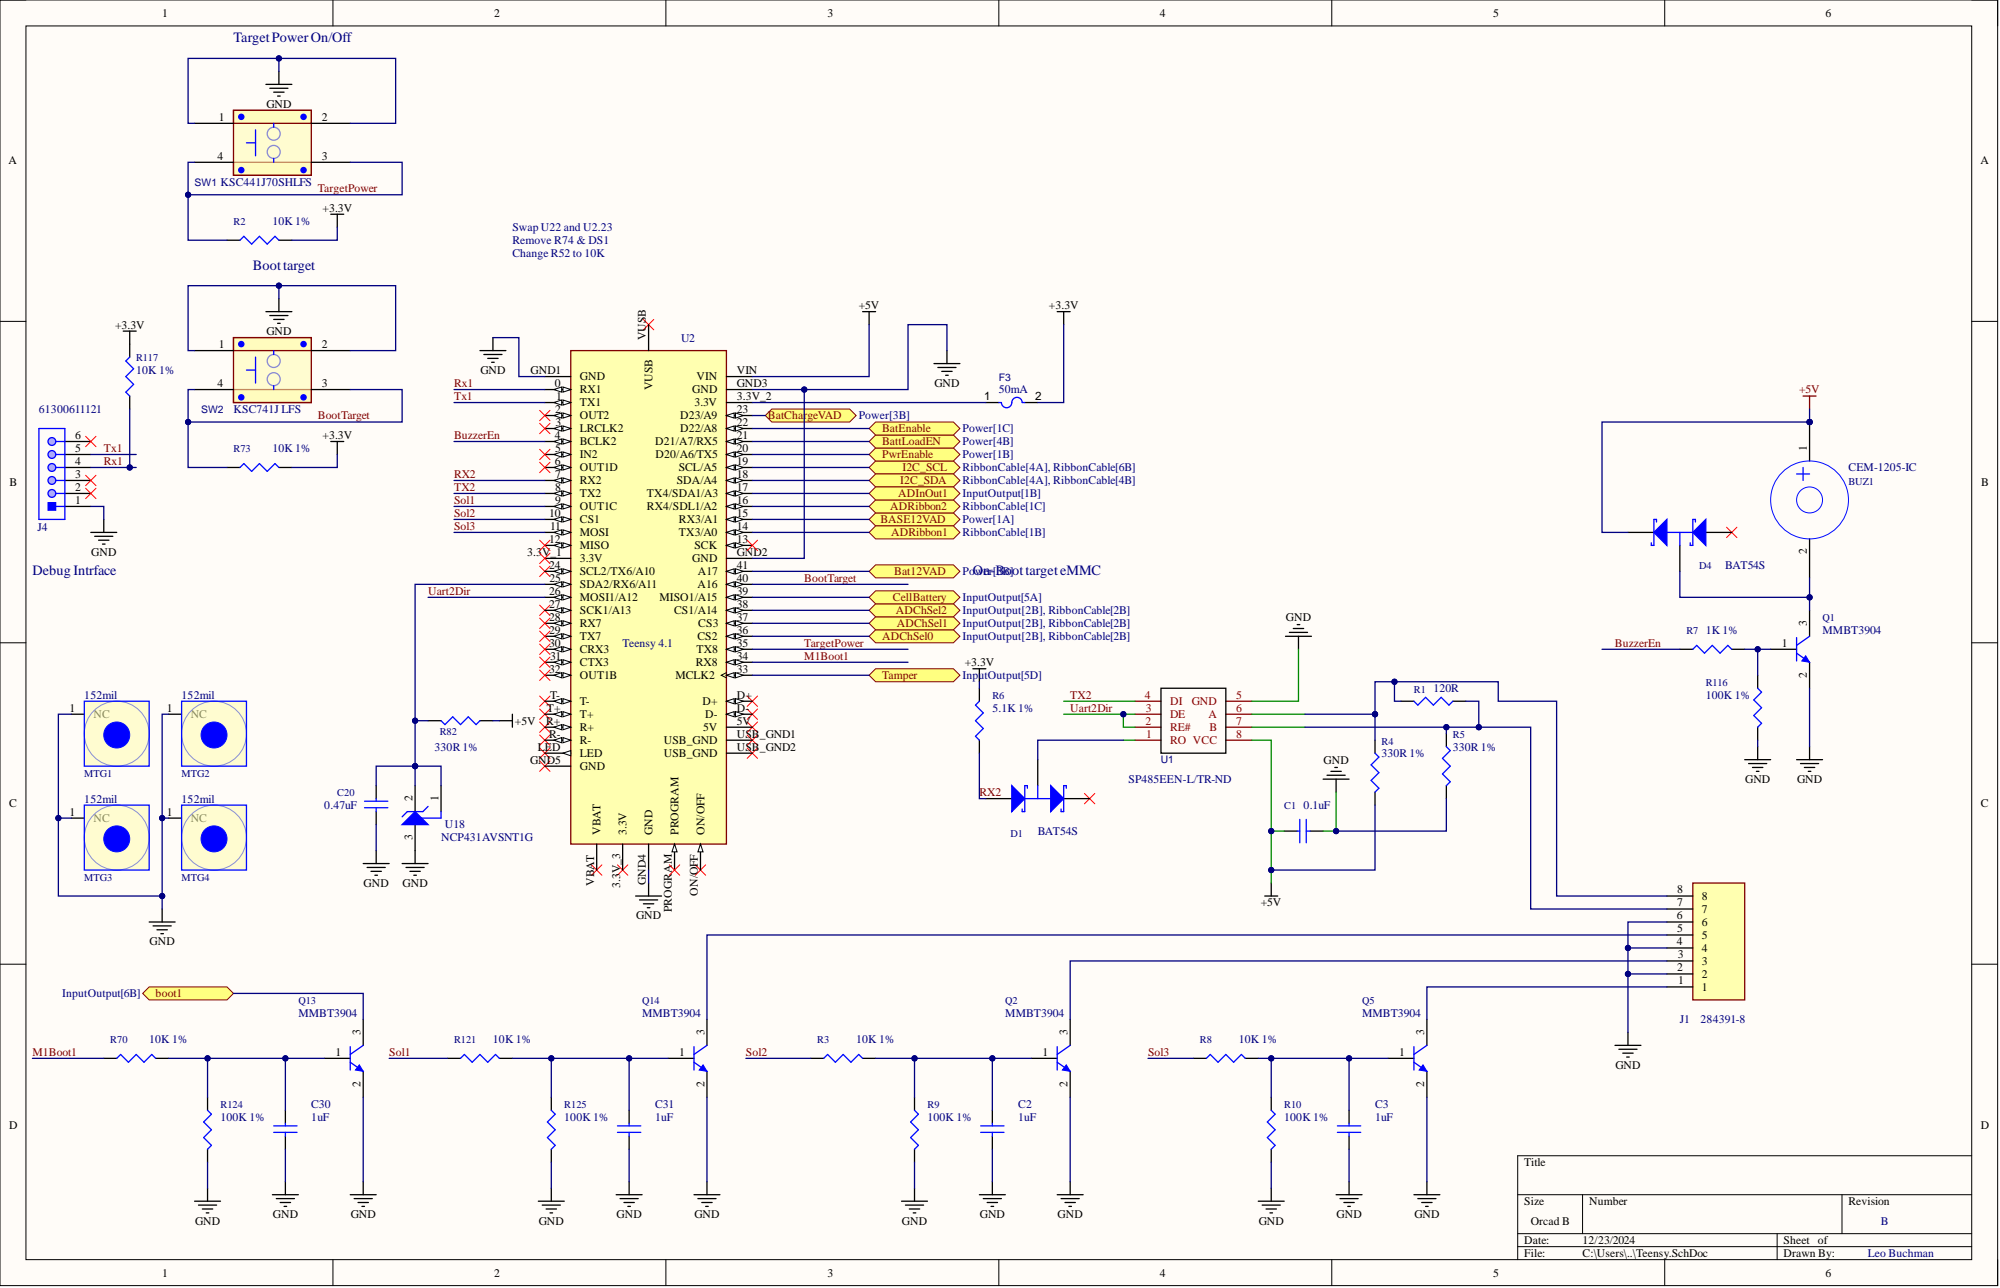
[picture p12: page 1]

Target Power On/Off

ON/OFF

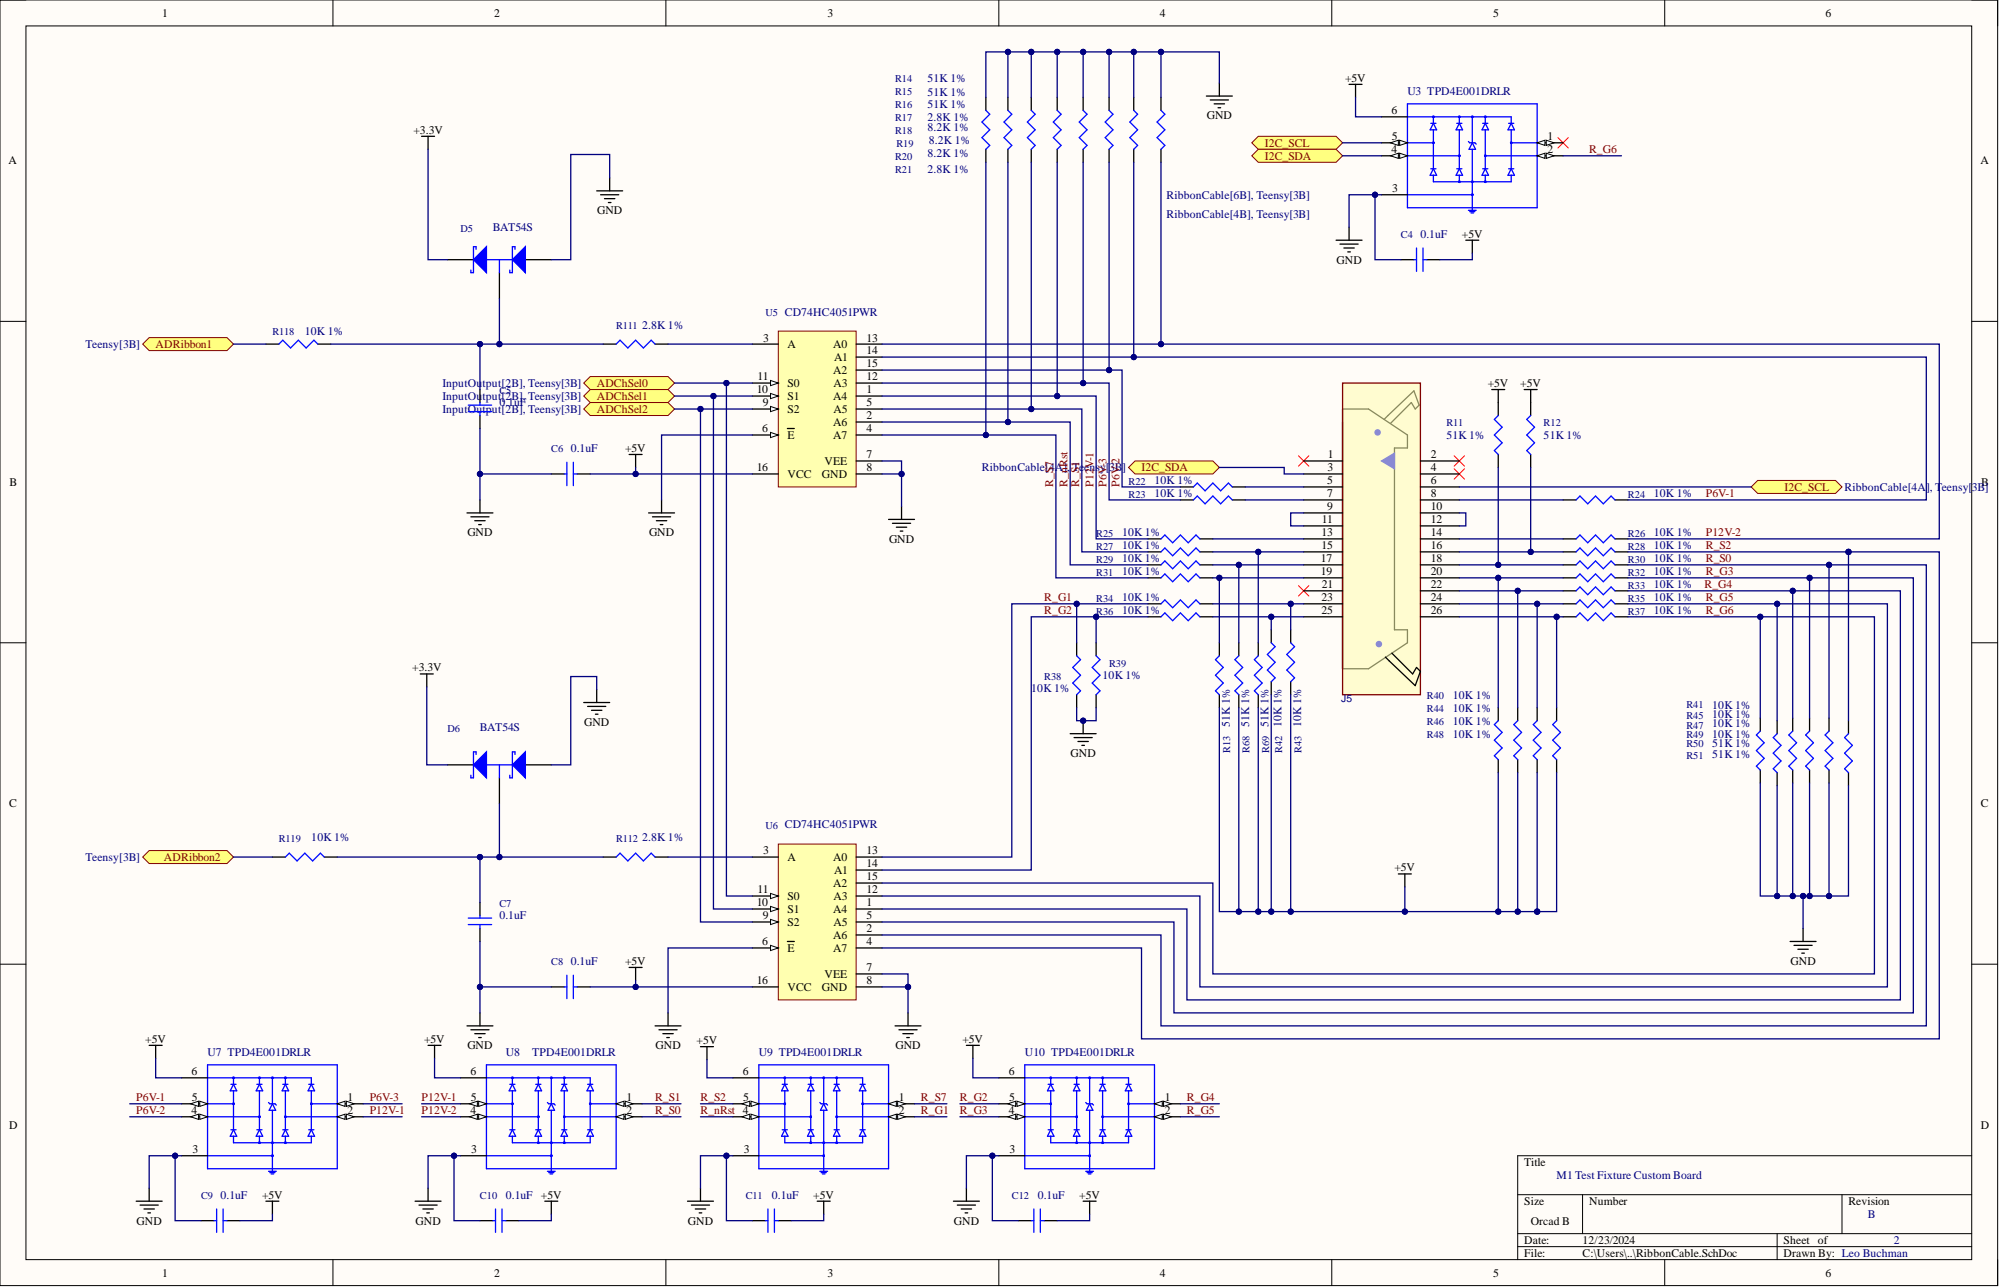
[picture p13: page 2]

Title
M1 Test Fixture Custom Board

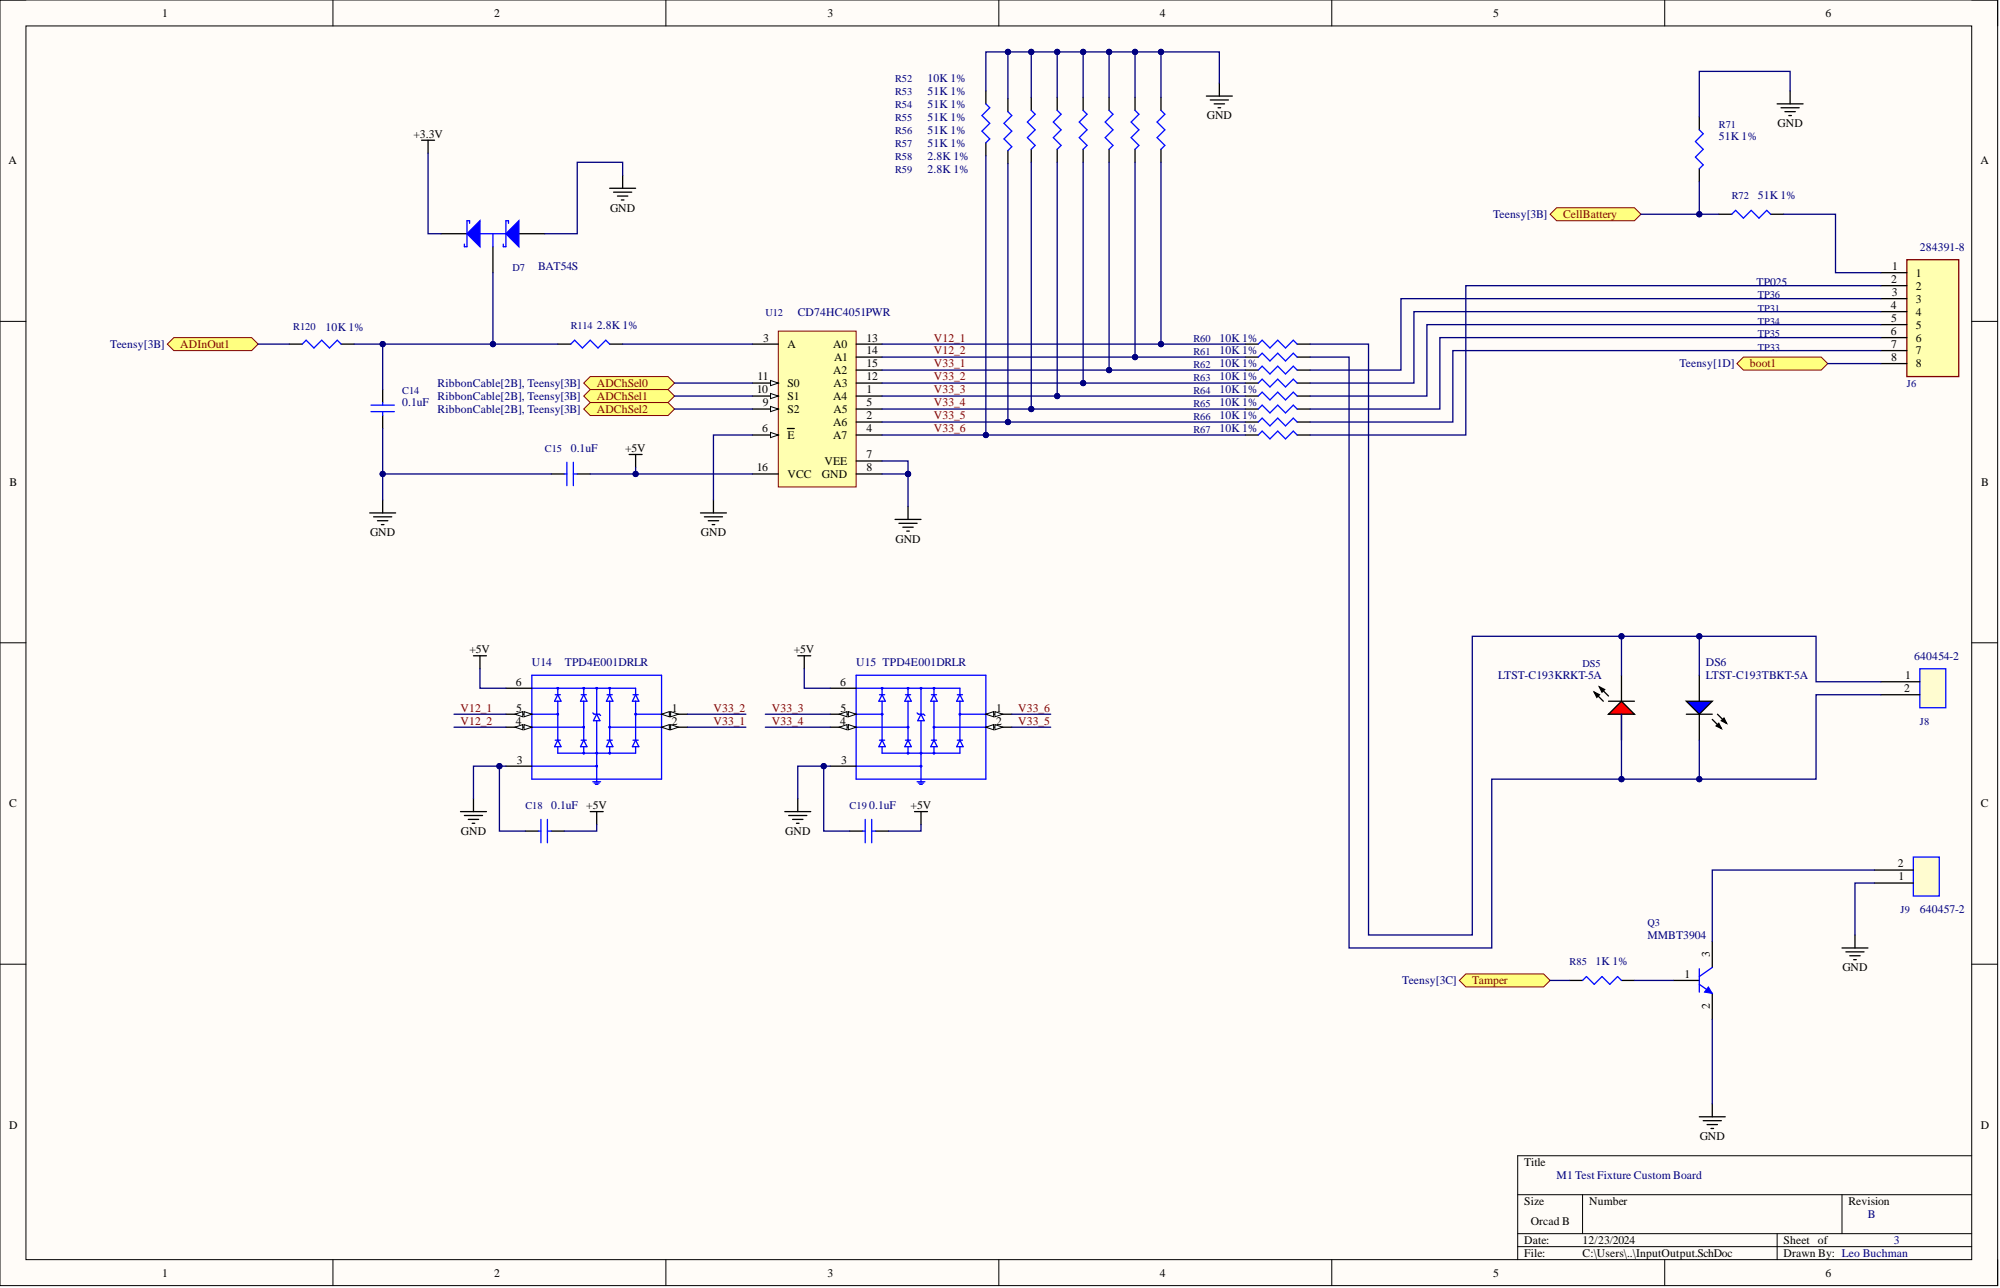
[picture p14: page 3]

TP36 | 3 3
TP31 | 4 4
TP34 | 5 5
TP35 | 6 6

7 7
8 8

Title
M1 Test Fixture Custom Board

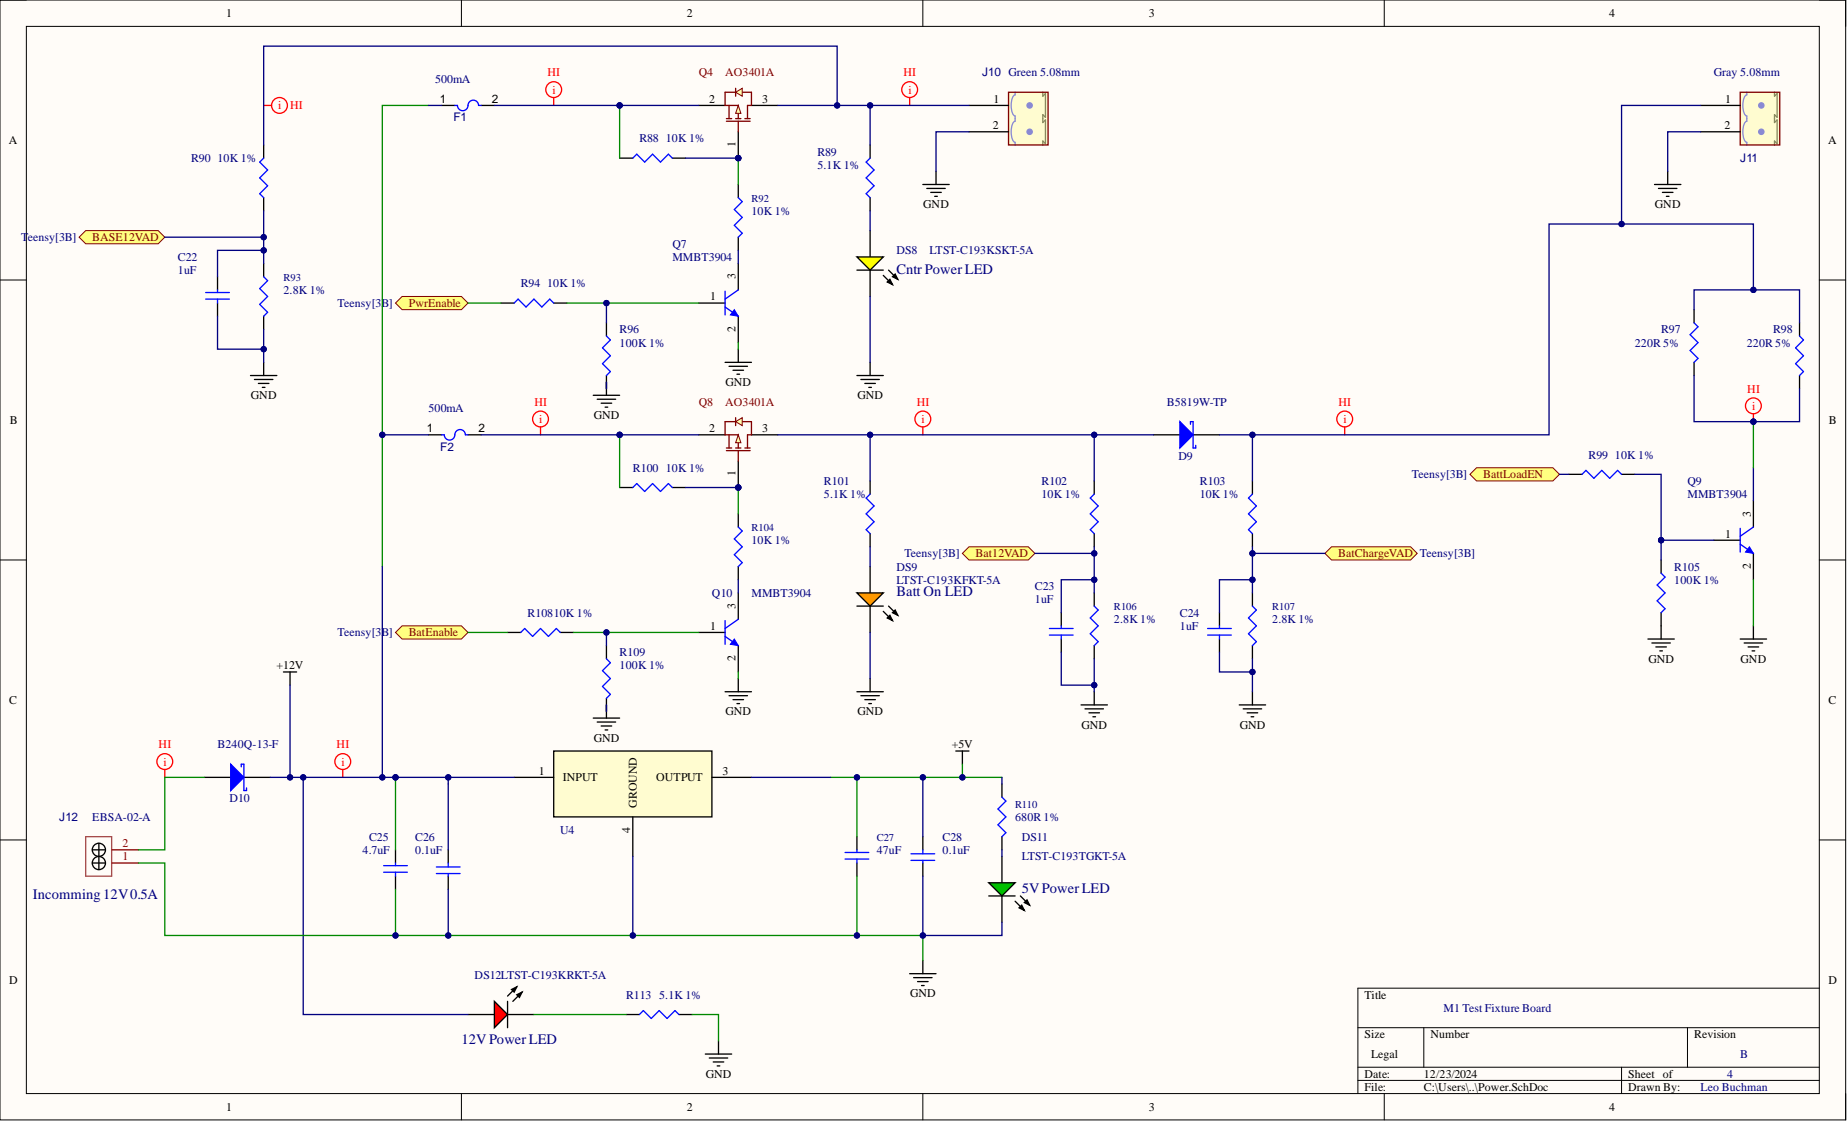
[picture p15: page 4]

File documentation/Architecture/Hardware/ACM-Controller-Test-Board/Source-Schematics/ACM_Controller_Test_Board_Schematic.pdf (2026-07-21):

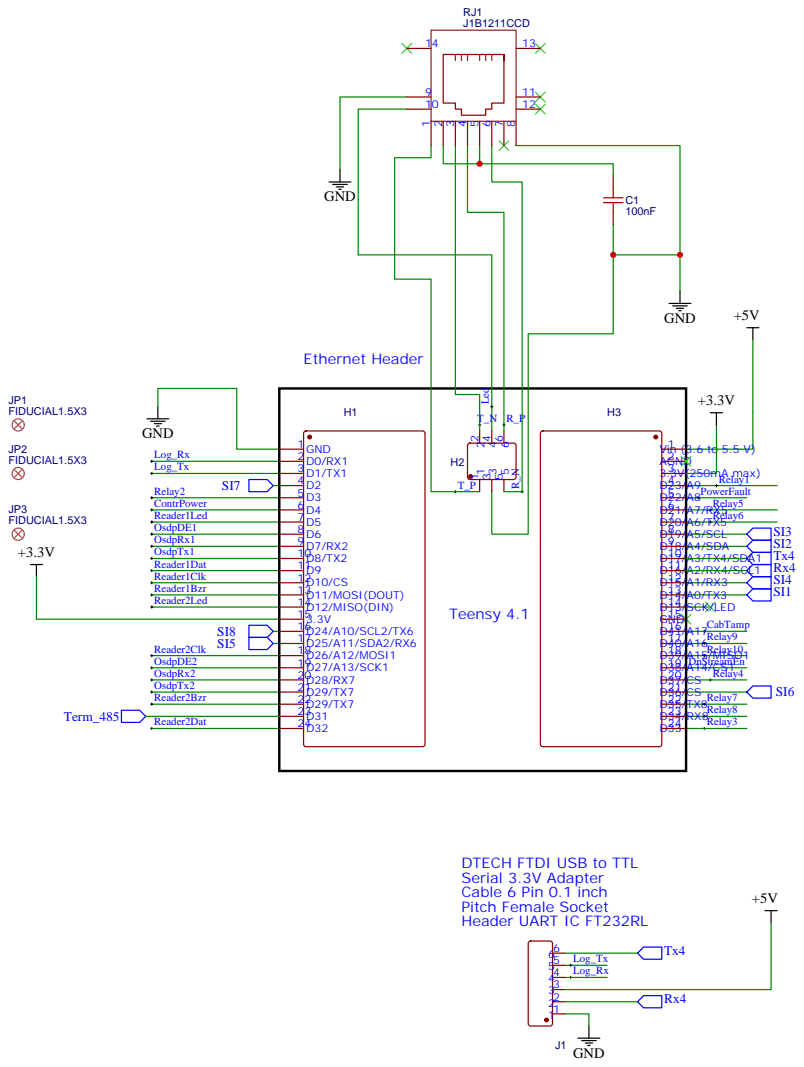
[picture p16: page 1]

DTECH FTDI USB to TTL
Serial 3.3V Adapter
Cable 6 Pin 0.1 inch
Pitch Female Socket
Header UART IC FT232RL

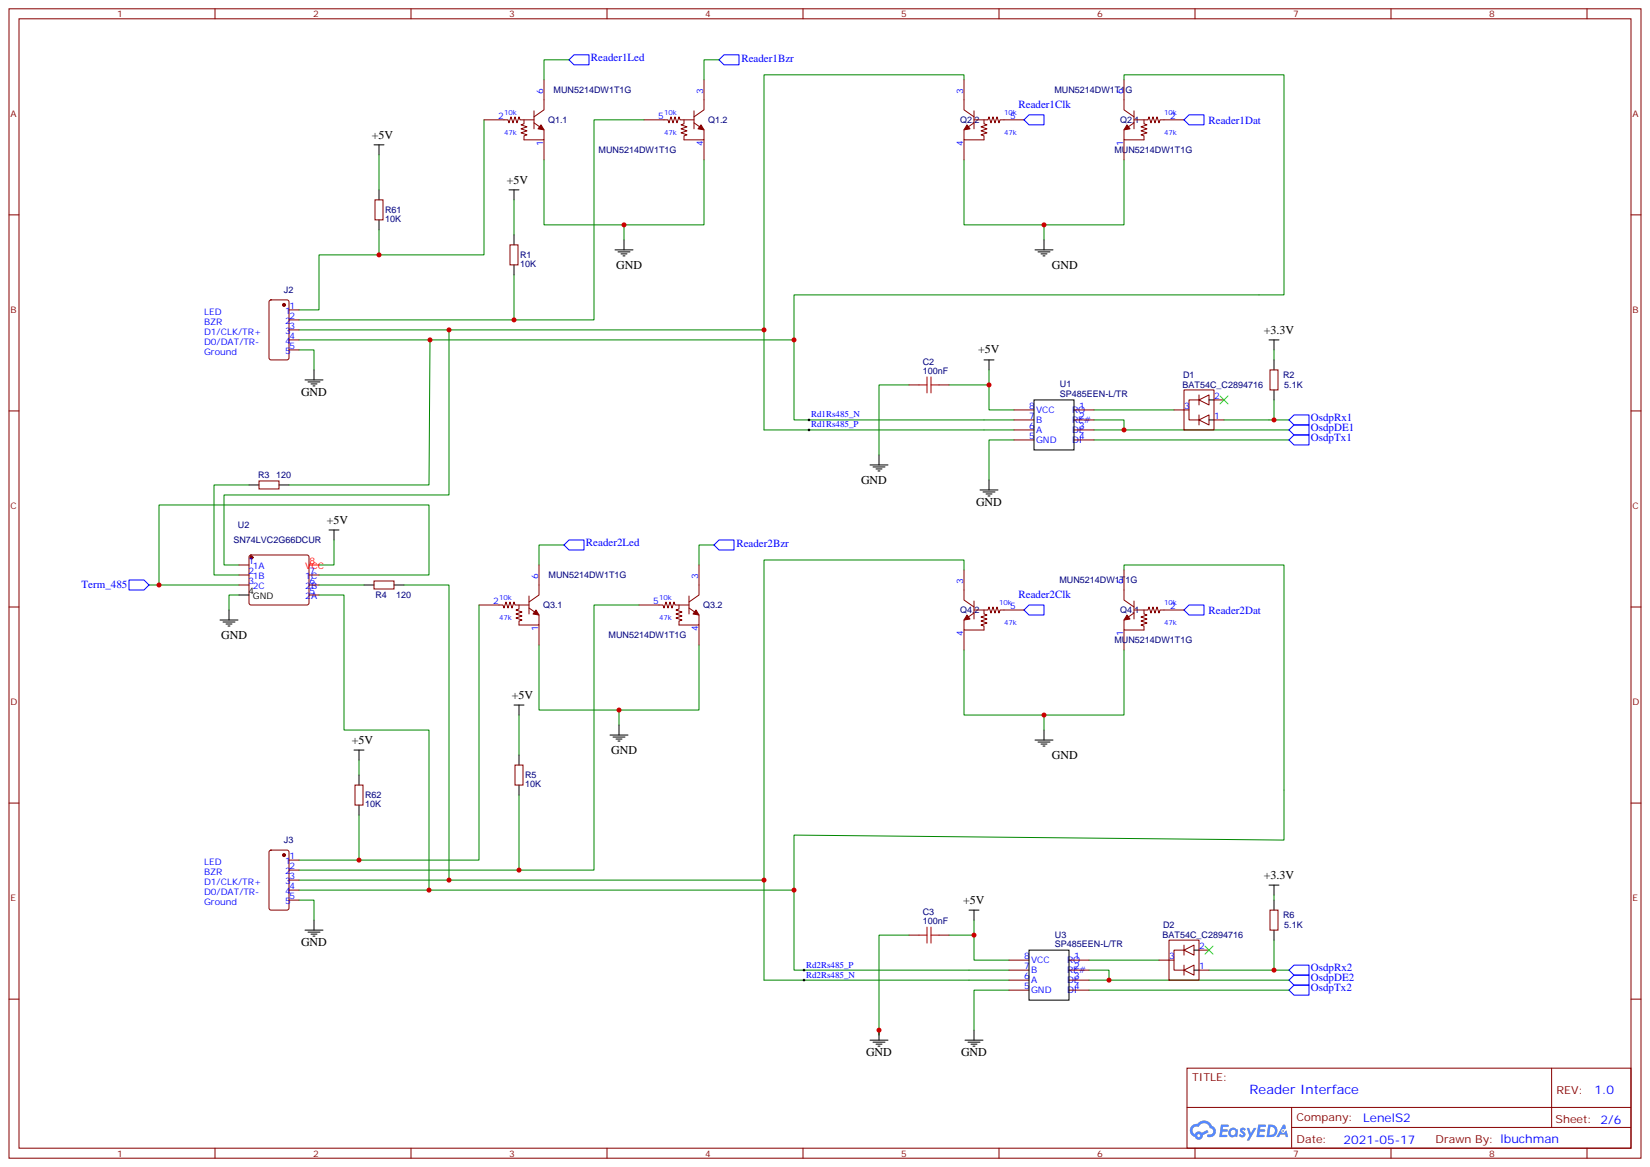
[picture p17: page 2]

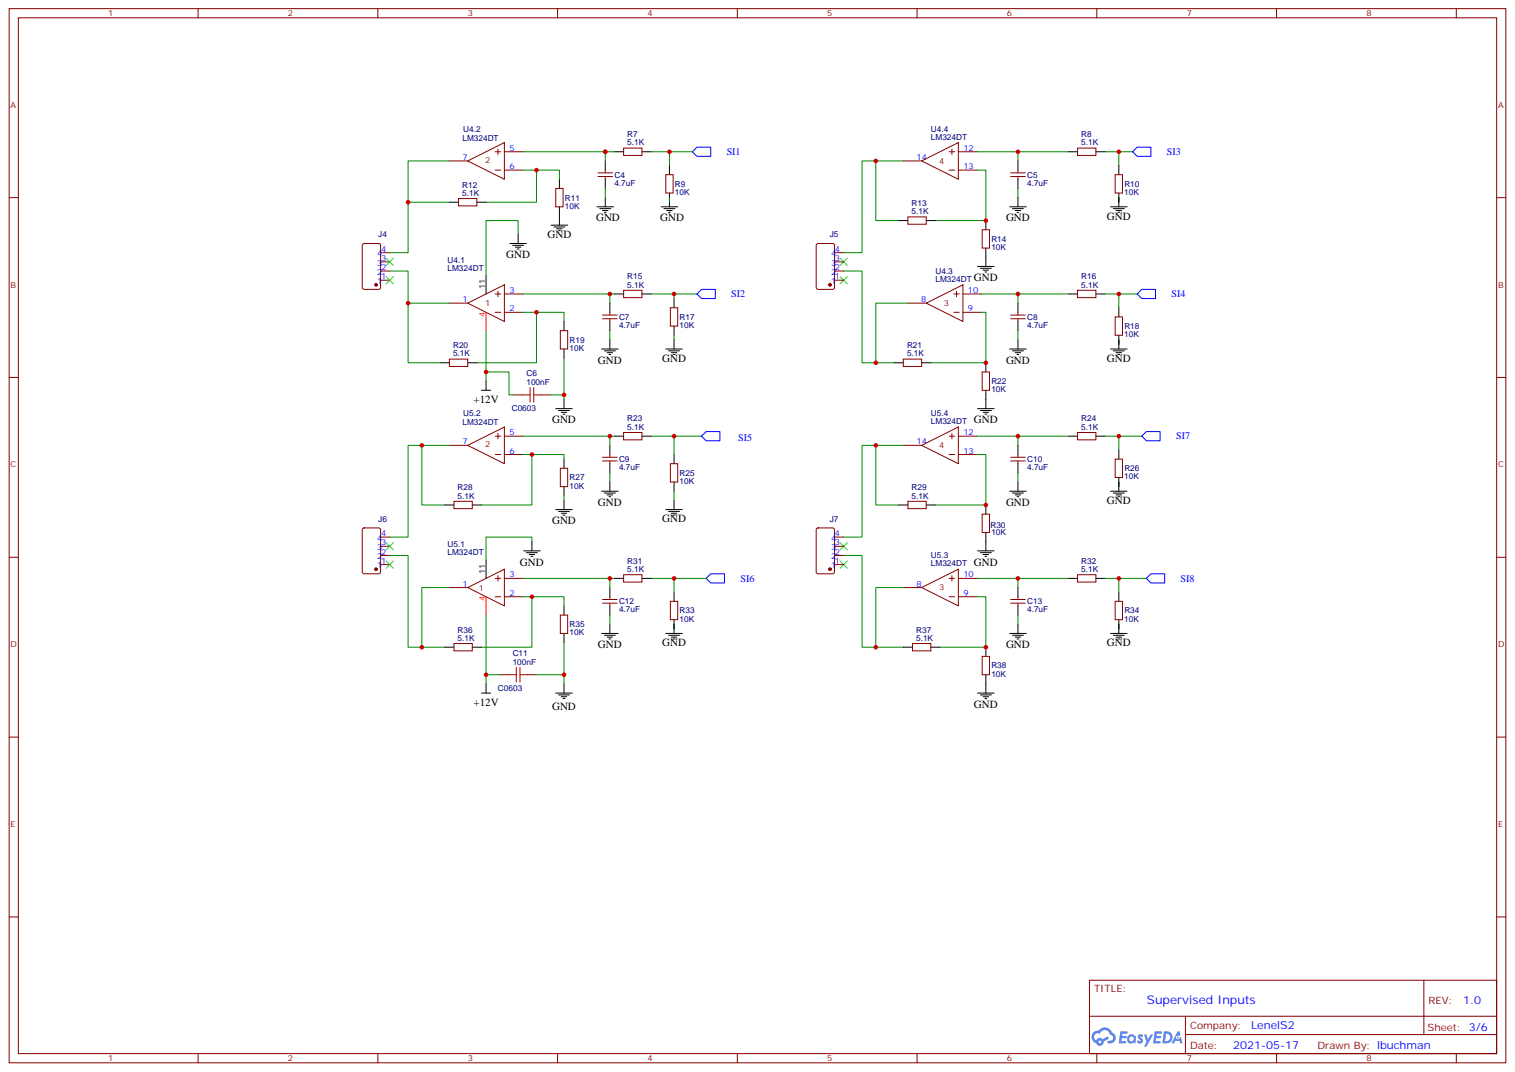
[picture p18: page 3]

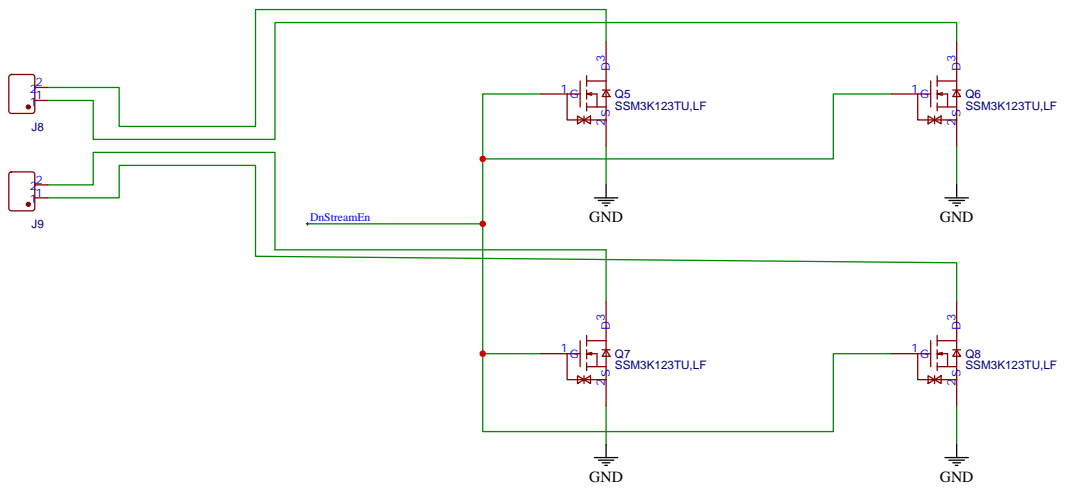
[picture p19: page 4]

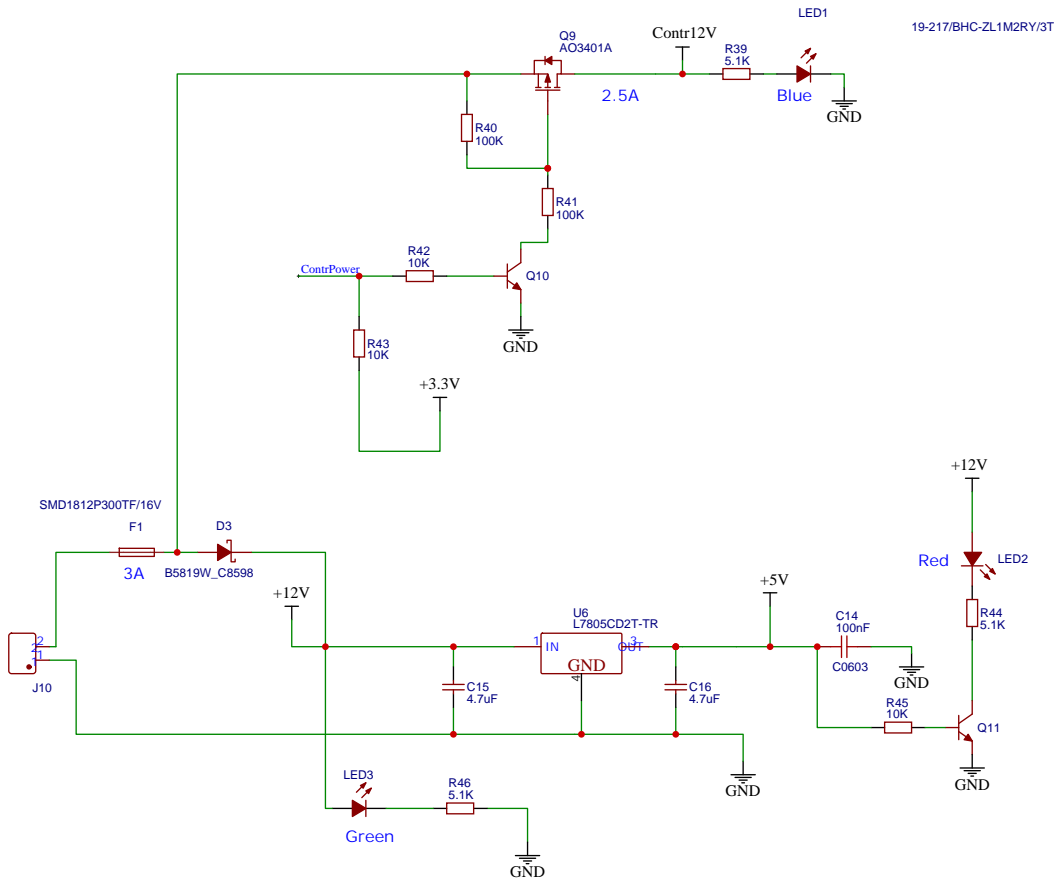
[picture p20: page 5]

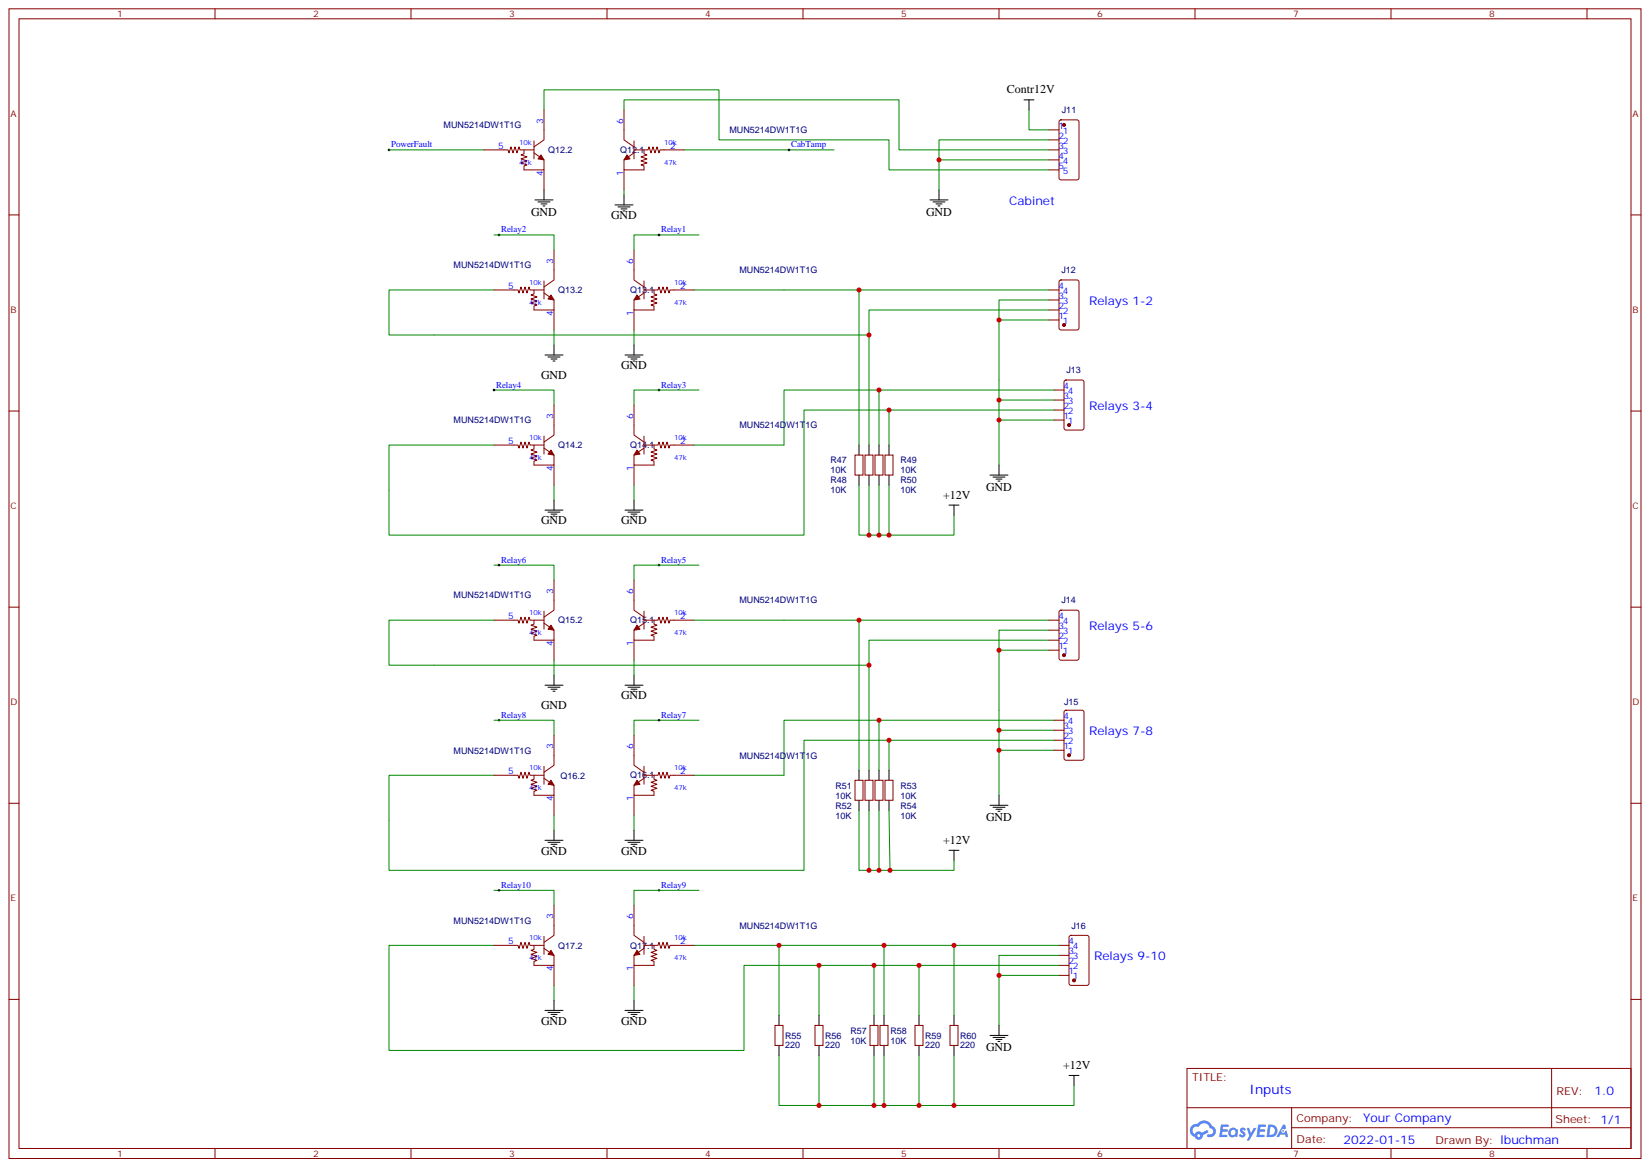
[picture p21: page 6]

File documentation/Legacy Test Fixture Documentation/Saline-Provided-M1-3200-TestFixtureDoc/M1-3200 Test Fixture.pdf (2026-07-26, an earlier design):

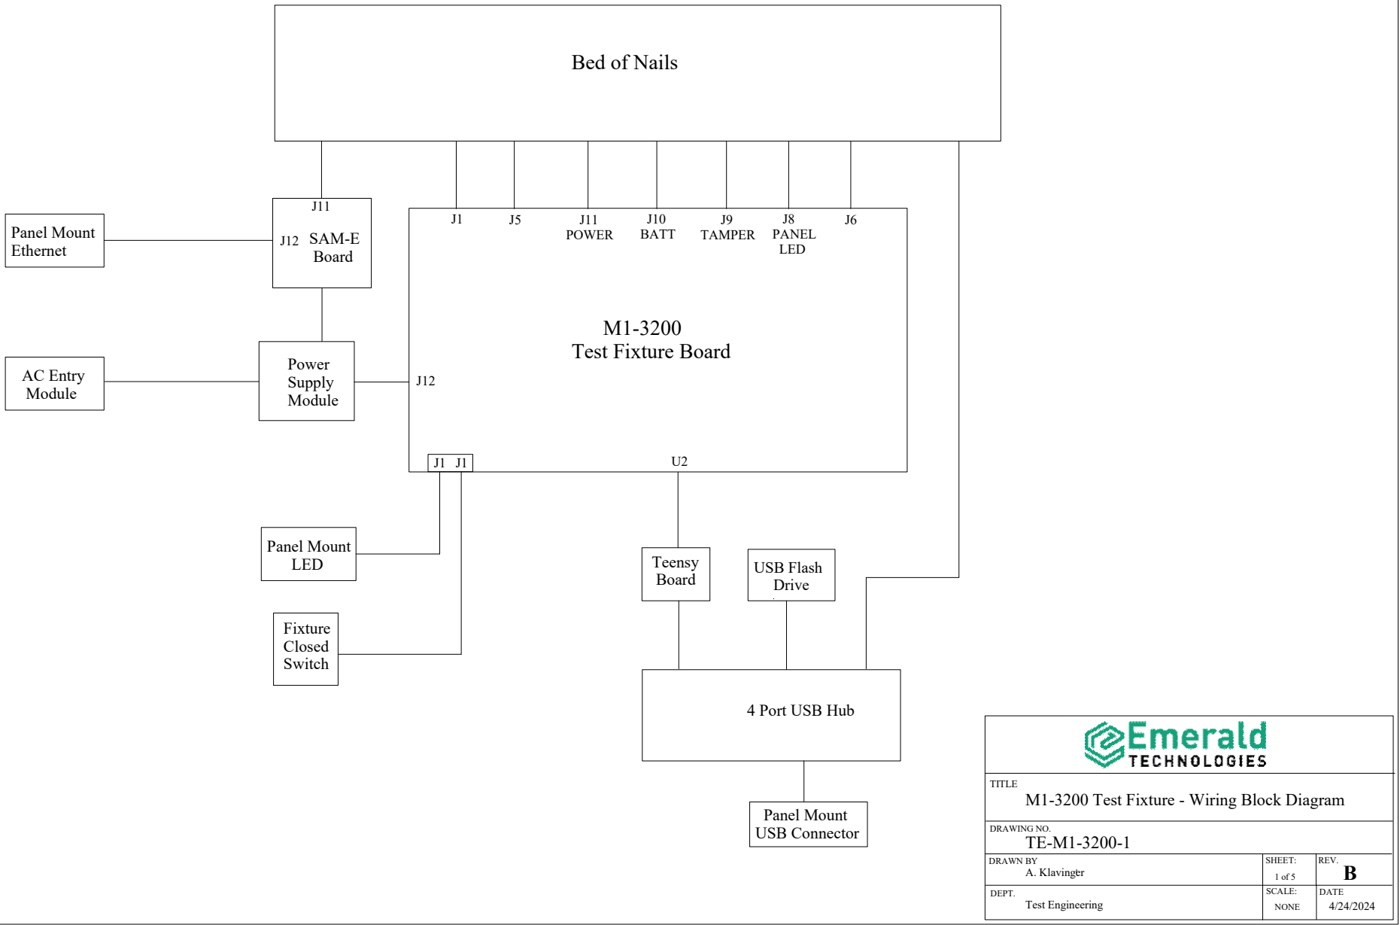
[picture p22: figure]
TITLE; REV.; DATE; DRAWN BY; DEPT.; A. Klavinger; Test Engineering; SCALE:; NONE; SHEET:; DRAWING NO. TE-M1-3200-1; USB Flash Drive; 4 Port USB Hub; Panel Mount USB Connector; Teensy Board; Fixture Closed Switch; Panel Mount LED; AC Entry Module; Panel Mount Ethernet; SAM-E Board; POWER; J10 BATT; J9 TAMPER; J8 PANEL LED; Power Supply Module; Bed of Nails; M1-3200 Test Fixture Board

M1-3200 Test Fixture - Wiring Block Diagram

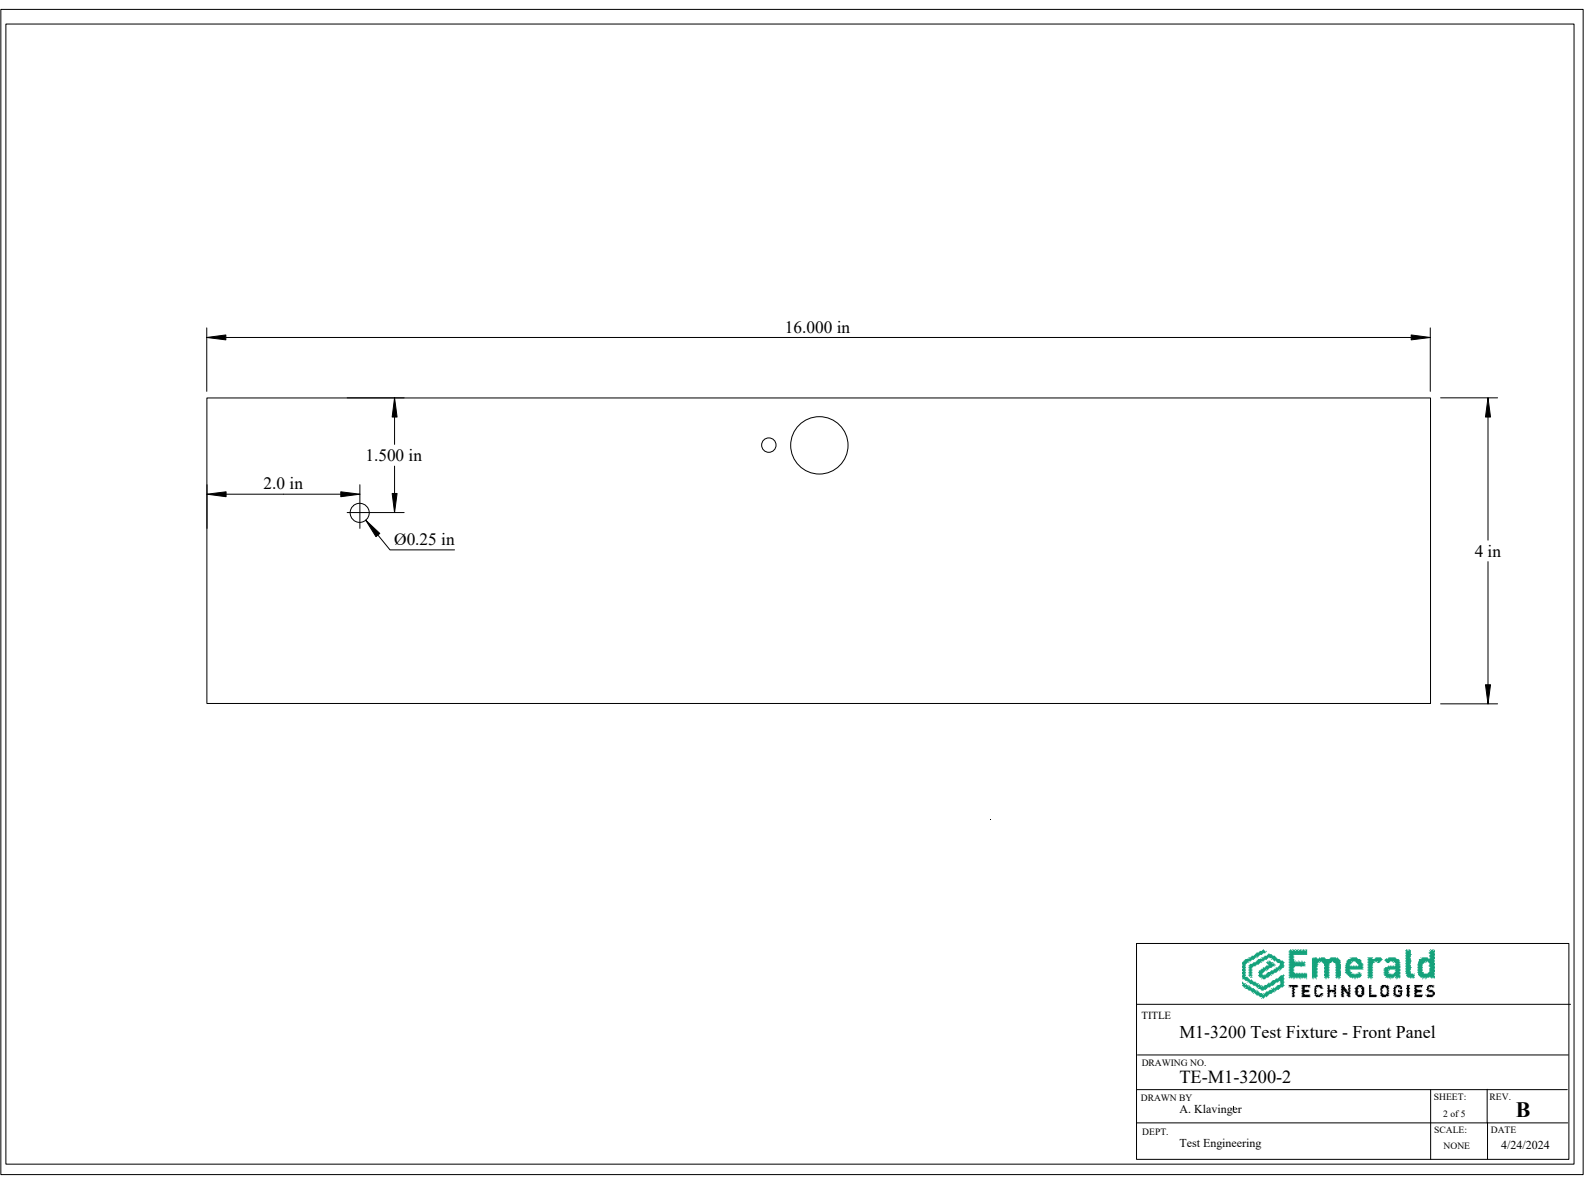
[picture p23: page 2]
REV.; DRAWN BY; SHEET:; DRAWING NO. TE-M1-3200-2

TITLE
M1-3200 Test Fixture - Front Panel

REV.; DRAWN BY; SHEET:; DRAWING NO. TE-M1-3200-3; DETAIL B; DETAIL A

TITLE
M1-3200 Test Fixture - Rear Panel

REV.; DATE; DRAWN BY; DEPT.; A. Klavinger; Test Engineering; SCALE:; SHEET:; DRAWING NO. TE-M1-3200-4; Power Supply; Test Board; SAM-E Board; AC Entry; Module; Panel Mount; Ethernet; Panel Mount USB Connector; Panel Mount LED

TITLE
M1-3200 Test Fixture - Component Layout

REV.; DATE; DRAWN BY; DEPT.; A. Klavinger; Test Engineering; SCALE:; SHEET:; DRAWING NO. TE-M1-3200-5; Bend Point; AC Power Safety Shield and Bracket; Fixture Closed Switch Bracket

1/16 in. FR4 Material
Mounted on frame with
double sided tape

Aluminum Angle Stock

TITLE
M1-3200 Test Fixture - Brackets

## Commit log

2026-07-19 Document STM32MP1 ICT component
2026-07-19 Record STM32MP1 component publication
2026-07-20 Restore point: checkpoint all current changes
2026-07-21 Add Mercury Teensy RS485 investigation notes, update AI calibration rules, add schematics
2026-07-25 Add AI platform state framework and captured runtime snapshot
2026-07-25 Switch AI state restore to AI-only mode (no host mutation)
2026-07-26 Update platform docs, diagrams, and legacy references
    [BOM-M1-3200-1.xlsx, Bill of Materials.xlsx, Drill-M1-3200-1, M1 Test Fixture Drill Chart - Push Plate.xlsx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]
2026-07-26 Replace embedded Altium repo with normal tracked folder
    [Bill of Materials.xlsx, Fabrication Testpoint Report for M1-Test-Board.csv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]
2026-07-26 Add ACM Mercury test board manufacturing files to legacy docs
    [BOM_PCB_2022-04-08.csv, BOM_PCB_2022-04-08.xlsx, Digi-Key.xls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]
2026-07-28 Refresh checked-in fixture snaps (setup/snaps/m1client.snap, m1tfd1.snap)
    Rebuilt via scripts/build-snaps.sh from current component commits
    (tfcroncli 947f598 -> m1client, m1tfc e844ba0 -> m1tfd1) and copied
    into setup/snaps/, which deploy.sh's get_snap() already searches
    first (ahead of artifacts/snaps/ and components/). This makes deploy.sh
    use these checked-in snaps by default instead of depending on an
    ephemeral local artifacts/snaps/<timestamp>/ build output directory.
    Removed the now-redundant setup/snaps/.gitkeep placeholder.
2026-07-29 Auto-detect ethernet interfaces in setup.sh and update fixture setup
    - setup.sh: auto-detect DHCP-uplink and static-fixture wired ethernet
    interface names via 'ip link' instead of hardcoding enp0s31f6/enp1s0,
    substitute into 01-network-manager-all.yaml netplan template
    - 01-network-manager-all.yaml: switch renderer to networkd (Ubuntu
    Server default), use __ETH_DHCP_IF__/__ETH_STATIC_IF__ placeholders,
    drop hardcoded wifi block
    - setup.sh: add passwordless sudo for lenel, per-type (m1/mnp)
    PRODUCTNAME/FWDIR/LAYOUTFILEPATH vars, snap package renames
    (m1tfd1 -> m1tfc/m1tfc-rest-server/gui-react), calibration.json
    field rename (minVoltageUsed -> minVoltageAged) + scale field
    - DEP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
2026-07-30 Add teensy_loader_cli headless flashing tool to setup.sh
    - Bundle teensy_loader_cli binary (from mnptestf5:/usr/sbin) in setup/
    - setup.sh: install libusb-0.1-4 (runtime dep) and copy the binary to
    /usr/sbin/teensy_loader_cli during fixture provisioning
2026-07-30 Add factory server architecture design doc
    - Proposes replacing Azure Blob Storage with a local, self-contained
    on-prem Factory Server (m1-factory-hub) for logs/secrets/firmware/MAC
    management, keyed by board serial number
    - MySQL backend, plain filesystem storage, REST API, web dashboard
    - Fixtures become stateless clients (no local SQLite) - m1tfc calls the
    hub directly for board records/secrets/MAC allocation
    - Azure Storage retained only as a daily, conditional, off-site backup
    target (disaster recovery), not on the production critical path
    - Documents existing autossh reverse-SSH relay pattern for remote support
2026-08-01 Refine firmware publish workflow and setup flow
2026-08-03 added mnplus, split BOM for LenelS12 supplied parts
    [BOM-M1-3200-1.xlsx]
2026-08-05 Refactor build pipeline and Teensy programming flow
2026-08-05 prog-teensy: apply dual-attempt flash logic to m1tb board
2026-08-06 Rename doc/ to documentation/; fix README links
    The doc/ folder was renamed to documentation/ outside git and showed up
    as deletions + an untracked folder; re-staged with git add -A so the
    identical-content files are recorded as renames. Update README.md's
    three doc/... links to documentation/... to match.
    [BOM-M1-3200-1.xlsx, BOM_PCB_2022-04-08.csv, BOM_PCB_2022-04-08.xlsx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]
2026-08-06 Reorg provisioning docs into provision-new-pc/; document PIN gate defaults
    Rename provisionNewPC/ -> provision-new-pc/, ReadmeConfig.md ->
    CONFIGURATION.md, PUBLISH.md -> scripts/publish-fw.md.
    CONFIGURATION.md: document the operator UI PIN gate (config.json is the
    only source, m1-rest-server has no built-in default, PIN is a UI
    convenience not a network access control).
    setup.sh: set default productionPassword/debugPassword to 1234/4321.
2026-08-06 Remove root-level STM32MP1-ICT-FIRMWARE.md
    Superseded by documentation/BuildPC/STM32MP1-ICT-FIRMWARE.md (moved
    there earlier; this stale root copy was left behind).
2026-08-06 Rename all-caps doc filenames to Title-case; expand deploy prerequisites; fix deploy.sh artifact paths
    - README.md -> Readme.md (root, documentation/, documentation/BuildPC/, documentation/Cloud-Deployment/, scripts/)
    - CONFIGURATION.md -> Configuration.md, DEPLOY.md -> Readme.md (provision-new-pc/)
    - Update cross-references to renamed files
    - provision-new-pc/Readme.md: document component clone/update and build.sh prerequisites
    - provision-new-pc/deploy.sh: fix artifacts/components path resolution via new ROOT_DIR (broken after move into provision-new-pc/)
2026-08-06 prog-teensy.sh: resolve teensy_loader_cli via PATH, echo commands before running
2026-08-06 Wire m1-fixture-agent into build/clone/update/install/publish scripts
2026-08-07 Update provision-new-pc/Readme.md: recommended PC specs, commissioning steps, dev PC build/publish/deploy flow
2026-08-10 build.sh: fix update_manifest guard to catch 0-byte manifest files
    jq -e 'type == "array"' exits 0 on truly empty input (jq's zero-input
    special case), so the guard using [[ ! -f ]] never reset an empty
    manifest to []. Use [[ ! -s ]] instead to catch missing AND empty files.
